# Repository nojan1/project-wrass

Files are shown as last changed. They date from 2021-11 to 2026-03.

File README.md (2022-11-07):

# Project Wrass

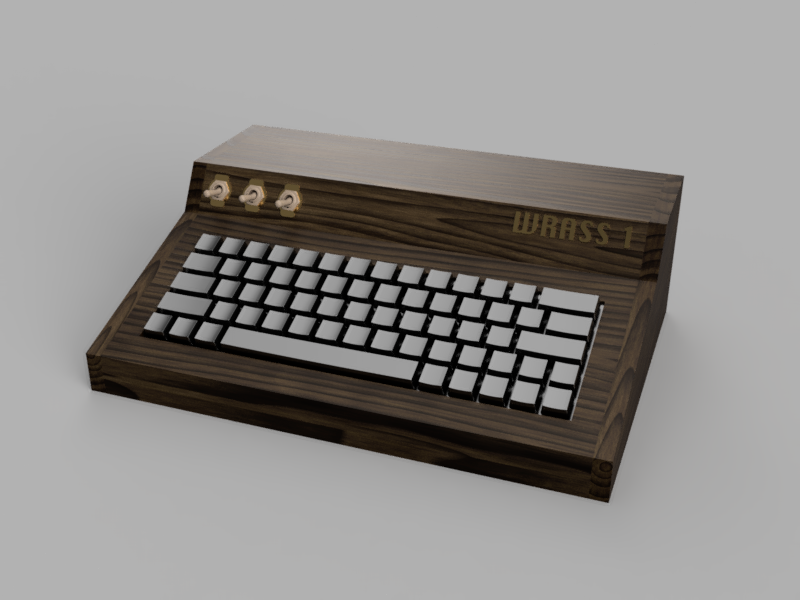
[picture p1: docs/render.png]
render


The purpose of Project Wrass is to develop the **Wrass 1**.

A 6502 based computer having the following specs.

* W65C02 running at 2Mhz
* Bankable RAM giving a total of approx 300KB of usable memory
* Expansion bus for up to 16 devices

> **Future specs**:  
>
> * VGA output of 640x480 with 256 colors
> * IO Card with W65C22 Vias and support for SPI
> * Support for SD cards on IO card
> * 8Mhz CPU clock speed
> * Global scroll registers for video
> * Sprites
> * 3 channel sound synthesizer

## Software

The 16KB ROM is bankable using an external switch. This allows the computer to run "2 sets" of software.

The existing one is a simple homebrew "monitor" giving access to simple read, write and jump commands.

> **Future**:  
> Support enhanced basic

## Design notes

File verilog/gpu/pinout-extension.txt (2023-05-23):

+5   |  GND
+3.3 |  GND
IO0  |  EXTCLK
IO1  |  GND
IO2  |  LED1
IO3  |  LED2
IO4  |  Blue2
IO5  |  Blue1
IO6  |  Blue0
IO7  |  Green2
A0   |  Green1
CLK  |  Green0
A1   |  Red2
A2   |  Red1
RW   |  Red0
CS   |  VSync
RST  |  HSync

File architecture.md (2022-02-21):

Architecture
-------------

# Memory map

| Type | Start | End | Size |
| --- | ----- | ----- | ---- |
| RAM (1) | $0000 | $7FFF | 32k  |
| RAM (2) | $8000 | $9FFF | 8k |
| IO | $A000 | $BFFF | 8k |
| ROM | $C000 | $FFFF | 16k  |
| ------------------- | ----  | ----- | ---  |
| Screen (Write only) | $C000 | ??? | ?? |

# IO

The IO space region is a 8k byte range that is divided up into 16 different IO devices. This yields a total of 16 IO select lines having access to 512 bytes of address space each.

## IO Line Allocation

| Line | Device  | Lower Address | Upper Address |
| ---- | --- | --- | --- |
| 0 | IO Card | $A000 | $A1FF |
| 1 | GPU | $A200 | $A3FF |
| 2 | SOUND | $A400 | $A5FF |
| 3 | | $A600 | $A7FF |
| 4 | | $A800 | $A9FF |
| 5 | | $AA00 | $ABFF |
| 6 | | $AC00 | $ADFF |
| 7 | | $AE00 | $AFFF |
| 8 | | $B000 | $B1FF |
| 9 | | $B200 | $B3FF |
| 10 | | $B400 | $B5FF |
| 11 | | $B600 | $B7FF |
| 12 | | $B800 | $B9FF |
| 13 | | $BA00 | $BBFF |
| 14 | | $BC00 | $BDFF |
| 15 | | $BE00 | $BFFF |

# Screen

The framebuffer, tilemap and color attributes are stored in seperate RAM. It shares address space with ROM however since writing to the ROM is a no-op this action is repurposed to write to screen RAM. Note that that does make the Screen RAM write-only!

To access information about Screen stuff the IO space is used.

## Screen RAM Map (Character mode)

| Type | Lower Address | Upper Address |
| --- | --- | --- |
| Framebuffer | $C000 | $D2C0 |
| Color Attributes | $D2C1 | $E581 |
| Tilemap | $E582 | $ED81 |
| Colors | $ED82 | $EE02 |

### Framebuffer format

The framebuffer is composed of 80 * 60 bytes confirming to 80 columns and 60 rows layed out in row order. Each byte in the buffer matches a single tile in the tilemap. 

### Color Attributes

The color attributes are layed out in the same format as the framebuffer with the difference that each byte instead describes the color for the rendered tile. The lower 4 bits matches to 16 different colors for the background and the top 4 is the color for the foreground.

### Tilemap format

The tilemap is composed of 8 bytes per tile, coresponding to 8 rows. When converting to pixels it is simply 0 == pixel off, 1 == pixel on.

The example below would make a crappy 'A' when rendered.

```
byte 
 0:  0 0 0 0 0 0 0 0
 1:  0 0 0 1 1 0 0 0
 2:  0 0 1 1 1 1 0 0
 3:  0 1 1 0 0 1 1 0
 4:  0 1 1 0 0 1 1 0
 5:  0 1 1 1 1 1 1 0
 6:  0 1 1 1 1 1 1 0
 7:  0 1 1 0 0 1 1 0
```

## Screen RAM Map (Bitmap mode)

| Type | Lower Address | Upper Address |
| --- | --- | --- |
| Bitmap data format | $C000 | $E580 |
| Tilemap | $E582 | $ED81 |
| Colors | $ED82 | $EE02 |

### Bitmap data

The bitmap data is encoded in a 2bp and the screen resolution is reduced to 320x240.
The available colors are the first 4 in the color map.

Example:
```
  00_01_10_11 
```
Would translate to a row of 4 pixels as such:
```
<color 0><color 1><color 2><color 3>
```

## Colors format

The colors are a collection of 16 bytes each describing one of the 16 available colors. The format is: `xxRRGGBB`. Meaning 2 bit for each color and the 2 top bits are ignored.

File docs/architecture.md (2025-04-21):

Architecture
-------------

# Memory map

| Type | Start | End | Size |
| --- | ----- | ----- | --- |
| RAM (1) | $0000 | $7FFF | 32k |
| RAM (2) | $8000 | $9FFF | 8k |
| RAM (3) | $A000 | $BBFF | 7K |
| IO (1) | $BC00 | $BDFF | 512 bytes |
| IO (2) / RAM (4)  | $BE00 | $BFFF | 512 bytes |
| ROM (1) / RAM (5) | $C000 | $DFFF | 8k |
| ROM (2) / RAM (6) | $E000 | $FFFF | 8k |

The different areas marked RAM 3-5 can be switched off by modifying the hardware register located at memory address $0000. It has the following composition:

| Bit | Description |
| --- | --- |
| 0 | Enable RAM (4) |
| 1 | Enable RAM (5) |
| 2 | Enable RAM (6) |
| 3 | RAM (2) bank (bit 0) |
| 4 | RAM (2) bank (bit 1) |
| 5 | RAM (2) bank (bit 2) |
| 6 | RAM (2) bank (bit 3) |
| 7 | RAM (2) bank (bit 4) |

# IO

The IO space region is a 1k byte range that is divided up into 16 different IO devices. This yields a total of 16 IO select lines having access to 64 bytes of address space each. However only IO bank 1 is used by default, giving 8 lines of internal expansion. IO bank 2 is broken out to the user port on the side and will not be decoded,

## IO Line Allocation (1)

| Line | Device  | Lower Address | Upper Address |
| ---- | --- | --- | --- |
| 0 | IO Card | $BC00 | $BC3F |
| 1 | GPU | $BC40 | $BC7F |
| 2 | LCD | $BC80 | $BCBF |
| 3 | | $BCC0 | $BCFF |
| 4 | | $BD00 | $BD3F |
| 5 | | $BD40 | $BD7F |
| 6 | | $BD80 | $BDBF |
| 7 | | $BDC0 | $BDFF |

## IO Line Allocation (2)

IO lines for user expansion

| Line | Device | Lower Address | Upper Address |
| ---- | --- | --- | --- |
| 8 | | $BE00 | $BE3F |
| 9 | | $BE40 | $BE7F |
| 10 | | $BE80 | $BEBF |
| 11 | | $BEC0 | $BEFF |
| 12 | | $BF00 | $BF3F |
| 13 | | $BF40 | $BF7F |
| 14 | | $BF80 | $BFBF |
| 15 | | $BFC0 | $BFFF |

# Reset sequence

During the reset sequence the latch chip controlling the $0000 register is reset to 0. Resulting in all extra RAM banks being switched off. 

Once the 6502 goes to its reset vector and control is handed over to the kernel it will modify it to enable RAM (5). If the user wants to use the external IO it is up to that user to switch off RAM (5) and handle anything that was stored there.

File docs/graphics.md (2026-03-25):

# Graphics

The graphics unit is a separete IO device hooked up to one of the IO lines in the IO address space.

## Registers

| Address | Register name | Description |
| --- | --- | --- |
| $0000 | Control | Used to control the overall operation of the graphics unit |
| $0001 | Y-Offset | Global screen offset for render |
| $0002 | X-Offset | Global screen offset for render |
| $0003 | Increment | After a memory operation using the Read/Write register the address will increment/decrement (control by bit 7) by this much |
| $0004 | Internal address (Low)  | When doing memory access this is the LOW part of the 16 bit address |
| $0005 | Internal address (High) | When doing memory access this is the HIGH part of the 16 bit address |
| $0006 | Read/Write | Performing a write to the is register will write that value to the memory address of ($0004) | ($0005). Performing a read will instead return the value at that location |

# Screen

The framebuffer, tilemap and color attributes are stored in seperate RAM. Writes and reads from this area is done using the registers described above

## Screen RAM Map (Character mode)

| Type | Lower Address | Upper Address |
| --- | --- | --- |
| Framebuffer | $0000 | $1FFF |
| Color Attributes | $2000 | $3FFF |
| Tilemap | $4000 | $47FF |
| Colors | $4800 | $480F |

### Framebuffer format

The framebuffer is composed of 40 * 30 bytes confirming to 40 columns and 30 rows layed out in row order. Each byte in the buffer matches a single tile in the tilemap. 

### Color Attributes

The color attributes are layed out in the same format as the framebuffer with the difference that each byte instead describes the color for the rendered tile. The lower 4 bits matches to 16 different colors for the background and the top 4 is the color for the foreground.

### Tilemap format

The tilemap is composed of 8 bytes per tile, coresponding to 8 rows. When converting to pixels it is simply 0 == pixel off, 1 == pixel on.

The example below would make a crappy 'A' when rendered.

```
byte 
 0:  0 0 0 0 0 0 0 0
 1:  0 0 0 1 1 0 0 0
 2:  0 0 1 1 1 1 0 0
 3:  0 1 1 0 0 1 1 0
 4:  0 1 1 0 0 1 1 0
 5:  0 1 1 1 1 1 1 0
 6:  0 1 1 1 1 1 1 0
 7:  0 1 1 0 0 1 1 0
```

## Screen RAM Map (Bitmap mode)

| Type | Lower Address | Upper Address |
| --- | --- | --- |
| Bitmap data format | $C000 | $E580 |
| Tilemap | $E582 | $ED81 |
| Colors | $ED82 | $EE02 |

### Bitmap data

The bitmap data is encoded in a 2bp and the screen resolution is reduced to 320x240.
The available colors are the first 4 in the color map.

Example:
```
  00_01_10_11 
```
Would translate to a row of 4 pixels as such:
```
<color 0><color 1><color 2><color 3>
```

## Colors format

The colors are a collection of 16 bytes each describing one of the 16 available colors. The format is: `xxRRGGBB`. Meaning 2 bit for each color and the 2 top bits are ignored.

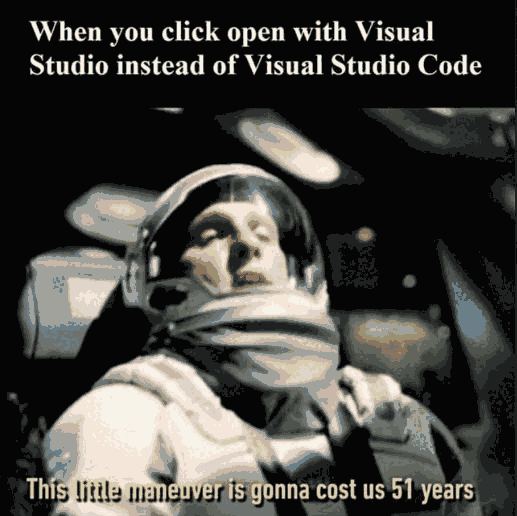
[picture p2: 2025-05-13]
utils/out.png

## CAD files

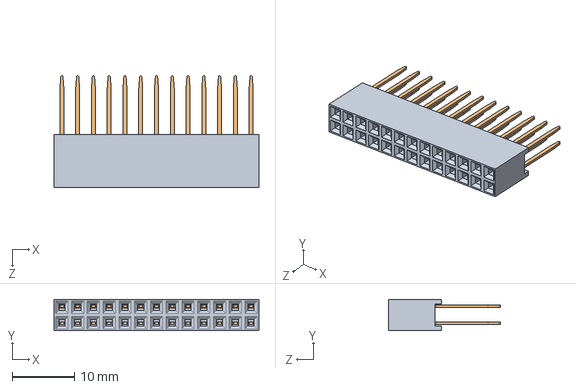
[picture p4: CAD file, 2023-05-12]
eda/all-in-one-smc/13x2_female_header.STEP
33.0 x 5.00 x 18.0 mm
Body_Varsay考an
pin_Varsay考an x 26

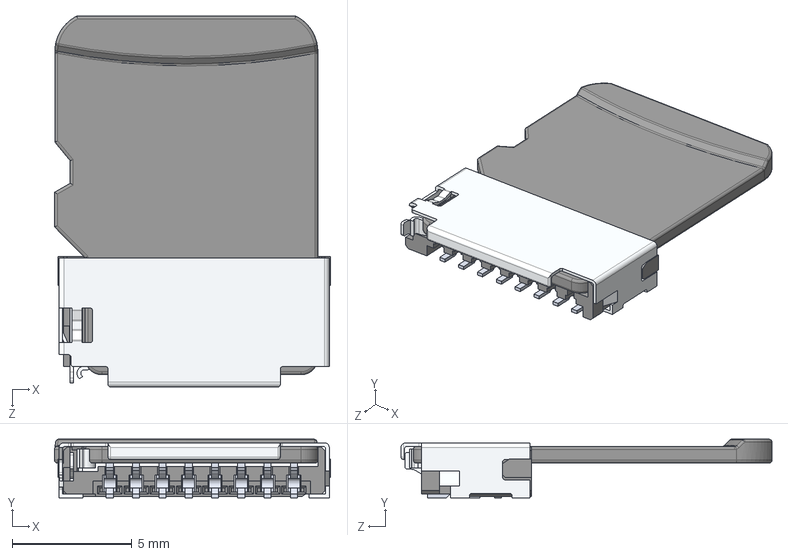
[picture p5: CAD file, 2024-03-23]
eda/all-in-one-smc/47571-0001-with-sdcard.STEP
11.5 x 2.45 x 15.5 mm
microsd

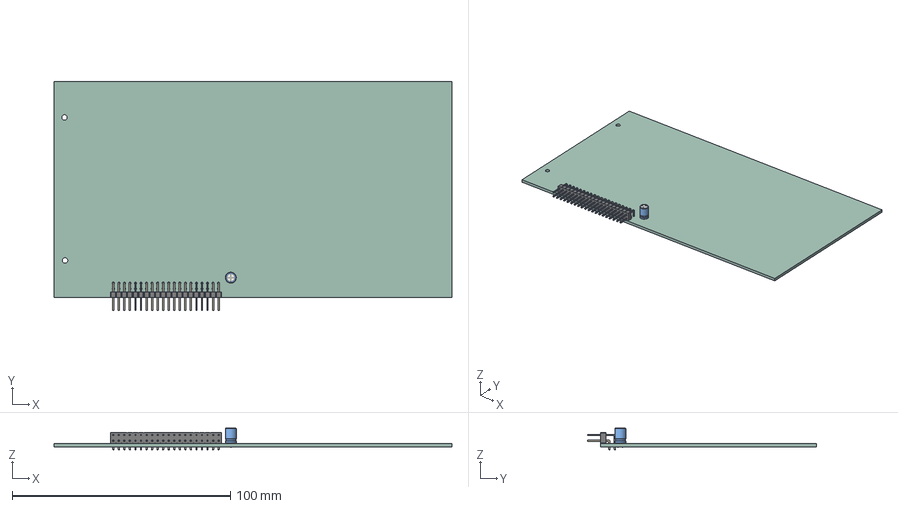
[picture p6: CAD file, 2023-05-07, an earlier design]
eda/expansion_skeleton-v1/expansion_skeleton.step
182.4 x 105.0 x 10.0 mm
PCB

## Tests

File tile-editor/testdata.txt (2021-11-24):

0x00, 0x00, 0x00, 0x00, 0x00, 0x00, 0x00, 0x00   // U+0020 (space)
0x18, 0x3C, 0x3C, 0x18, 0x18, 0x00, 0x18, 0x00   // U+0021 (!)
0x36, 0x36, 0x00, 0x00, 0x00, 0x00, 0x00, 0x00   // U+0022 (")
0x36, 0x36, 0x7F, 0x36, 0x7F, 0x36, 0x36, 0x00   // U+0023 (#)
0x0C, 0x3E, 0x03, 0x1E, 0x30, 0x1F, 0x0C, 0x00   // U+0024 ($)
0x00, 0x63, 0x33, 0x18, 0x0C, 0x66, 0x63, 0x00   // U+0025 (%)
0x1C, 0x36, 0x1C, 0x6E, 0x3B, 0x33, 0x6E, 0x00   // U+0026 (&)
0x06, 0x06, 0x03, 0x00, 0x00, 0x00, 0x00, 0x00   // U+0027 (')
0x18, 0x0C, 0x06, 0x06, 0x06, 0x0C, 0x18, 0x00   // U+0028 (()
0x06, 0x0C, 0x18, 0x18, 0x18, 0x0C, 0x06, 0x00   // U+0029 ())
0x00, 0x66, 0x3C, 0xFF, 0x3C, 0x66, 0x00, 0x00   // U+002A (*)
0x00, 0x0C, 0x0C, 0x3F, 0x0C, 0x0C, 0x00, 0x00   // U+002B (+)
0x00, 0x00, 0x00, 0x00, 0x00, 0x0C, 0x0C, 0x06   // U+002C (,)
0x00, 0x00, 0x00, 0x3F, 0x00, 0x00, 0x00, 0x00   // U+002D (-)
0x00, 0x00, 0x00, 0x00, 0x00, 0x0C, 0x0C, 0x00   // U+002E (.)
0x60, 0x30, 0x18, 0x0C, 0x06, 0x03, 0x01, 0x00   // U+002F (/)
0x3E, 0x63, 0x73, 0x7B, 0x6F, 0x67, 0x3E, 0x00   // U+0030 (0)
0x0C, 0x0E, 0x0C, 0x0C, 0x0C, 0x0C, 0x3F, 0x00   // U+0031 (1)
0x1E, 0x33, 0x30, 0x1C, 0x06, 0x33, 0x3F, 0x00   // U+0032 (2)
0x1E, 0x33, 0x30, 0x1C, 0x30, 0x33, 0x1E, 0x00   // U+0033 (3)
0x38, 0x3C, 0x36, 0x33, 0x7F, 0x30, 0x78, 0x00   // U+0034 (4)
0x3F, 0x03, 0x1F, 0x30, 0x30, 0x33, 0x1E, 0x00   // U+0035 (5)
0x1C, 0x06, 0x03, 0x1F, 0x33, 0x33, 0x1E, 0x00   // U+0036 (6)
0x3F, 0x33, 0x30, 0x18, 0x0C, 0x0C, 0x0C, 0x00   // U+0037 (7)
0x1E, 0x33, 0x33, 0x1E, 0x33, 0x33, 0x1E, 0x00   // U+0038 (8)
0x1E, 0x33, 0x33, 0x3E, 0x30, 0x18, 0x0E, 0x00   // U+0039 (9)
0x00, 0x0C, 0x0C, 0x00, 0x00, 0x0C, 0x0C, 0x00   // U+003A (:)
0x00, 0x0C, 0x0C, 0x00, 0x00, 0x0C, 0x0C, 0x06   // U+003B (;)
0x18, 0x0C, 0x06, 0x03, 0x06, 0x0C, 0x18, 0x00   // U+003C (<)
0x00, 0x00, 0x3F, 0x00, 0x00, 0x3F, 0x00, 0x00   // U+003D (=)
0x06, 0x0C, 0x18, 0x30, 0x18, 0x0C, 0x06, 0x00   // U+003E (>)
0x1E, 0x33, 0x30, 0x18, 0x0C, 0x00, 0x0C, 0x00   // U+003F (?)
0x3E, 0x63, 0x7B, 0x7B, 0x7B, 0x03, 0x1E, 0x00   // U+0040 (@)
0x0C, 0x1E, 0x33, 0x33, 0x3F, 0x33, 0x33, 0x00   // U+0041 (A)
0x3F, 0x66, 0x66, 0x3E, 0x66, 0x66, 0x3F, 0x00   // U+0042 (B)
0x3C, 0x66, 0x03, 0x03, 0x03, 0x66, 0x3C, 0x00   // U+0043 (C)
0x1F, 0x36, 0x66, 0x66, 0x66, 0x36, 0x1F, 0x00   // U+0044 (D)
0x7F, 0x46, 0x16, 0x1E, 0x16, 0x46, 0x7F, 0x00   // U+0045 (E)
0x7F, 0x46, 0x16, 0x1E, 0x16, 0x06, 0x0F, 0x00   // U+0046 (F)
0x3C, 0x66, 0x03, 0x03, 0x73, 0x66, 0x7C, 0x00   // U+0047 (G)
0x33, 0x33, 0x33, 0x3F, 0x33, 0x33, 0x33, 0x00   // U+0048 (H)
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

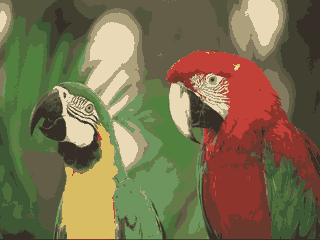
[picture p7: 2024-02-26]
testfiles/images/quantized.png

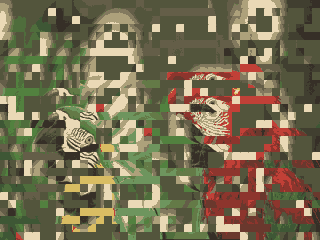
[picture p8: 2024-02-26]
testfiles/images/output.png

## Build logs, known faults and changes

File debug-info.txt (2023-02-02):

Expected tile ids:
0, 1, 2, 3, 4, 5, 6, 7, 8, 9, a, b, c, d, e, f, 10, 11, 12, 13, 14, 15, 16, 17, 18, 19, 1a, 1b, 1c, 1d, 1e, 1f, 20, 21, 22, 23, 24, 25, 26, 27, 28, 29, 2a, 2b, 2c, 2d, 2e, 2f, 30, 31, 32, 33, 34, 35, 36, 37, 38, 39, 3a, 3b, 3c, 3d, 3e, 3f, 40, 41, 42, 43, 44, 45, 46, 47, 48, 49, 4a, 4b, 4c, 4d, 4e, 4f, 50, 51, 52, 53, 54, 55, 56, 57, 58, 59, 5a, 5b, 5c, 5d, 5e, 5f, 60, 61, 62, 63, 64, 65, 66, 67, 68, 69, 6a, 6b, 6c, 6d, 6e, 6f, 70, 71, 72, 73, 74, 75, 76, 77, 78, 79, 7a, 7b, 7c, 7d, 7e, 7f, 80, 81, 82, 83, 84, 85, 86, 87, 88, 89, 8a, 8b, 8c, 8d, 8e, 8f, 90, 91, 92, 93, 94, 95, 96, 97, 98, 99, 9a, 9b, 9c, 9d, 9e, 9f, a0, a1, a2, a3, a4, a5, a6, a7, a8, a9, aa, ab, ac, ad, ae, af, b0, b1, b2, b3, b4, b5, b6, b7, b8, b9, ba, bb, bc, bd, be, bf, c0, c1, c2, c3, c4, c5, c6, c7, c8, c9, ca, cb, cc, cd, ce, cf, d0, d1, d2, d3, d4, d5, d6, d7, d8, d9, da, db, dc, dd, de, df, e0, e1, e2, e3, e4, e5, e6, e7, e8, e9, ea, eb, ec, ed, ee, ef, f0, f1, f2, f3, f4, f5, f6, f7, f8, f9, fa, fb, fc, fd, fe, ff

Expected color attributes:
10, 20, 30, 40, 50, 60, 70, 80, 90, a0, b0, c0, d0, e0, f0, 10, 20, 30, 40, 50, 60, 70, 80, 90, a0, b0, c0, d0, e0, f0, 10, 20, 30, 40, 50, 60, 70, 80, 90, a0, b0, c0, d0, e0, f0, 10, 20, 30, 40, 50, 60, 70, 80, 90, a0, b0, c0, d0, e0, f0, 10, 20, 30, 40, 50, 60, 70, 80, 90, a0, b0, c0, d0, e0, f0, 10, 20, 30, 40, 50, 60, 70, 80, 90, a0, b0, c0, d0, e0, f0, 10, 20, 30, 40, 50, 60, 70, 80, 90, a0, b0, c0, d0, e0, f0, 10, 20, 30, 40, 50, 60, 70, 80, 90, a0, b0, c0, d0, e0, f0, 10, 20, 30, 40, 50, 60, 70, 80, 10, 20, 30, 40, 50, 60, 70, 80, 90, a0, b0, c0, d0, e0, f0, 10, 20, 30, 40, 50, 60, 70, 80, 90, a0, b0, c0, d0, e0, f0, 10, 20, 30, 40, 50, 60, 70, 80, 90, a0, b0, c0, d0, e0, f0, 10, 20, 30, 40, 50, 60, 70, 80, 90, a0, b0, c0, d0, e0, f0, 10, 20, 30, 40, 50, 60, 70, 80, 90, a0, b0, c0, d0, e0, f0, 10, 20, 30, 40, 50, 60, 70, 80, 90, a0, b0, c0, d0, e0, f0, 10, 20, 30, 40, 50, 60, 70, 80, 90, a0, b0, c0, d0, e0, f0, 10, 20, 30, 40, 50, 60, 70, 80, 90, a0, b0, c0, d0, e0, f0, 10, 20, 30, 40, 50, 60, 70, 80

Title data:
0	18	36	36	c	0	1c	6	18	6	0	0	0	0	0	60	3e	c	1e	1e	38	3f	1c	3f	1e	1e	0	0	18	0	6	1e	3e	c	3f	3c	1f	7f	7f	3c	33	1e	78	67	f	63	63	1c	3f	1e	3f	1e	3f	33	33	63	63	33	7f	1e	3	1e	8	0	c	0	7	0	38	0	1c	0	7	c	30	7	e	0	0	0	0	0	0	0	8	0	0	0	0	0	0	38	18	7	6e	80	1	81	0	0	0	24	24	24	24	30	18	0	0	0	0	0	0	0	0	0	0	0	0	0	0	0	0	0	0	0	0	0	ff	e7	c9	c9	f3	ff	e3	f9	e7	f9	ff	ff	ff	ff	ff	9f	c1	f3	e1	e1	c7	c0	e3	c0	e1	e1	ff	ff	e7	ff	f9	e1	c1	f3	c0	c3	e0	80	80	c3	cc	e1	87	98	f0	9c	9c	e3	c0	e1	c0	e1	c0	cc	cc	9c	9c	cc	80	e1	fc	e1	f7	ff	f3	ff	f8	ff	c7	ff	e3	ff	f8	f3	cf	f8	f1	ff	ff	ff	ff	ff	ff	ff	f7	ff	ff	ff	ff	ff	ff	c7	e7	f8	91	7f	fe	7e	ff	ff	ff	db	db	db	db	cf	e7	ff	ff	ff	ff	ff	ff	ff	ff	ff	ff	ff	ff	ff	ff	ff	ff	ff	ff	ff	ff	ff
0	3c	36	36	3e	63	36	6	c	c	66	c	0	0	0	30	63	e	33	33	3c	3	6	33	33	33	c	c	c	0	c	33	63	1e	66	66	36	46	46	66	33	c	30	66	6	77	67	36	66	33	66	33	2d	33	33	63	63	33	63	6	6	18	1c	0	c	0	6	0	30	0	36	0	6	0	0	6	c	0	0	0	0	0	0	0	c	0	0	0	0	0	0	c	18	c	3b	40	2	42	0	0	0	24	24	24	24	58	1c	66	0	0	0	0	0	0	0	0	0	0	0	0	0	0	0	0	0	0	0	0	ff	c3	c9	c9	c1	9c	c9	f9	f3	f3	99	f3	ff	ff	ff	cf	9c	f1	cc	cc	c3	fc	f9	cc	cc	cc	f3	f3	f3	ff	f3	cc	9c	e1	99	99	c9	b9	b9	99	cc	f3	cf	99	f9	88	98	c9	99	cc	99	cc	d2	cc	cc	9c	9c	cc	9c	f9	f9	e7	e3	ff	f3	ff	f9	ff	cf	ff	c9	ff	f9	ff	ff	f9	f3	ff	ff	ff	ff	ff	ff	ff	f3	ff	ff	ff	ff	ff	ff	f3	e7	f3	c4	bf	fd	bd	ff	ff	ff	db	db	db	db	a7	e3	99	ff	ff	ff	ff	ff	ff	ff	ff	ff	ff	ff	ff	ff	ff	ff	ff	ff	ff	ff	ff
0	3c	0	7f	3	33	1c	3	6	18	3c	c	0	0	0	18	73	c	30	30	36	1f	3	30	33	33	c	c	6	3f	18	30	7b	33	66	3	66	16	16	3	33	c	30	36	6	7f	6f	63	66	33	66	7	c	33	33	63	36	33	31	6	c	18	36	0	18	1e	6	1e	30	1e	6	6e	36	e	30	66	c	33	1f	1e	3b	6e	3b	3e	3e	33	33	63	63	33	3f	c	18	c	0	20	4	24	f0	ff	f	24	e7	e4	27	3c	3e	99	0	0	0	0	0	0	0	0	0	0	0	0	0	0	0	0	0	0	0	0	ff	c3	ff	80	fc	cc	e3	fc	f9	e7	c3	f3	ff	ff	ff	e7	8c	f3	cf	cf	c9	e0	fc	cf	cc	cc	f3	f3	f9	c0	e7	cf	84	cc	99	fc	99	e9	e9	fc	cc	f3	cf	c9	f9	80	90	9c	99	cc	99	f8	f3	cc	cc	9c	c9	cc	ce	f9	f3	e7	c9	ff	e7	e1	f9	e1	cf	e1	f9	91	c9	f1	cf	99	f3	cc	e0	e1	c4	91	c4	c1	c1	cc	cc	9c	9c	cc	c0	f3	e7	f3	ff	df	fb	db	f	0	f0	db	18	1b	d8	c3	c1	66	ff	ff	ff	ff	ff	ff	ff	ff	ff	ff	ff	ff	ff	ff	ff	ff	ff	ff	ff	ff
0	18	0	36	1e	18	6e	0	6	18	ff	3f	0	3f	0	c	7b	c	1c	1c	33	30	1f	18	1e	3e	0	0	3	0	30	18	7b	33	3e	3	66	1e	1e	3	3f	c	30	1e	6	7f	7b	63	3e	33	3e	e	c	33	33	6b	1c	1e	18	6	18	18	63	0	0	30	3e	33	3e	33	f	33	6e	c	30	36	c	7f	33	33	66	33	6e	3	c	33	33	6b	36	33	19	7	0	38	0	10	8	18	8	0	10	24	0	4	20	76	f6	81	0	0	0	0	0	0	0	0	0	0	0	0	0	0	0	0	0	0	0	0	ff	e7	ff	c9	e1	e7	91	ff	f9	e7	0	c0	ff	c0	ff	f3	84	f3	e3	e3	cc	cf	e0	e7	e1	c1	ff	ff	fc	ff	cf	e7	84	cc	c1	fc	99	e1	e1	fc	c0	f3	cf	e1	f9	80	84	9c	c1	cc	c1	f1	f3	cc	cc	94	e3	e1	e7	f9	e7	e7	9c	ff	ff	cf	c1	cc	c1	cc	f0	cc	91	f3	cf	c9	f3	80	cc	cc	99	cc	91	fc	f3	cc	cc	94	c9	cc	e6	f8	ff	c7	ff	ef	f7	e7	f7	ff	ef	db	ff	fb	df	89	9	7e	ff	ff	ff	ff	ff	ff	ff	ff	ff	ff	ff	ff	ff	ff	ff	ff	ff	ff	ff	ff
0	18	0	7f	30	c	3b	0	6	18	3c	c	0	0	0	6	6f	c	6	30	7f	30	33	c	33	30	0	0	6	0	18	c	7b	3f	66	3	66	16	16	73	33	c	33	36	46	6b	73	63	6	3b	36	38	c	33	33	7f	1c	c	4c	6	30	18	0	0	0	3e	66	3	33	3f	6	33	66	c	30	1e	c	7f	33	33	66	33	66	1e	c	33	33	7f	1c	33	c	c	18	c	0	8	10	18	4	0	20	24	0	8	10	7e	e8	42	0	0	0	0	0	0	0	0	0	0	0	0	0	0	0	0	0	0	0	0	ff	e7	ff	80	cf	f3	c4	ff	f9	e7	c3	f3	ff	ff	ff	f9	90	f3	f9	cf	80	cf	cc	f3	cc	cf	ff	ff	f9	ff	e7	f3	84	c0	99	fc	99	e9	e9	8c	cc	f3	cc	c9	b9	94	8c	9c	f9	c4	c9	c7	f3	cc	cc	80	e3	f3	b3	f9	cf	e7	ff	ff	ff	c1	99	fc	cc	c0	f9	cc	99	f3	cf	e1	f3	80	cc	cc	99	cc	99	e1	f3	cc	cc	80	e3	cc	f3	f3	e7	f3	ff	f7	ef	e7	fb	ff	df	db	ff	f7	ef	81	17	bd	ff	ff	ff	ff	ff	ff	ff	ff	ff	ff	ff	ff	ff	ff	ff	ff	ff	ff	ff	ff
0	0	0	36	1f	66	33	0	c	c	66	c	c	0	c	3	67	c	33	33	30	33	33	c	33	18	c	c	c	3f	c	0	3	33	66	66	36	46	6	66	33	c	33	66	66	63	63	36	6	1e	66	33	c	33	1e	77	36	c	66	6	60	18	0	0	0	33	66	33	33	3	6	3e	66	c	33	36	c	6b	33	33	3e	3e	6	30	2c	33	1e	7f	36	3e	26	c	18	c	0	4	20	24	e4	ff	27	24	e7	f0	f	7e	64	24	0	0	0	0	0	0	0	0	0	0	0	0	0	0	0	0	0	0	0	0	ff	ff	ff	c9	e0	99	cc	ff	f3	f3	99	f3	f3	ff	f3	fc	98	f3	cc	cc	cf	cc	cc	f3	cc	e7	f3	f3	f3	c0	f3	ff	fc	cc	99	99	c9	b9	f9	99	cc	f3	cc	99	99	9c	9c	c9	f9	e1	99	cc	f3	cc	e1	88	c9	f3	99	f9	9f	e7	ff	ff	ff	cc	99	cc	cc	fc	f9	c1	99	f3	cc	c9	f3	94	cc	cc	c1	c1	f9	cf	d3	cc	e1	80	c9	c1	d9	f3	e7	f3	ff	fb	df	db	1b	0	d8	db	18	f	f0	81	9b	db	ff	ff	ff	ff	ff	ff	ff	ff	ff	ff	ff	ff	ff	ff	ff	ff	ff	ff	ff	ff
0	18	0	36	c	63	6e	0	18	6	0	0	c	0	c	1	3e	3f	3f	1e	78	1e	1e	c	1e	e	c	c	18	0	6	c	1e	33	3f	3c	1f	7f	f	7c	33	1e	1e	67	7f	63	63	1c	f	38	67	1e	1e	3f	c	63	63	1e	7f	1e	40	1e	0	0	0	6e	3b	1e	6e	1e	f	30	67	1e	33	67	1e	63	33	1e	6	30	f	1f	18	6e	c	36	63	30	3f	38	18	7	0	2	40	42	24	0	24	24	24	0	0	3c	2	18	0	0	0	0	0	0	0	0	0	0	0	0	0	0	0	0	0	0	0	0	ff	e7	ff	c9	f3	9c	91	ff	e7	f9	ff	ff	f3	ff	f3	fe	c1	c0	c0	e1	87	e1	e1	f3	e1	f1	f3	f3	e7	ff	f9	f3	e1	cc	c0	c3	e0	80	f0	83	cc	e1	e1	98	80	9c	9c	e3	f0	c7	98	e1	e1	c0	f3	9c	9c	e1	80	e1	bf	e1	ff	ff	ff	91	c4	e1	91	e1	f0	cf	98	e1	cc	98	e1	9c	cc	e1	f9	cf	f0	e0	e7	91	f3	c9	9c	cf	c0	c7	e7	f8	ff	fd	bf	bd	db	ff	db	db	db	ff	ff	c3	fd	e7	ff	ff	ff	ff	ff	ff	ff	ff	ff	ff	ff	ff	ff	ff	ff	ff	ff	ff	ff	ff
0	0	0	0	0	0	0	0	0	0	0	0	6	0	0	0	0	0	0	0	0	0	0	0	0	0	0	6	0	0	0	0	0	0	0	0	0	0	0	0	0	0	0	0	0	0	0	0	0	0	0	0	0	0	0	0	0	0	0	0	0	0	0	ff	0	0	0	0	0	0	0	1f	0	0	1e	0	0	0	0	0	f	78	0	0	0	0	0	0	0	1f	0	0	0	0	0	1	80	81	24	0	24	24	24	0	0	18	1	0	0	0	0	0	0	0	0	0	0	0	0	0	0	0	0	0	0	0	0	0	ff	ff	ff	ff	ff	ff	ff	ff	ff	ff	ff	ff	f9	ff	ff	ff	ff	ff	ff	ff	ff	ff	ff	ff	ff	ff	ff	f9	ff	ff	ff	ff	ff	ff	ff	ff	ff	ff	ff	ff	ff	ff	ff	ff	ff	ff	ff	ff	ff	ff	ff	ff	ff	ff	ff	ff	ff	ff	ff	ff	ff	ff	ff	0	ff	ff	ff	ff	ff	ff	ff	e0	ff	ff	e1	ff	ff	ff	ff	ff	f0	87	ff	ff	ff	ff	ff	ff	ff	e0	ff	ff	ff	ff	ff	fe	7f	7e	db	ff	db	db	db	ff	ff	e7	fe	ff	ff	ff	ff	ff	ff	ff	ff	ff	ff	ff	ff	ff	ff	ff	ff	ff	ff	ff	ff	ff

Output color:
0	0	0	0	0	0	0	0	0	0	0	d2	d2	0	0	0	0	d6	d6	0	d6	d6	0	0	0	d2	d2	0	d2	d2	0	0	0	0	92	92	0	0	0	0	0	0	0	0	0	0	0	0	0	0	b6	b6	b6	0	0	0	0	d0	d0	0	0	0	0	0	0	0	0	90	90	0	0	0	0	9a	9a	0	0	0	0	0	0	0	0	0	0	0	0	0	0	0	0	0	0	0	0	0	0	0	0	0	0	0	0	0	0	0	0	0	0	0	0	0	0	0	0	0	0	0	0	0	0	0	0	0	0	ff	ff	0	0	d2	d2	d2	d2	d2	0	0	0	0	d6	d6	0	0	0	0	0	d2	d2	d2	d2	0	0	0	0	92	92	92	92	0	0	0	0	0	0	92	92	92	0	0	b6	b6	b6	b6	b6	b6	0	0	0	0	d0	d0	d0	0	0	0	90	90	90	90	90	90	0	0	0	9a	9a	9a	9a	0	0	0	0	92	92	92	92	0	0	0	0	0	0	0	0	0	0	0	0	0	0	0	0	0	0	0	0	0	0	da	da	0	0	0	0	0	0	0	0	0	0	0	0	ff	ff	0	0	0	0	0	0	d2	d2	d2	d2	0	0	0	0	d6	d6	d6	d6	d6	0	0	0	0	d2	d2	0	0	0	0	92	92	92	92	92	92	0	0	0	0	92	92	92	92	0	0	b6	b6	b6	b6	b6	0	0	0	d0	d0	d0	d0	d0	d0	d0	0	90	90	90	90	90	90	90	0	0	0	9a	9a	9a	9a	0	0	92	92	0	0	92	92	0	0	0	da	da	da	da	0	0	0	0	0	0	9a	9a	9a	9a	0	da	da	da	0	0	da	da	0	92	92	92	92	0	0	0	0	ff	ff	0	0	0	ff	ff	0	d2	d2	0	0	0	d2	d2	0	0	0	d6	d6	d6	0	0	0	d2	d2	d2	d2	d2	d2	0	0	0	92	92	92	92	0	0	0	92	92	92	92	92	92	0	0	0	b6	b6	b6	b6	0	0	0	d0	d0	d0	d0	d0	d0	0	0	90	90	0	0	90	90	0	0	9a	9a	0	0	9a	9a	0	0	92	92	0	0	0	92	92	0	da	da	0	0	0	da	da	0	9a	9a	0	0	9a	9a	0	0	da	da	da	da	da	da	da	0	0	92	92	92	92	0	0	0	ff	ff	0	0	0	0	0	0	0	d2	d2	d2	d2	0	0	0	0	0	0	d6	0	0	0	0	0	0	0	0	0	0	0	0	0	0	92	92	0	0	0	0	0	0	0	0	0	0	0	0	b6	b6	b6	0	0	0	0	0	0	0	0	0	0	0	0	0	0	0	0	90	90	90	0	0	0	0	0	0	0	0	0	0	0	0	92	92	92	0	0	0	0	0	0	0	0	0	0	0	9a	9a	9a	0	0	0	0	0	0	0	da	da	0	0	0	0	0	0	0	0	92	92	0	0	ff	ff	ff	0	0	0	0	0	0	d2	d2	d2	0	0	0	0	0	0	0	0	0	0	0	0	0	0	0	0	0	0	0	0	0	0	0	0	0	0	0	0	0	0	0	0	0	0	0	0	0	0	0	0	0	0	0	0	0	0	0	0	0	0	0	0	0	0	0	0	0	0	0	0	0	0	0	9a	0	0	0	0	0	0	0	0	0	0	0	0	0	0	0	0	0	0	0	0	0	0	0	0	0	0	0	0	0	0	0	0	0	0	0	0	0	0	0	0	0	0	0	0	0	0	0	0	0	0	0	0	0	0	0	d2	d2	d2	0	0	0	0	0	d6	d6	0	0	0	d2	d2	d2	0	0	0	0	0	0	92	92	92	0	92	92	0	0	0	0	0	0	0	0	92	b6	0	0	0	0	0	0	0	d0	0	0	0	0	0	0	d0	0	0	0	0	0	0	0	0	0	0	0	0	0	0	0	0	0	0	0	0	0	0	0	0	0	0	da	0	0	da	0	0	0	0	9a	0	0	9a	0	0	0	0	da	0	0	da	0	0	0	0	92	0	0	92	0	0	0	0	0	0	ff	ff	0	0	0	0	0	d2	d2	0	0	0	0	0	0	0	0	0	0	0	0	0	0	0	0	0	0	0	0	0	0	0	0	0	0	0	0	0	0	0	0	0	0	0	0	0	0	0	0	0	0	0	0	0	0	0	0	0	0	0	0	0	0	0	0	0	0	0	0	0	0	0	0	0	0	0	0	0	0	0	0	0	0	0	0	0	0	0	0	0	0	0	0	0	0	0	0	0	0	0	0	0	0	0	0	0	0	0	0	0	0	0	0	0	0	0	0	0	0	0	0	0	0	0	0	0	0	0	0	0	0	0	0	0	0	0	0	0	0	0	0	0	0	0	0	0	0	0	0	0	0	0	0	0	0	0	0	0	0	0	0	0	0	0	0	0	0	0	0	0	0	0	0	0	0	0	0	0	0	0	ff	ff	ff	ff	ff	ff	ff	ff	d2	d2	d2	0	0	d2	d2	d2	d6	0	0	d6	0	0	d6	d6	d2	0	0	d2	0	0	d2	d2	92	92	0	0	92	92	92	92	92	92	92	92	92	92	92	92	b6	b6	0	0	0	b6	b6	b6	d0	0	0	d0	d0	d0	d0	d0	90	90	90	0	0	90	90	90	9a	0	0	9a	9a	9a	9a	9a	92	92	92	92	92	92	92	92	da	da	da	da	da	da	da	da	9a	9a	9a	9a	9a	9a	9a	9a	da	da	da	da	da	da	da	da	92	92	92	92	92	92	92	92	ff	ff	ff	ff	ff	0	0	ff	d2	0	0	0	0	0	d2	d2	d6	d6	0	0	d6	d6	d6	d6	d2	0	0	0	0	d2	d2	d2	92	0	0	0	0	92	92	92	92	92	92	0	0	0	92	92	0	0	0	0	0	0	b6	b6	d0	d0	0	0	0	d0	d0	d0	0	0	0	0	0	0	90	90	9a	0	0	0	0	9a	9a	9a	92	0	0	0	0	92	92	92	da	da	da	da	da	da	da	da	9a	9a	9a	9a	9a	9a	9a	9a	da	da	da	0	0	da	da	da	92	92	92	92	92	92	92	92	ff	0	0	ff	ff	ff	ff	ff	d2	0	0	0	0	d2	d2	d2	d6	0	0	0	0	0	d6	d6	d2	d2	0	0	d2	d2	d2	d2	0	0	0	0	0	0	92	92	92	92	0	0	0	0	92	92	0	0	0	0	0	b6	b6	b6	0	0	0	0	0	0	0	d0	0	0	0	0	0	0	0	90	9a	9a	0	0	0	0	9a	9a	0	0	92	92	0	0	92	92	da	0	0	0	0	da	da	da	9a	9a	9a	0	0	0	0	9a	0	0	0	da	da	0	0	da	0	0	0	0	92	92	92	92	0	0	ff	ff	ff	0	0	ff	0	0	d2	d2	d2	0	0	d2	d6	d6	0	0	0	d6	d6	d6	0	0	0	0	0	0	d2	d2	92	0	0	0	0	92	92	92	0	0	0	0	0	0	92	92	b6	0	0	0	0	b6	b6	b6	0	0	0	0	0	0	d0	d0	0	0	90	90	0	0	90	90	0	0	9a	9a	0	0	9a	9a	0	0	92	92	92	0	0	92	0	0	da	da	da	0	0	da	0	0	9a	9a	0	0	9a	9a	0	0	0	0	0	0	0	da	92	0	0	0	0	92	92	92	0	0	ff	ff	ff	ff	ff	ff	d2	0	0	0	0	d2	d2	d2	d6	d6	d6	0	d6	d6	d6	d6	d2	d2	d2	d2	d2	d2	d2	d2	92	92	0	0	92	92	92	92	92	92	92	92	92	92	92	92	0	0	0	b6	b6	b6	b6	b6	d0	d0	d0	d0	d0	d0	d0	d0	90	90	90	0	0	0	90	90	9a	9a	9a	9a	9a	9a	9a	9a	92	92	0	0	0	92	92	92	da	da	da	da	da	da	da	da	0	0	0	9a	9a	9a	9a	9a	da	da	0	0	da	da	da	da	92	92	92	92	0	0	92	92	0	0	0	ff	ff	ff	ff	ff	d2	0	0	0	d2	d2	d2	d2	d6	d6	d6	d6	d6	d6	d6	d6	d2	d2	d2	d2	d2	d2	d2	d2	92	92	92	92	92	92	92	92	92	92	92	92	92	92	92	92	b6	b6	b6	b6	b6	b6	b6	b6	d0	d0	d0	d0	d0	d0	d0	d0	90	90	90	90	90	90	90	90	9a	9a	9a	0	9a	9a	9a	9a	92	92	92	92	92	92	92	92	da	da	da	da	da	da	da	da	9a	9a	9a	9a	9a	9a	9a	9a	da	da	da	da	da	da	da	da	92	92	92	92	92	92	92	92	ff	ff	ff	ff	ff	ff	ff	ff	d2	d2	d2	0	0	0	d2	d2	d6	d6	d6	0	0	d6	d6	d6	0	0	0	d2	d2	d2	d2	d2	92	0	0	0	92	0	0	92	92	92	92	92	92	92	92	0	0	b6	b6	b6	b6	b6	b6	b6	0	d0	d0	d0	d0	d0	d0	0	90	90	90	90	90	90	90	90	9a	9a	9a	9a	9a	9a	9a	9a	92	92	92	92	92	92	92	92	da	da	0	da	da	0	da	da	9a	9a	0	9a	9a	0	9a	9a	da	da	0	da	da	0	da	da	92	92	0	92	92	0	92	92	ff	ff	ff	ff	0	0	ff	ff	d2	d2	d2	0	0	d2	d2	d2	d6	d6	d6	d6	d6	d6	d6	d6	d2	d2	d2	d2	d2	d2	d2	d2	92	92	92	92	92	92	92	92	92	92	92	92	92	92	92	92	b6	b6	b6	b6	b6	b6	b6	b6	d0	d0	d0	d0	d0	d0	d0	d0	90	90	90	90	90	90	90	90	9a	9a	9a	9a	9a	9a	9a	9a	92	92	92	92	92	92	92	92	da	da	da	da	da	da	da	da	9a	9a	9a	9a	9a	9a	9a	9a	da	da	da	da	da	da	da	da	92	92	92	92	92	92	92	92	ff	ff	ff	ff	ff	ff	ff	ff	d2	d2	d2	d2	d2	d2	d2	d2	d6	d6	d6	d6	d6	d6	d6	d6	d2	d2	d2	d2	d2	d2	d2	d2	92	92	92	92	92	92	92	92	92	92	92	92	92	92	92	92	b6	b6	b6	b6	b6	b6	b6	b6	d0	d0	d0	d0	d0	d0	d0	d0
0	0	0	0	0	0	0	0	0	0	d2	d2	d2	d2	0	0	0	d6	d6	0	d6	d6	0	0	0	d2	d2	0	d2	d2	0	0	0	92	92	92	92	92	0	0	92	92	0	0	0	92	92	0	0	b6	b6	0	b6	b6	0	0	0	d0	d0	0	0	0	0	0	0	0	90	90	0	0	0	0	0	0	9a	9a	0	0	0	0	0	92	92	0	0	92	92	0	0	0	da	da	0	0	0	0	0	0	0	0	0	0	0	0	0	0	0	0	0	0	0	0	0	0	0	0	0	0	0	0	0	0	0	0	ff	ff	0	0	d2	d2	0	0	0	d2	d2	0	0	d6	d6	d6	0	0	0	0	d2	d2	0	0	d2	d2	0	0	92	92	0	0	92	92	0	0	0	0	92	92	92	92	0	0	b6	b6	0	0	0	0	0	0	0	d0	d0	0	0	0	0	0	90	90	0	0	90	90	0	0	9a	9a	0	0	9a	9a	0	0	92	92	0	0	92	92	0	0	0	0	da	da	0	0	0	0	0	0	9a	9a	0	0	0	0	0	0	da	da	0	0	0	0	0	0	0	0	0	0	0	0	0	0	ff	ff	0	0	0	0	d2	d2	0	0	d2	d2	0	0	d6	d6	0	0	0	d6	d6	0	0	d2	d2	d2	d2	0	0	0	0	92	92	0	0	92	92	0	0	92	92	0	0	92	92	0	0	b6	b6	0	b6	b6	0	0	0	d0	d0	0	0	0	d0	0	0	90	90	0	0	0	90	0	0	9a	9a	0	0	9a	9a	0	92	92	0	0	92	92	0	0	0	0	da	da	0	0	0	0	0	0	0	0	9a	9a	0	0	0	da	da	0	0	da	da	0	0	92	92	0	0	0	0	0	ff	ff	ff	0	ff	ff	ff	0	d2	d2	d2	0	0	d2	d2	0	0	d6	d6	0	d6	d6	0	0	0	d2	d2	0	0	d2	d2	0	92	92	0	0	92	92	0	0	0	92	92	0	0	92	92	0	b6	b6	0	0	b6	b6	0	0	d0	0	d0	d0	0	d0	0	0	90	90	0	0	90	90	0	0	9a	9a	0	0	9a	9a	0	0	92	92	0	0	0	92	92	0	da	da	0	0	0	da	da	0	9a	9a	0	0	9a	9a	0	0	da	da	0	0	0	da	da	0	0	92	92	0	0	0	0	0	0	ff	ff	0	0	0	0	0	0	0	0	d2	d2	0	0	0	0	0	d6	d6	d6	0	0	0	0	0	0	0	0	0	0	0	0	0	92	92	0	0	0	0	0	0	0	0	0	0	0	0	0	b6	b6	0	0	0	0	0	0	0	0	0	0	0	0	0	0	0	0	0	90	90	0	0	0	0	0	0	0	0	0	0	0	92	92	0	92	92	0	0	0	0	0	0	0	0	0	0	0	9a	9a	0	0	0	0	0	0	0	0	0	0	0	0	0	0	0	0	0	0	0	0	0	0	ff	ff	0	0	0	0	0	0	0	d2	d2	0	0	0	0	0	0	0	0	0	0	0	0	0	0	0	0	0	0	0	0	0	0	0	0	0	0	0	0	0	0	0	0	0	0	0	0	0	0	0	0	0	0	0	0	0	0	0	0	0	0	0	0	0	0	0	0	0	0	0	0	0	0	9a	9a	0	0	0	0	0	0	0	0	0	0	0	0	0	0	0	0	0	0	0	0	0	0	0	0	0	0	0	0	0	0	0	0	0	0	0	0	0	0	0	0	0	0	0	0	0	0	0	0	0	0	0	0	0	0	d2	d2	0	0	0	0	0	0	0	d6	d6	0	0	0	0	0	d2	d2	0	0	0	0	92	92	0	92	92	92	0	0	0	0	0	0	0	0	92	0	0	b6	0	0	0	0	0	0	0	d0	0	0	0	0	d0	0	0	0	0	0	0	0	0	0	0	0	0	0	0	0	0	0	0	0	0	0	0	0	0	0	0	0	da	0	0	da	0	0	0	0	9a	0	0	9a	0	0	0	0	da	0	0	da	0	0	0	0	92	0	0	92	0	0	0	0	0	ff	ff	0	ff	0	0	0	d2	d2	d2	0	0	0	0	d6	d6	0	0	d6	d6	0	0	0	0	0	0	0	0	0	0	0	0	0	0	0	0	0	0	0	0	0	0	0	0	0	0	0	0	0	0	0	0	0	0	0	0	0	0	0	0	0	0	0	0	0	0	0	0	0	0	0	0	0	0	0	0	0	0	0	0	0	0	0	0	0	0	0	0	0	0	0	0	0	0	0	0	0	0	0	0	0	0	0	0	0	0	0	0	0	0	0	0	0	0	0	0	0	0	0	0	0	0	0	0	0	0	0	0	0	0	0	0	0	0	0	0	0	0	0	0	0	0	0	0	0	0	0	0	0	0	0	0	0	0	0	0	0	0	0	0	0	0	0	0	0	0	0	0	0	0	0	0	0	0	0	0	0	0	0	0	0	ff	ff	ff	ff	ff	ff	ff	ff	d2	d2	0	0	0	0	d2	d2	d6	0	0	d6	0	0	d6	d6	d2	0	0	d2	0	0	d2	d2	92	0	0	0	0	0	92	92	0	0	92	92	92	0	0	92	b6	0	0	b6	0	0	b6	b6	d0	0	0	d0	d0	d0	d0	d0	90	90	0	0	90	90	90	90	9a	9a	0	0	9a	9a	9a	9a	92	0	0	92	92	0	0	92	da	da	0	0	da	da	da	da	9a	9a	9a	9a	9a	9a	9a	9a	da	da	da	da	da	da	da	da	92	92	92	92	92	92	92	92	ff	ff	ff	ff	0	0	ff	ff	0	0	d2	d2	d2	0	0	d2	d6	0	0	0	d6	d6	d6	d6	0	0	d2	d2	0	0	d2	d2	0	0	92	92	0	0	92	92	92	92	0	0	0	0	92	92	0	0	b6	b6	b6	b6	b6	b6	d0	0	0	d0	d0	d0	d0	d0	0	0	90	90	0	0	90	90	0	0	9a	9a	0	0	9a	9a	0	0	92	92	0	0	92	92	da	da	0	0	da	da	da	da	9a	9a	0	0	9a	9a	9a	9a	da	da	0	0	da	da	da	da	92	92	92	92	92	92	92	92	ff	ff	0	0	ff	ff	ff	ff	0	0	d2	d2	0	0	d2	d2	0	0	d6	d6	d6	0	0	d6	d2	0	0	0	0	d2	d2	d2	92	0	0	92	92	0	0	92	92	0	0	92	92	0	0	92	b6	0	0	b6	0	0	b6	b6	d0	0	0	d0	d0	d0	0	d0	90	0	0	90	90	90	0	90	9a	0	0	9a	9a	0	0	9a	0	0	92	92	0	0	92	92	da	da	0	0	da	da	da	da	9a	9a	9a	9a	0	0	9a	9a	da	0	0	da	da	0	0	da	92	0	0	92	92	92	92	92	0	0	0	ff	0	0	0	ff	0	0	0	d2	d2	0	0	d2	d6	0	0	d6	0	0	d6	d6	d2	0	0	d2	d2	0	0	d2	0	0	92	92	0	0	92	92	92	0	0	92	92	0	0	92	0	0	b6	b6	0	0	b6	b6	0	d0	0	0	d0	0	d0	d0	0	0	90	90	0	0	90	90	0	0	9a	9a	0	0	9a	9a	0	0	92	92	92	0	0	92	0	0	da	da	da	0	0	da	0	0	9a	9a	0	0	9a	9a	0	0	da	da	da	0	0	da	92	0	0	92	92	92	92	92	ff	0	0	ff	ff	ff	ff	ff	d2	d2	d2	0	0	d2	d2	d2	d6	d6	0	0	0	d6	d6	d6	d2	d2	d2	d2	d2	d2	d2	d2	92	92	0	0	92	92	92	92	92	92	92	92	92	92	92	92	b6	0	0	b6	b6	b6	b6	b6	d0	d0	d0	d0	d0	d0	d0	d0	90	90	90	90	0	0	90	90	9a	9a	9a	9a	9a	9a	9a	9a	92	0	0	92	0	0	92	92	da	da	da	da	da	da	da	da	9a	0	0	9a	9a	9a	9a	9a	da	da	da	da	da	da	da	da	92	92	92	92	92	92	92	92	ff	0	0	ff	ff	ff	ff	ff	d2	d2	0	0	d2	d2	d2	d2	d6	d6	d6	d6	d6	d6	d6	d6	d2	d2	d2	d2	d2	d2	d2	d2	92	92	92	92	92	92	92	92	92	92	92	92	92	92	92	92	b6	b6	b6	b6	b6	b6	b6	b6	d0	d0	d0	d0	d0	d0	d0	d0	90	90	90	90	90	90	90	90	9a	9a	0	0	9a	9a	9a	9a	92	92	92	92	92	92	92	92	da	da	da	da	da	da	da	da	9a	9a	9a	9a	9a	9a	9a	9a	da	da	da	da	da	da	da	da	92	92	92	92	92	92	92	92	ff	ff	ff	ff	ff	ff	ff	ff	d2	d2	0	0	d2	d2	d2	d2	d6	d6	d6	0	0	d6	d6	d6	d2	d2	0	0	d2	d2	d2	d2	0	0	92	0	0	0	92	92	92	92	92	92	92	92	0	92	b6	0	b6	b6	b6	b6	b6	b6	d0	0	d0	d0	d0	d0	0	d0	90	90	90	90	90	90	90	90	9a	9a	9a	9a	9a	9a	9a	9a	92	92	92	92	92	92	92	92	da	da	0	da	da	0	da	da	9a	9a	0	9a	9a	0	9a	9a	da	da	0	da	da	0	da	da	92	92	0	92	92	0	92	92	ff	ff	ff	0	0	ff	0	ff	d2	d2	0	0	0	d2	d2	d2	d6	0	0	d6	d6	0	0	d6	d2	d2	d2	d2	d2	d2	d2	d2	92	92	92	92	92	92	92	92	92	92	92	92	92	92	92	92	b6	b6	b6	b6	b6	b6	b6	b6	d0	d0	d0	d0	d0	d0	d0	d0	90	90	90	90	90	90	90	90	9a	9a	9a	9a	9a	9a	9a	9a	92	92	92	92	92	92	92	92	da	da	da	da	da	da	da	da	9a	9a	9a	9a	9a	9a	9a	9a	da	da	da	da	da	da	da	da	92	92	92	92	92	92	92	92	ff	ff	ff	ff	ff	ff	ff	ff	d2	d2	d2	d2	d2	d2	d2	d2	d6	d6	d6	d6	d6	d6	d6	d6	d2	d2	d2	d2	d2	d2	d2	d2	92	92	92	92	92	92	92	92	92	92	92	92	92	92	92	92	b6	b6	b6	b6	b6	b6	b6	b6	d0	d0	d0	d0	d0	d0	d0	d0
0	0	0	0	0	0	0	0	0	0	d2	d2	d2	d2	0	0	0	0	0	0	0	0	0	0	d2	d2	d2	d2	d2	d2	d2	0	92	92	0	0	0	0	0	0	92	92	0	0	92	92	0	0	0	0	b6	b6	b6	0	0	0	d0	d0	0	0	0	0	0	0	0	90	90	0	0	0	0	0	0	0	0	9a	9a	0	0	0	0	0	92	92	92	92	0	0	0	0	da	da	0	0	0	0	0	0	0	0	0	0	0	0	0	0	0	0	0	0	0	0	0	0	0	0	0	0	0	0	0	0	0	ff	ff	0	0	0	d2	d2	0	0	d2	d2	d2	0	0	0	d6	d6	0	0	0	0	0	0	0	0	d2	d2	0	0	0	0	0	0	92	92	0	0	0	92	92	0	92	92	0	0	b6	b6	b6	b6	b6	0	0	0	d0	d0	0	0	0	0	0	0	0	0	0	0	90	90	0	0	9a	9a	0	0	9a	9a	0	0	92	92	0	0	92	92	0	0	0	0	da	da	0	0	0	0	0	0	9a	9a	0	0	0	0	0	da	da	0	0	0	0	0	92	92	92	92	92	92	0	0	0	0	0	ff	ff	0	0	0	0	0	0	0	d2	d2	0	0	d6	d6	0	d6	d6	d6	d6	0	d2	d2	0	0	d2	d2	0	0	0	92	92	0	0	92	92	0	92	92	0	0	0	0	0	0	0	b6	b6	0	0	b6	b6	0	0	d0	d0	0	d0	0	0	0	0	90	90	0	90	0	0	0	9a	9a	0	0	0	0	0	0	92	92	0	0	92	92	0	0	0	0	da	da	0	0	0	0	0	0	0	0	9a	9a	0	0	0	da	da	0	da	da	0	0	0	92	92	0	0	0	0	0	ff	ff	ff	ff	ff	ff	ff	0	d2	d2	d2	d2	0	d2	d2	0	d6	d6	0	0	0	d6	d6	0	0	d2	d2	0	0	d2	d2	0	92	92	0	0	92	92	0	0	0	92	92	0	0	92	92	0	b6	b6	b6	0	0	0	0	0	0	0	d0	d0	0	0	0	0	90	90	0	0	90	90	0	0	9a	9a	0	0	9a	9a	0	0	92	92	0	0	0	92	92	0	0	da	da	0	da	da	0	0	9a	9a	0	0	9a	9a	0	0	da	0	0	0	da	da	0	0	0	92	92	0	0	0	0	0	0	0	ff	ff	0	0	0	0	0	0	0	d2	d2	0	0	0	0	d6	d6	0	d6	d6	0	0	0	0	0	0	0	0	0	0	0	0	0	92	92	0	0	0	0	92	92	92	92	0	0	0	0	b6	b6	0	0	0	0	0	0	d0	d0	d0	d0	0	0	0	0	0	0	0	90	90	0	0	0	9a	9a	9a	9a	0	0	0	0	92	92	0	0	0	0	0	0	da	da	da	0	da	da	0	0	9a	9a	0	9a	9a	0	0	0	da	da	da	0	0	0	0	0	0	0	0	92	92	0	0	0	ff	ff	0	0	ff	ff	0	0	0	d2	d2	0	0	0	0	d6	d6	0	0	d6	d6	0	0	d2	d2	d2	d2	d2	0	0	0	0	92	92	92	92	0	0	0	92	92	0	92	92	92	0	0	0	b6	b6	b6	0	b6	b6	0	d0	d0	0	d0	d0	d0	0	0	0	90	90	90	90	90	0	0	0	9a	9a	9a	9a	9a	0	0	92	92	0	0	92	92	0	0	da	da	0	0	da	da	0	0	9a	9a	0	0	0	9a	9a	0	da	da	0	0	0	da	da	0	92	92	0	0	92	92	0	0	ff	ff	ff	ff	ff	ff	0	0	0	0	d2	d2	0	0	0	0	0	0	0	d6	d6	0	0	0	0	0	d2	d2	0	0	0	0	0	0	0	0	0	0	0	0	0	0	0	0	0	92	0	0	0	0	b6	0	0	0	0	0	0	0	d0	0	0	d0	0	0	0	0	0	0	90	90	90	90	9a	9a	9a	9a	9a	9a	9a	9a	92	92	92	92	0	0	0	0	0	0	da	0	0	da	0	0	9a	9a	9a	0	0	9a	9a	9a	0	0	da	0	0	da	da	da	92	92	92	0	0	92	0	0	0	0	ff	ff	ff	ff	0	0	0	d2	d2	d2	d2	d2	0	0	d6	0	0	d6	d6	0	0	d6	0	0	0	0	0	0	0	0	0	0	0	0	0	0	0	0	0	0	0	0	0	0	0	0	0	0	0	0	0	0	0	0	0	0	0	0	0	0	0	0	0	0	0	0	0	0	0	0	0	0	0	0	0	0	0	0	0	0	0	0	0	0	0	0	0	0	0	0	0	0	0	0	0	0	0	0	0	0	0	0	0	0	0	0	0	0	0	0	0	0	0	0	0	0	0	0	0	0	0	0	0	0	0	0	0	0	0	0	0	0	0	0	0	0	0	0	0	0	0	0	0	0	0	0	0	0	0	0	0	0	0	0	0	0	0	0	0	0	0	0	0	0	0	0	0	0	0	0	0	0	0	0	0	0	0	0	0	0	0	0	ff	ff	ff	ff	ff	ff	ff	ff	d2	d2	0	0	0	0	d2	d2	d6	d6	d6	d6	d6	d6	d6	d6	0	0	0	0	0	0	0	d2	0	0	92	92	92	92	92	92	0	0	92	92	0	0	92	92	b6	b6	0	0	0	b6	b6	b6	0	0	d0	d0	d0	d0	d0	d0	90	0	0	90	90	90	90	90	9a	9a	9a	0	0	9a	9a	9a	92	92	0	0	0	0	92	92	da	da	0	0	da	da	da	da	9a	9a	9a	9a	9a	9a	9a	9a	da	da	da	da	da	da	da	da	92	92	92	92	92	92	92	92	ff	ff	ff	0	0	ff	ff	ff	0	0	d2	d2	0	0	0	d2	d6	d6	0	0	d6	d6	d6	d6	d2	d2	d2	d2	0	0	d2	d2	92	92	92	92	0	0	92	92	92	0	0	92	0	0	92	92	0	0	0	0	0	b6	b6	b6	0	0	d0	d0	d0	d0	d0	d0	90	90	90	90	0	0	90	90	0	0	9a	9a	0	0	9a	9a	0	0	92	92	0	0	92	92	da	da	0	0	da	da	da	da	9a	9a	0	0	9a	9a	9a	9a	da	0	0	da	da	da	da	da	0	0	0	0	0	0	92	92	ff	ff	ff	0	0	ff	ff	ff	d2	d2	d2	d2	0	0	d2	d2	0	0	d6	0	0	0	0	d6	0	0	d2	d2	0	0	d2	d2	92	0	0	92	92	0	0	92	0	0	92	92	92	92	92	92	b6	0	0	b6	b6	0	0	b6	d0	0	0	d0	0	d0	d0	d0	90	0	0	90	0	90	90	90	0	0	9a	9a	9a	9a	9a	9a	0	0	92	92	0	0	92	92	da	da	0	0	da	da	da	da	9a	9a	9a	9a	0	0	9a	9a	da	0	0	da	0	0	da	da	92	0	0	92	92	92	92	92	0	0	0	0	0	0	0	ff	0	0	0	0	d2	0	0	d2	0	0	d6	d6	d6	0	0	d6	d2	0	0	d2	d2	0	0	d2	0	0	92	92	0	0	92	92	92	0	0	92	92	0	0	92	0	0	0	b6	b6	b6	b6	b6	d0	d0	0	0	d0	d0	d0	d0	0	0	90	90	0	0	90	90	0	0	9a	9a	0	0	9a	9a	0	0	92	92	92	0	0	92	da	0	0	da	0	0	da	da	0	0	9a	9a	0	0	9a	9a	0	da	da	da	0	0	da	da	92	0	0	92	92	92	92	92	ff	ff	0	0	ff	ff	ff	ff	d2	d2	d2	0	0	d2	d2	d2	d6	0	0	d6	0	0	d6	d6	d2	d2	d2	d2	d2	d2	d2	d2	92	92	92	0	0	92	92	92	92	0	0	0	0	92	92	92	b6	0	0	b6	b6	b6	b6	b6	d0	0	0	0	0	d0	d0	d0	90	90	90	90	0	0	90	90	9a	0	0	0	0	9a	9a	9a	92	0	0	92	92	92	92	92	da	0	0	0	da	0	0	da	9a	0	0	9a	0	0	9a	9a	da	0	0	0	da	da	da	da	92	92	92	92	0	0	92	92	ff	0	0	ff	ff	0	0	ff	d2	d2	0	0	d2	d2	d2	d2	0	0	d6	d6	0	0	d6	d6	0	0	0	0	0	d2	d2	d2	92	0	0	0	0	92	92	92	0	0	92	0	0	0	92	92	b6	0	0	0	b6	0	0	b6	0	0	d0	0	0	0	d0	d0	90	0	0	0	0	0	90	90	9a	0	0	0	0	0	9a	9a	0	0	92	92	0	0	92	92	0	0	da	da	0	0	da	da	0	0	9a	9a	9a	0	0	9a	0	0	da	da	da	0	0	da	0	0	92	92	0	0	92	92	0	0	0	0	0	0	ff	ff	d2	d2	0	0	d2	d2	d2	d2	d6	d6	d6	0	0	d6	d6	d6	d2	d2	0	0	d2	d2	d2	d2	92	92	92	92	92	92	92	92	92	92	92	92	92	0	92	92	b6	b6	0	b6	b6	b6	b6	b6	d0	d0	0	d0	d0	0	d0	d0	90	90	90	90	0	0	0	0	0	0	0	0	0	0	0	0	0	0	0	0	92	92	92	92	da	da	0	da	da	0	da	da	0	0	0	9a	9a	0	0	0	da	da	0	da	da	0	0	0	0	0	0	92	92	0	92	92	ff	ff	0	0	0	0	ff	ff	d2	0	0	0	0	0	d2	d2	0	d6	d6	0	0	d6	d6	0	d2	d2	d2	d2	d2	d2	d2	d2	92	92	92	92	92	92	92	92	92	92	92	92	92	92	92	92	b6	b6	b6	b6	b6	b6	b6	b6	d0	d0	d0	d0	d0	d0	d0	d0	90	90	90	90	90	90	90	90	9a	9a	9a	9a	9a	9a	9a	9a	92	92	92	92	92	92	92	92	da	da	da	da	da	da	da	da	9a	9a	9a	9a	9a	9a	9a	9a	da	da	da	da	da	da	da	da	92	92	92	92	92	92	92	92	ff	ff	ff	ff	ff	ff	ff	ff	d2	d2	d2	d2	d2	d2	d2	d2	d6	d6	d6	d6	d6	d6	d6	d6	d2	d2	d2	d2	d2	d2	d2	d2	92	92	92	92	92	92	92	92	92	92	92	92	92	92	92	92	b6	b6	b6	b6	b6	b6	b6	b6	d0	d0	d0	d0	d0	d0	d0	d0
0	0	0	0	0	0	0	0	0	0	0	d2	d2	0	0	0	0	0	0	0	0	0	0	0	0	d2	d2	0	d2	d2	0	0	0	92	92	92	92	0	0	0	0	0	0	92	92	0	0	0	0	b6	b6	b6	0	b6	b6	0	0	0	0	0	0	0	0	0	0	90	90	0	0	0	0	0	0	0	0	9a	9a	0	0	0	92	92	92	92	92	92	92	92	da	da	da	da	da	da	0	0	0	0	0	0	0	0	0	0	da	da	da	da	da	da	0	0	0	0	0	0	0	0	0	0	0	0	ff	ff	0	0	0	0	d2	d2	0	d2	d2	d2	d2	0	0	0	d6	d6	0	0	0	0	0	0	d2	d2	d2	0	0	0	0	0	92	92	92	0	0	0	92	92	0	0	92	92	0	0	0	0	0	0	b6	b6	0	0	d0	d0	d0	d0	d0	0	0	0	0	0	0	90	90	0	0	0	0	9a	9a	9a	9a	0	0	0	0	92	92	92	92	92	0	0	0	0	0	0	0	0	0	0	0	0	0	0	0	0	0	0	da	da	0	0	0	0	0	0	0	0	0	0	0	0	0	0	0	0	0	0	ff	ff	0	0	0	0	0	d2	d2	0	0	0	d6	d6	0	d6	d6	d6	d6	0	d2	d2	0	0	d2	d2	0	0	0	92	92	92	92	92	0	0	92	92	0	0	0	0	0	0	0	b6	b6	0	0	b6	b6	0	0	d0	d0	d0	d0	0	0	0	0	90	90	90	90	0	0	0	9a	9a	0	0	0	0	0	0	92	92	92	92	92	92	0	0	0	0	da	da	0	0	0	0	0	0	0	0	9a	9a	0	0	0	da	da	da	da	0	0	0	0	92	92	0	0	0	0	0	ff	ff	ff	ff	ff	ff	ff	0	d2	d2	0	d2	d2	d2	d2	0	d6	d6	0	0	0	d6	d6	0	0	d2	d2	d2	d2	d2	0	0	92	92	0	0	92	92	0	0	0	92	92	92	92	92	0	0	0	b6	b6	b6	0	0	0	0	0	0	d0	d0	0	0	0	0	90	90	0	0	90	90	0	0	9a	9a	0	0	9a	9a	0	0	92	92	0	92	0	92	92	0	0	0	da	da	da	0	0	0	0	9a	9a	9a	9a	0	0	0	0	0	0	da	da	0	0	0	0	92	92	0	0	0	0	0	0	0	0	ff	ff	0	0	0	0	0	0	d2	d2	0	0	0	d6	d6	0	0	0	d6	d6	0	0	0	0	0	0	0	0	0	0	0	0	0	0	0	0	0	0	0	0	0	92	92	0	0	0	b6	b6	b6	b6	b6	0	0	d0	d0	0	0	d0	d0	0	0	0	90	90	90	90	90	0	0	9a	9a	0	0	9a	9a	0	0	92	92	92	92	0	0	0	0	da	da	0	0	da	da	0	0	0	9a	9a	9a	0	9a	9a	0	0	0	da	da	0	0	0	0	0	0	0	0	92	92	0	0	0	ff	ff	0	ff	ff	0	0	0	0	d2	d2	0	0	0	0	d6	d6	d6	d6	d6	d6	d6	0	d2	d2	0	0	d2	d2	0	0	92	92	0	0	92	92	0	0	0	92	92	0	0	92	92	0	b6	b6	0	0	b6	b6	0	0	0	d0	d0	d0	0	d0	d0	0	90	90	0	0	0	0	0	0	0	0	9a	9a	0	0	0	0	92	92	0	0	92	92	0	0	da	da	0	0	da	da	0	0	9a	9a	0	9a	0	9a	9a	0	0	da	da	0	da	da	0	0	92	92	0	0	92	92	0	0	ff	0	0	ff	ff	0	0	0	d2	d2	d2	0	0	0	0	0	0	0	0	0	0	0	0	0	0	0	0	d2	d2	d2	0	0	0	0	0	0	0	0	0	0	0	0	0	0	92	0	0	0	0	0	0	b6	0	0	0	0	0	0	0	d0	d0	0	0	0	0	0	0	90	0	0	0	0	0	0	0	0	0	0	0	0	0	0	0	0	92	0	0	0	0	0	da	0	0	da	0	0	0	0	0	0	0	0	0	0	0	0	da	0	0	0	0	0	0	0	0	0	0	92	0	0	0	ff	ff	0	ff	ff	ff	0	0	d2	d2	0	d2	d2	d2	d2	d6	0	0	0	0	0	0	d6	0	0	0	0	0	0	0	0	0	0	0	0	0	0	0	0	0	0	0	0	0	0	0	0	0	0	0	0	0	0	0	0	0	0	0	0	0	0	0	0	0	0	0	0	0	0	0	0	0	0	0	0	0	0	0	0	0	0	0	0	0	0	0	0	0	0	0	0	0	0	0	0	0	0	0	0	0	0	0	0	0	0	0	0	0	0	0	0	0	0	0	0	0	0	0	0	0	0	0	0	0	0	0	0	0	0	0	0	0	0	0	0	0	0	0	0	0	0	0	0	0	0	0	0	0	0	0	0	0	0	0	0	0	0	0	0	0	0	0	0	0	0	0	0	0	0	0	0	0	0	0	0	0	0	0	0	0	0	0	0	ff	ff	ff	ff	ff	ff	ff	ff	d2	d2	d2	0	0	d2	d2	d2	d6	d6	d6	d6	d6	d6	d6	d6	d2	0	0	d2	0	0	d2	d2	92	0	0	0	0	92	92	92	92	92	92	0	0	92	92	92	b6	0	0	0	b6	0	0	b6	d0	d0	d0	d0	d0	d0	d0	d0	90	0	0	90	90	90	90	90	9a	9a	9a	0	0	9a	9a	9a	0	0	0	0	0	0	0	0	0	0	0	0	0	0	da	da	9a	9a	9a	9a	9a	9a	9a	9a	0	0	0	0	0	0	da	da	92	92	92	92	92	92	92	92	ff	ff	0	0	ff	ff	ff	ff	0	0	d2	0	0	0	0	d2	d6	d6	0	0	d6	d6	d6	d6	d2	d2	0	0	0	d2	d2	d2	92	92	0	0	0	92	92	92	0	0	92	92	0	0	92	92	b6	b6	b6	b6	0	0	b6	b6	0	0	0	0	0	d0	d0	d0	90	90	90	0	0	90	90	90	9a	0	0	0	0	9a	9a	9a	92	0	0	0	0	0	92	92	da	da	da	da	da	da	da	da	9a	9a	9a	9a	9a	9a	9a	9a	0	0	da	da	da	da	da	da	92	92	92	92	92	92	92	92	ff	ff	ff	ff	0	0	ff	ff	d2	d2	d2	0	0	d2	d2	d2	0	0	d6	0	0	0	0	d6	0	0	d2	d2	0	0	d2	d2	92	0	0	0	0	0	92	92	0	0	92	92	92	92	92	92	b6	0	0	b6	b6	0	0	b6	d0	0	0	0	0	d0	d0	d0	90	0	0	0	0	90	90	90	0	0	9a	9a	9a	9a	9a	9a	0	0	0	0	0	0	92	92	da	da	0	0	da	da	da	da	9a	9a	9a	9a	0	0	9a	9a	da	0	0	0	0	da	da	da	92	0	0	92	92	92	92	92	0	0	0	0	0	0	0	ff	0	0	d2	0	0	0	0	d2	0	0	d6	d6	d6	0	0	d6	d2	0	0	0	0	0	d2	d2	0	0	92	92	0	0	92	92	92	0	0	0	0	0	92	92	b6	0	0	0	b6	b6	b6	b6	d0	d0	0	0	d0	d0	d0	d0	0	0	90	90	0	0	90	90	0	0	9a	9a	0	0	9a	9a	0	0	92	0	92	0	0	92	da	da	0	0	0	da	da	da	9a	0	0	0	0	9a	9a	9a	da	da	da	0	0	da	da	da	92	0	0	92	92	92	92	92	ff	ff	ff	0	0	ff	ff	ff	d2	d2	d2	0	0	d2	d2	d2	0	0	d6	d6	d6	0	0	d6	d2	d2	d2	d2	d2	d2	d2	d2	92	92	92	92	92	92	92	92	92	92	92	92	0	0	92	92	b6	0	0	0	0	0	b6	b6	0	0	d0	d0	0	0	d0	d0	90	0	0	0	0	0	90	90	0	0	9a	9a	0	0	9a	9a	0	0	0	0	92	92	92	92	0	0	da	da	0	0	da	da	9a	0	0	0	9a	0	0	9a	da	da	0	0	da	da	da	da	92	92	92	92	0	0	92	92	ff	0	0	ff	0	0	ff	ff	d2	d2	0	0	d2	d2	d2	d2	0	0	0	0	0	0	0	d6	0	0	d2	d2	0	0	d2	d2	0	0	92	92	0	0	92	92	92	0	0	92	92	0	0	92	0	0	b6	b6	0	0	b6	b6	d0	0	0	0	d0	0	0	d0	0	0	90	90	90	90	90	90	9a	9a	0	0	9a	9a	9a	9a	0	0	92	92	0	0	92	92	0	0	da	da	0	0	da	da	0	0	9a	0	9a	0	0	9a	da	0	0	da	0	0	da	da	0	0	92	92	0	0	92	92	0	ff	ff	0	0	ff	ff	ff	0	0	0	d2	d2	d2	d2	d2	d6	d6	d6	d6	d6	d6	d6	d6	d2	d2	d2	0	0	0	d2	d2	92	92	92	92	92	92	92	92	92	92	92	92	0	92	92	92	b6	b6	b6	0	b6	b6	b6	b6	d0	d0	d0	0	0	d0	d0	d0	90	90	90	0	90	90	90	90	9a	9a	9a	9a	9a	9a	9a	9a	92	92	92	92	0	92	92	92	da	da	0	da	da	0	da	da	9a	9a	9a	9a	9a	9a	9a	9a	da	da	0	da	da	da	da	da	92	92	92	92	92	0	92	92	ff	0	0	ff	0	0	0	ff	d2	0	0	d2	0	0	0	0	0	d6	d6	d6	d6	d6	d6	0	d2	d2	d2	d2	d2	d2	d2	d2	92	92	92	92	92	92	92	92	92	92	92	92	92	92	92	92	b6	b6	b6	b6	b6	b6	b6	b6	d0	d0	d0	d0	d0	d0	d0	d0	90	90	90	90	90	90	90	90	9a	9a	9a	9a	9a	9a	9a	9a	92	92	92	92	92	92	92	92	da	da	da	da	da	da	da	da	9a	9a	9a	9a	9a	9a	9a	9a	da	da	da	da	da	da	da	da	92	92	92	92	92	92	92	92	ff	ff	ff	ff	ff	ff	ff	ff	d2	d2	d2	d2	d2	d2	d2	d2	d6	d6	d6	d6	d6	d6	d6	d6	d2	d2	d2	d2	d2	d2	d2	d2	92	92	92	92	92	92	92	92	92	92	92	92	92	92	92	92	b6	b6	b6	b6	b6	b6	b6	b6	d0	d0	d0	d0	d0	d0	d0	d0
0	0	0	0	0	0	0	0	0	0	0	d2	d2	0	0	0	0	0	0	0	0	0	0	0	d2	d2	d2	d2	d2	d2	d2	0	0	0	0	0	92	92	0	0	0	0	92	92	0	0	0	0	b6	b6	0	b6	b6	b6	0	0	0	0	0	0	0	0	0	0	0	90	90	0	0	0	0	0	0	0	0	9a	9a	0	0	0	0	0	92	92	92	92	0	0	0	0	da	da	0	0	0	0	0	0	0	0	0	0	0	0	0	0	0	0	0	0	0	0	0	0	0	0	0	0	0	0	0	ff	ff	0	0	0	0	0	d2	d2	d2	d2	0	d2	d2	0	0	0	d6	d6	0	0	0	0	0	d2	d2	0	0	0	0	0	0	0	0	0	92	92	0	0	92	92	92	92	92	92	92	0	0	0	0	0	b6	b6	0	0	d0	d0	0	0	d0	d0	0	0	0	0	90	90	0	0	0	0	9a	9a	0	0	9a	9a	0	0	0	0	0	0	92	92	0	0	0	0	0	0	0	0	0	0	0	0	0	0	0	0	0	0	0	da	da	0	0	0	0	0	0	0	0	0	0	0	0	0	0	0	0	ff	ff	0	0	0	0	0	d2	d2	0	0	0	0	d6	d6	0	d6	d6	d6	d6	0	d2	d2	d2	d2	d2	d2	0	0	0	92	92	0	0	92	92	0	92	92	0	0	0	0	0	0	0	b6	b6	0	0	b6	b6	0	0	d0	d0	0	d0	0	0	0	0	90	90	0	90	0	0	0	9a	9a	0	0	9a	9a	9a	0	92	92	0	0	92	92	0	0	0	0	da	da	0	0	0	0	9a	9a	0	0	9a	9a	0	0	0	da	da	0	da	da	0	0	0	92	92	0	0	0	92	0	ff	ff	0	ff	0	ff	ff	0	d2	d2	0	0	d2	d2	d2	0	d6	d6	0	0	0	d6	d6	0	0	d2	d2	0	0	0	0	0	92	92	0	92	92	92	0	0	0	92	92	0	92	92	0	0	0	0	0	b6	b6	b6	0	0	0	0	d0	d0	0	0	0	0	90	90	0	0	90	90	0	0	9a	9a	0	0	9a	9a	0	0	92	92	92	92	92	92	92	0	0	0	da	da	da	0	0	0	0	0	9a	9a	0	0	0	0	0	0	da	da	0	0	da	0	0	92	92	0	0	0	0	0	0	0	0	0	ff	ff	0	0	0	0	0	d2	d2	0	0	0	0	0	0	0	0	0	0	0	0	0	0	0	0	0	0	0	0	0	0	0	0	0	0	0	0	92	92	92	92	92	0	0	0	b6	b6	0	0	b6	b6	0	d0	d0	0	0	0	0	0	0	90	90	0	0	90	90	0	0	9a	9a	9a	9a	9a	9a	0	0	0	92	92	0	0	0	0	0	da	da	0	0	da	da	0	0	0	9a	9a	0	0	9a	9a	0	0	0	da	da	0	0	0	0	0	0	0	0	92	92	0	0	0	ff	ff	ff	ff	0	0	0	0	0	d2	d2	0	0	0	0	d6	d6	d6	d6	d6	d6	d6	0	d2	d2	0	0	d2	d2	0	0	92	92	0	0	92	92	0	0	0	92	92	0	0	92	92	0	b6	b6	0	0	b6	b6	0	0	0	d0	d0	0	0	d0	d0	0	0	90	90	90	90	0	0	0	0	0	9a	9a	0	0	0	0	92	92	0	0	92	92	0	0	da	da	0	0	da	da	0	0	9a	9a	9a	9a	9a	9a	9a	0	0	0	da	da	da	0	0	0	92	92	0	0	92	92	0	0	0	0	ff	ff	0	0	0	0	0	0	d2	d2	0	0	0	0	0	0	0	d6	d6	0	0	0	0	0	d2	d2	0	0	0	0	0	0	0	0	0	0	0	0	0	0	0	92	0	0	0	0	0	0	0	0	b6	0	0	0	0	0	0	d0	d0	0	0	0	0	0	90	0	0	0	0	0	0	0	0	0	0	0	0	0	0	0	0	0	0	92	0	0	0	0	da	0	0	da	0	0	0	0	0	0	0	0	0	0	0	0	0	da	0	0	0	0	0	0	0	0	92	0	0	0	0	ff	ff	ff	ff	ff	ff	0	0	0	0	d2	0	d2	d2	d2	0	d6	0	0	0	0	d6	0	0	0	0	0	0	0	0	0	0	0	0	0	0	0	0	0	0	0	0	0	0	0	0	0	0	0	0	0	0	0	0	0	0	0	0	0	0	0	0	0	0	0	0	0	0	0	0	0	0	0	0	0	0	0	0	0	0	0	0	0	0	0	0	0	0	0	0	0	0	0	0	0	0	0	0	0	0	0	0	0	0	0	0	0	0	0	0	0	0	0	0	0	0	0	0	0	0	0	0	0	0	0	0	0	0	0	0	0	0	0	0	0	0	0	0	0	0	0	0	0	0	0	0	0	0	0	0	0	0	0	0	0	0	0	0	0	0	0	0	0	0	0	0	0	0	0	0	0	0	0	0	0	0	0	0	0	0	0	0	0	ff	ff	ff	ff	ff	ff	ff	ff	d2	d2	d2	0	0	d2	d2	d2	d6	d6	d6	d6	d6	d6	d6	d6	0	0	0	0	0	0	0	d2	92	92	92	92	0	0	92	92	92	92	0	0	92	92	92	92	0	0	b6	0	0	0	b6	b6	d0	d0	d0	d0	d0	d0	d0	d0	90	0	0	90	90	90	90	90	9a	9a	9a	0	0	9a	9a	9a	92	92	0	0	0	0	92	92	da	da	0	0	da	da	da	da	9a	9a	9a	9a	9a	9a	9a	9a	da	da	da	da	da	da	da	da	92	92	92	92	92	92	92	92	ff	0	0	ff	ff	ff	ff	ff	0	0	0	0	d2	0	0	d2	d6	d6	0	0	d6	d6	d6	d6	d2	0	0	d2	d2	d2	d2	d2	92	92	92	92	0	0	92	92	0	0	0	0	0	0	0	92	b6	b6	b6	b6	0	0	b6	b6	0	0	d0	d0	0	0	d0	d0	90	90	0	0	90	90	90	90	0	0	9a	9a	0	0	9a	9a	92	92	92	92	0	0	92	92	da	da	da	da	da	da	da	da	9a	9a	9a	9a	9a	9a	9a	9a	da	0	0	da	da	da	da	da	92	92	92	92	92	92	92	92	ff	ff	ff	0	0	ff	ff	ff	d2	d2	0	0	d2	d2	d2	d2	0	0	d6	0	0	0	0	d6	0	0	0	0	0	0	d2	d2	92	0	0	92	92	0	0	92	0	0	92	92	92	92	92	92	b6	0	0	b6	b6	0	0	b6	d0	0	0	d0	0	d0	d0	d0	90	0	0	90	0	90	90	90	0	0	9a	9a	0	0	0	9a	0	0	92	92	0	0	92	92	da	da	0	0	da	da	da	da	0	0	9a	9a	0	0	9a	9a	da	0	0	da	0	0	da	da	92	0	0	92	92	92	0	92	0	0	ff	0	ff	0	0	ff	0	0	d2	d2	0	0	0	d2	0	0	d6	d6	d6	0	0	d6	d2	0	0	d2	d2	d2	d2	d2	0	0	92	0	0	0	92	92	92	0	0	92	0	0	92	92	b6	b6	b6	0	0	0	b6	b6	d0	d0	0	0	d0	d0	d0	d0	0	0	90	90	0	0	90	90	0	0	9a	9a	0	0	9a	9a	0	0	0	0	0	0	0	92	da	da	0	0	0	da	da	da	9a	9a	0	0	9a	9a	9a	9a	da	da	0	0	da	da	0	da	92	0	0	92	92	92	92	92	ff	ff	ff	ff	0	0	ff	ff	d2	d2	d2	0	0	d2	d2	d2	d6	d6	d6	d6	d6	d6	d6	d6	d2	d2	d2	d2	d2	d2	d2	d2	92	92	92	92	92	92	92	92	92	0	0	0	0	0	92	92	b6	0	0	b6	b6	0	0	b6	0	0	d0	d0	d0	d0	d0	d0	0	0	90	90	0	0	90	90	0	0	0	0	0	0	9a	9a	92	0	0	92	92	92	92	92	0	0	da	da	0	0	da	da	9a	0	0	9a	9a	0	0	9a	da	da	0	0	da	da	da	da	92	92	92	92	0	0	92	92	ff	0	0	0	0	ff	ff	ff	d2	d2	0	0	d2	d2	d2	d2	0	0	0	0	0	0	0	d6	0	0	d2	d2	0	0	d2	d2	0	0	92	92	0	0	92	92	92	0	0	92	92	0	0	92	0	0	b6	b6	0	0	b6	b6	d0	0	0	d0	d0	0	0	d0	90	0	0	0	0	90	90	90	9a	9a	0	0	9a	9a	9a	9a	0	0	92	92	0	0	92	92	0	0	da	da	0	0	da	da	0	0	0	0	0	0	0	9a	da	da	0	0	0	da	da	da	0	0	92	92	0	0	92	92	ff	ff	0	0	ff	ff	ff	ff	d2	d2	0	0	d2	d2	d2	d2	d6	d6	d6	0	0	d6	d6	d6	d2	d2	0	0	d2	d2	d2	d2	92	92	92	92	92	92	92	92	92	92	92	0	92	92	92	92	b6	b6	b6	b6	0	b6	b6	b6	d0	d0	d0	0	0	d0	d0	d0	90	90	0	90	90	90	90	90	9a	9a	9a	9a	9a	9a	9a	9a	92	92	92	92	92	0	92	92	da	da	0	da	da	0	da	da	9a	9a	9a	9a	9a	9a	9a	9a	da	da	da	0	da	da	da	da	92	92	92	92	0	92	92	92	ff	0	0	0	0	0	0	ff	d2	d2	d2	0	d2	0	0	0	d6	0	d6	d6	d6	d6	0	d6	d2	d2	d2	d2	d2	d2	d2	d2	92	92	92	92	92	92	92	92	92	92	92	92	92	92	92	92	b6	b6	b6	b6	b6	b6	b6	b6	d0	d0	d0	d0	d0	d0	d0	d0	90	90	90	90	90	90	90	90	9a	9a	9a	9a	9a	9a	9a	9a	92	92	92	92	92	92	92	92	da	da	da	da	da	da	da	da	9a	9a	9a	9a	9a	9a	9a	9a	da	da	da	da	da	da	da	da	92	92	92	92	92	92	92	92	ff	ff	ff	ff	ff	ff	ff	ff	d2	d2	d2	d2	d2	d2	d2	d2	d6	d6	d6	d6	d6	d6	d6	d6	d2	d2	d2	d2	d2	d2	d2	d2	92	92	92	92	92	92	92	92	92	92	92	92	92	92	92	92	b6	b6	b6	b6	b6	b6	b6	b6	d0	d0	d0	d0	d0	d0	d0	d0
0	0	0	0	0	0	0	0	0	0	0	0	0	0	0	0	0	0	0	0	0	0	0	0	0	d2	d2	0	d2	d2	0	0	92	92	92	92	92	0	0	0	0	92	92	0	0	92	92	0	b6	b6	0	0	b6	b6	0	0	0	0	0	0	0	0	0	0	0	0	90	90	0	0	0	0	0	0	9a	9a	0	0	0	0	0	92	92	0	0	92	92	0	0	0	da	da	0	0	0	0	0	0	9a	9a	0	0	0	0	0	0	0	0	0	0	0	0	0	0	92	92	0	0	0	0	ff	ff	0	0	0	0	0	0	d2	d2	d2	0	0	d2	d2	0	0	0	d6	d6	0	0	0	0	d2	d2	0	0	d2	d2	0	0	92	92	0	0	92	92	0	0	0	0	0	0	92	92	0	0	b6	b6	0	0	b6	b6	0	0	d0	d0	0	0	d0	d0	0	0	0	0	90	90	0	0	0	0	9a	9a	0	0	9a	9a	0	0	0	0	0	92	92	0	0	0	0	0	da	da	0	0	0	0	0	0	9a	9a	0	0	0	0	0	0	da	da	0	0	0	0	92	92	92	92	92	92	0	0	0	0	ff	ff	0	0	0	0	0	0	0	0	0	0	0	0	d6	d6	0	0	0	0	0	0	d2	d2	0	0	d2	d2	0	0	0	92	92	0	0	92	92	0	0	92	92	0	0	92	92	0	0	b6	b6	0	b6	b6	0	0	0	d0	d0	0	0	0	d0	0	0	90	90	0	0	0	0	0	0	9a	9a	0	0	9a	9a	0	92	92	0	0	92	92	0	0	0	0	da	da	0	0	0	0	9a	9a	0	0	9a	9a	0	0	0	da	da	0	0	da	da	0	0	92	92	0	0	92	92	0	ff	ff	0	0	0	ff	ff	0	d2	d2	0	0	0	d2	d2	0	0	d6	d6	0	d6	d6	0	0	0	d2	d2	0	0	0	0	0	0	92	92	92	92	0	0	0	0	92	92	0	0	92	92	0	b6	b6	0	0	b6	b6	0	0	0	0	d0	d0	0	0	0	0	90	90	0	0	90	90	0	0	0	9a	9a	9a	9a	0	0	0	92	92	92	0	92	92	92	0	0	da	da	0	da	da	0	0	0	0	9a	9a	0	0	0	0	0	da	da	0	0	da	da	0	0	92	92	0	0	0	0	0	0	0	0	0	0	ff	ff	0	0	0	0	d2	d2	0	0	0	0	0	0	0	0	0	0	0	0	0	0	0	0	0	0	0	0	0	0	0	0	0	0	0	92	92	0	0	92	92	0	0	0	b6	b6	0	0	b6	b6	0	d0	d0	0	0	d0	d0	0	0	90	90	0	0	90	90	0	0	9a	9a	0	0	0	0	0	0	0	92	92	0	0	0	0	0	0	da	da	da	da	da	0	0	0	9a	9a	0	0	9a	9a	0	0	0	da	da	0	0	0	0	92	92	0	0	92	92	0	0	0	ff	ff	0	ff	ff	0	0	0	0	d2	d2	0	0	0	0	d6	d6	0	d6	0	d6	d6	0	d2	d2	0	0	d2	d2	0	0	92	92	0	0	92	92	0	0	0	92	92	92	92	92	0	0	0	b6	b6	b6	b6	b6	0	0	0	d0	d0	0	0	0	0	0	0	0	0	0	90	90	0	0	0	0	9a	9a	0	9a	0	0	92	92	0	0	92	92	0	0	0	da	da	da	da	0	0	0	9a	9a	9a	9a	9a	9a	9a	0	0	da	da	0	da	da	0	0	0	92	92	92	92	92	0	0	0	ff	ff	0	0	ff	0	0	0	0	d2	d2	0	0	0	0	0	0	0	d6	d6	0	0	0	0	0	d2	d2	0	0	0	0	0	0	0	0	0	0	0	0	0	0	92	0	0	0	0	0	0	0	0	0	0	b6	0	0	0	0	d0	0	0	d0	0	0	0	0	90	0	0	90	90	90	9a	9a	9a	9a	9a	9a	9a	9a	92	92	92	0	0	92	0	0	0	0	da	0	0	da	0	0	9a	9a	9a	0	0	9a	9a	9a	0	0	0	0	da	da	da	da	92	92	92	92	0	0	0	0	0	ff	ff	ff	ff	ff	ff	0	0	0	d2	0	0	d2	d2	0	0	0	d6	0	0	d6	0	0	0	0	0	0	0	0	0	0	0	0	0	0	0	0	0	0	0	0	0	0	0	0	0	0	0	0	0	0	0	0	0	0	0	0	0	0	0	0	0	0	0	0	0	0	0	0	0	0	0	0	0	0	0	0	0	0	0	0	0	0	0	0	0	0	0	0	0	0	0	0	0	0	0	0	0	0	0	0	0	0	0	0	0	0	0	0	0	0	0	0	0	0	0	0	0	0	0	0	0	0	0	0	0	0	0	0	0	0	0	0	0	0	0	0	0	0	0	0	0	0	0	0	0	0	0	0	0	0	0	0	0	0	0	0	0	0	0	0	0	0	0	0	0	0	0	0	0	0	0	0	0	0	0	0	0	0	0	0	0	0	ff	ff	ff	ff	ff	ff	ff	ff	d2	d2	d2	d2	d2	d2	d2	d2	d6	d6	d6	d6	d6	d6	d6	d6	d2	0	0	d2	0	0	d2	d2	0	0	0	0	0	92	92	92	92	0	0	92	92	0	0	92	0	0	b6	b6	0	0	b6	b6	d0	d0	d0	d0	d0	d0	d0	d0	90	90	0	0	90	90	90	90	9a	9a	0	0	9a	9a	9a	9a	92	0	0	92	92	0	0	92	da	da	0	0	da	da	da	da	9a	9a	0	0	9a	9a	9a	9a	da	da	da	da	da	da	da	da	92	92	0	0	92	92	92	92	0	0	ff	ff	ff	ff	ff	ff	0	0	0	d2	d2	0	0	d2	d6	d6	0	0	d6	d6	d6	d6	0	0	d2	d2	0	0	d2	d2	0	0	92	92	0	0	92	92	92	92	92	92	0	0	92	92	0	0	b6	b6	0	0	b6	b6	0	0	d0	d0	0	0	d0	d0	90	90	0	0	90	90	90	90	0	0	9a	9a	0	0	9a	9a	92	92	92	0	0	92	92	92	da	da	0	0	da	da	da	da	9a	9a	0	0	9a	9a	9a	9a	da	da	0	0	da	da	da	da	0	0	0	0	0	0	92	92	ff	ff	0	0	ff	ff	ff	ff	d2	d2	d2	d2	d2	d2	d2	d2	0	0	d6	d6	d6	d6	d6	d6	0	0	d2	d2	0	0	d2	d2	92	0	0	92	92	0	0	92	92	0	0	92	92	0	0	92	b6	0	0	b6	0	0	b6	b6	d0	0	0	d0	d0	d0	0	d0	90	0	0	90	90	90	90	90	9a	0	0	9a	9a	0	0	9a	0	0	92	92	0	0	92	92	da	da	0	0	da	da	da	da	0	0	9a	9a	0	0	9a	9a	da	0	0	da	da	0	0	da	92	0	0	92	92	0	0	92	0	0	ff	ff	ff	0	0	ff	0	0	d2	d2	d2	0	0	d2	d6	0	0	d6	0	0	d6	d6	d2	0	0	d2	d2	d2	d2	d2	92	0	0	0	0	92	92	92	92	0	0	92	92	0	0	92	0	0	b6	b6	0	0	b6	b6	d0	d0	0	0	d0	d0	d0	d0	0	0	90	90	0	0	90	90	9a	0	0	0	0	9a	9a	9a	0	0	0	92	0	0	0	92	da	0	0	da	0	0	da	da	9a	9a	0	0	9a	9a	9a	9a	da	0	0	da	da	0	0	da	92	0	0	92	92	92	92	92	ff	ff	ff	ff	ff	0	0	ff	d2	d2	d2	0	0	d2	d2	d2	d6	d6	d6	d6	d6	d6	d6	d6	d2	d2	d2	d2	d2	d2	d2	d2	92	92	92	92	92	92	92	92	0	0	92	92	0	0	92	92	b6	0	0	b6	b6	0	0	b6	0	0	d0	d0	0	0	d0	d0	0	0	90	90	0	0	90	90	0	0	9a	9a	9a	9a	9a	9a	92	0	0	92	92	92	92	92	da	0	0	0	0	0	da	da	9a	0	0	9a	9a	0	0	9a	da	da	0	0	da	da	da	da	0	0	92	92	0	0	92	92	ff	0	0	ff	0	0	ff	ff	d2	d2	0	0	d2	d2	d2	d2	0	0	d6	0	d6	0	0	d6	0	0	d2	d2	0	0	d2	d2	0	0	92	92	0	0	92	92	92	0	0	0	0	0	92	92	b6	0	0	0	0	0	b6	b6	d0	0	0	d0	d0	d0	d0	d0	90	90	90	90	0	0	90	90	9a	9a	0	0	9a	0	9a	9a	0	0	92	92	0	0	92	92	da	0	0	0	0	da	da	da	0	0	0	0	0	0	0	9a	da	0	0	da	0	0	da	da	92	0	0	0	0	0	92	92	ff	0	0	ff	ff	0	ff	ff	d2	d2	0	0	d2	d2	d2	d2	d6	d6	d6	0	0	d6	d6	d6	d2	d2	0	0	d2	d2	d2	d2	92	92	92	92	92	92	92	92	92	92	0	92	92	92	92	92	b6	b6	b6	b6	b6	0	b6	b6	d0	d0	0	d0	d0	0	d0	d0	90	90	0	90	90	0	0	0	0	0	0	0	0	0	0	0	0	0	0	92	92	0	92	92	da	da	0	da	da	0	da	da	0	0	0	9a	9a	0	0	0	da	da	da	da	0	0	0	0	0	0	0	0	92	92	92	92	ff	0	0	0	0	0	0	ff	d2	d2	0	d2	d2	0	0	d2	d6	d6	0	d6	d6	0	d6	d6	d2	d2	d2	d2	d2	d2	d2	d2	92	92	92	92	92	92	92	92	92	92	92	92	92	92	92	92	b6	b6	b6	b6	b6	b6	b6	b6	d0	d0	d0	d0	d0	d0	d0	d0	90	90	90	90	90	90	90	90	9a	9a	9a	9a	9a	9a	9a	9a	92	92	92	92	92	92	92	92	da	da	da	da	da	da	da	da	9a	9a	9a	9a	9a	9a	9a	9a	da	da	da	da	da	da	da	da	92	92	92	92	92	92	92	92	ff	ff	ff	ff	ff	ff	ff	ff	d2	d2	d2	d2	d2	d2	d2	d2	d6	d6	d6	d6	d6	d6	d6	d6	d2	d2	d2	d2	d2	d2	d2	d2	92	92	92	92	92	92	92	92	92	92	92	92	92	92	92	92	b6	b6	b6	b6	b6	b6	b6	b6	d0	d0	d0	d0	d0	d0	d0	d0
0	0	0	0	0	0	0	0	0	0	0	d2	d2	0	0	0	0	0	0	0	0	0	0	0	0	d2	d2	0	d2	d2	0	0	0	0	92	92	0	0	0	0	92	92	0	0	0	92	92	0	0	b6	b6	b6	0	b6	b6	0	0	0	0	0	0	0	0	0	0	0	0	90	90	0	0	0	0	9a	9a	0	0	0	0	0	0	0	0	0	0	0	0	0	0	0	0	0	0	0	0	0	0	0	9a	9a	0	0	0	0	0	0	0	0	0	0	0	0	0	0	92	92	0	0	0	0	ff	0	0	0	0	0	0	0	0	d2	d2	d2	d2	d2	0	0	d6	d6	d6	d6	d6	d6	0	0	d2	d2	d2	d2	d2	d2	0	0	0	92	92	92	92	0	0	0	0	0	0	92	92	92	92	0	0	b6	b6	b6	b6	0	0	0	0	d0	d0	d0	d0	0	0	0	0	0	90	90	0	0	0	0	0	9a	9a	9a	9a	0	0	0	0	92	92	92	0	0	0	0	0	0	da	da	0	0	0	0	0	0	9a	9a	0	0	0	0	0	0	0	da	da	0	0	0	0	0	0	0	0	0	0	0	0	ff	ff	0	0	0	0	0	0	0	d2	d2	0	0	0	0	0	d6	d6	d6	d6	0	0	0	d2	d2	0	0	d2	d2	0	0	92	92	92	92	92	92	0	0	0	0	92	92	92	92	0	0	b6	b6	b6	b6	b6	0	0	0	d0	d0	d0	d0	d0	d0	d0	0	90	90	90	90	0	0	0	0	0	0	9a	9a	9a	9a	9a	0	92	92	0	0	92	92	0	0	0	da	da	da	da	0	0	0	0	9a	9a	9a	9a	0	0	0	da	da	da	0	0	da	da	0	92	92	92	92	92	92	92	0	ff	ff	0	0	0	ff	ff	0	d2	d2	0	0	0	d2	d2	0	0	0	d6	d6	d6	0	0	0	d2	d2	d2	d2	0	0	0	0	0	0	0	92	92	92	0	0	92	92	92	0	0	92	92	0	0	b6	b6	b6	b6	0	0	0	0	d0	d0	d0	d0	0	0	0	90	90	90	90	90	90	0	0	0	0	9a	9a	0	0	0	0	92	92	0	0	0	92	92	0	da	da	0	0	0	da	da	0	0	9a	9a	9a	9a	0	0	0	da	da	da	da	da	da	da	0	0	92	92	92	92	0	0	0	0	0	0	0	0	0	ff	0	0	d2	d2	d2	d2	0	0	0	0	0	0	0	0	0	0	0	0	0	0	0	0	0	0	0	0	0	0	0	0	0	0	0	0	92	92	92	0	92	92	0	b6	b6	0	b6	b6	b6	0	0	0	d0	d0	d0	d0	0	0	0	0	90	90	90	0	90	90	0	0	9a	9a	9a	9a	0	0	0	92	92	92	92	0	0	0	0	0	0	0	0	da	da	0	0	9a	9a	9a	0	0	9a	9a	0	0	da	da	da	da	0	0	0	92	92	0	0	92	92	0	0	ff	ff	ff	0	0	ff	ff	0	0	d2	d2	d2	d2	0	0	0	d6	d6	0	0	0	d6	d6	0	d2	d2	0	0	d2	d2	0	0	0	92	92	92	92	0	0	0	0	92	92	0	0	0	0	0	0	0	0	0	b6	b6	0	0	d0	d0	d0	d0	0	0	0	0	90	90	90	90	90	0	0	0	0	0	0	9a	9a	0	0	0	0	92	92	92	0	92	92	0	0	0	da	da	0	0	0	0	0	9a	9a	0	9a	9a	0	0	da	da	0	0	0	da	da	0	0	0	0	0	92	92	0	0	ff	ff	ff	ff	ff	ff	0	0	0	0	0	d2	d2	d2	0	0	0	0	0	d6	d6	0	0	0	d2	d2	d2	0	0	0	0	0	0	0	0	0	0	0	0	0	0	92	0	0	0	0	0	0	0	0	0	0	0	0	b6	0	0	d0	0	0	0	0	d0	0	0	0	90	0	0	90	0	0	0	0	0	0	0	0	0	0	0	0	92	0	0	92	0	0	0	0	da	0	0	da	0	0	0	0	9a	0	0	9a	0	0	0	0	0	0	0	0	0	0	0	0	0	0	0	0	0	0	0	0	ff	ff	ff	ff	0	0	0	d2	0	0	0	0	0	0	0	0	0	d6	d6	0	0	0	0	0	0	0	0	0	0	0	0	0	0	0	0	0	0	0	0	0	0	0	0	0	0	0	0	0	0	0	0	0	0	0	0	0	0	0	0	0	0	0	0	0	0	0	0	0	0	0	0	0	0	0	0	0	0	0	0	0	0	0	0	0	0	0	0	0	0	0	0	0	0	0	0	0	0	0	0	0	0	0	0	0	0	0	0	0	0	0	0	0	0	0	0	0	0	0	0	0	0	0	0	0	0	0	0	0	0	0	0	0	0	0	0	0	0	0	0	0	0	0	0	0	0	0	0	0	0	0	0	0	0	0	0	0	0	0	0	0	0	0	0	0	0	0	0	0	0	0	0	0	0	0	0	0	0	0	0	0	0	0	ff	ff	ff	ff	ff	ff	ff	ff	d2	d2	d2	0	0	d2	d2	d2	d6	d6	d6	d6	d6	d6	d6	d6	d2	0	0	d2	0	0	d2	d2	92	92	0	0	92	92	92	92	0	0	92	92	92	0	0	92	b6	0	0	0	b6	0	0	b6	d0	d0	d0	d0	d0	d0	d0	d0	90	90	90	0	0	90	90	90	9a	0	0	9a	9a	9a	9a	9a	92	92	92	92	92	92	92	92	da	da	da	da	da	da	da	da	9a	9a	0	0	9a	9a	9a	9a	da	da	da	da	da	da	da	da	92	92	0	0	92	92	92	92	0	ff	ff	ff	ff	ff	ff	ff	d2	0	0	0	0	0	d2	d2	0	0	0	0	0	0	d6	d6	0	0	0	0	0	0	d2	d2	92	0	0	0	0	92	92	92	92	92	92	0	0	0	0	92	b6	0	0	0	0	b6	b6	b6	d0	0	0	0	0	d0	d0	d0	90	90	0	0	90	90	90	90	9a	0	0	0	0	9a	9a	9a	92	0	0	0	92	92	92	92	da	da	0	0	da	da	da	da	9a	9a	0	0	9a	9a	9a	9a	da	da	da	0	0	da	da	da	92	92	92	92	92	92	92	92	ff	0	0	ff	ff	ff	ff	ff	d2	d2	0	0	d2	d2	d2	d2	d6	0	0	0	0	d6	d6	d6	0	0	d2	d2	0	0	d2	d2	0	0	0	0	0	0	92	92	92	92	0	0	0	0	92	92	0	0	0	0	0	b6	b6	b6	0	0	0	0	0	0	0	d0	0	0	0	0	90	90	90	90	9a	9a	0	0	0	0	0	9a	0	0	92	92	0	0	92	92	da	0	0	0	0	da	da	da	9a	0	0	0	0	9a	9a	9a	0	0	0	da	da	0	0	da	0	0	0	0	0	0	0	92	0	0	ff	ff	ff	0	0	ff	0	0	d2	d2	d2	0	0	d2	d6	d6	0	0	0	d6	d6	d6	0	0	0	0	d2	d2	d2	d2	92	92	92	0	0	0	92	92	0	0	0	92	92	0	0	92	b6	0	0	0	0	b6	b6	b6	d0	0	0	0	0	d0	d0	d0	0	0	0	0	0	0	90	90	9a	9a	0	0	9a	9a	9a	9a	0	0	92	92	92	0	0	92	0	0	da	da	da	0	0	da	9a	0	0	0	0	9a	9a	9a	0	0	0	0	0	0	0	da	92	0	0	0	0	92	92	92	ff	ff	ff	ff	ff	ff	0	ff	d2	0	0	0	0	d2	d2	d2	d6	d6	d6	d6	d6	d6	d6	d6	d2	d2	d2	d2	d2	d2	d2	d2	92	92	92	92	92	92	92	92	92	0	0	0	92	0	0	92	0	0	b6	0	0	0	b6	b6	d0	0	0	0	0	d0	d0	d0	90	0	0	0	90	0	0	90	9a	0	0	0	0	9a	9a	9a	0	0	0	0	92	92	92	92	da	da	da	da	0	0	da	da	0	0	0	9a	9a	0	0	9a	da	0	0	0	0	da	da	da	0	0	92	92	0	0	92	92	0	0	0	ff	ff	0	0	ff	d2	0	0	0	0	d2	d2	d2	0	0	d6	d6	d6	0	0	d6	0	0	d2	d2	0	0	d2	d2	92	0	0	0	0	92	92	92	92	0	0	92	92	92	92	92	b6	b6	b6	b6	0	0	b6	b6	0	0	0	0	d0	d0	d0	d0	0	0	0	0	0	90	90	90	9a	9a	9a	0	0	9a	9a	9a	92	0	0	0	92	0	0	92	da	da	0	0	da	da	da	da	9a	0	0	9a	0	0	9a	9a	0	0	da	da	da	0	0	da	92	92	92	92	0	0	92	92	0	0	0	0	0	0	ff	ff	d2	d2	d2	0	0	0	d2	d2	d6	d6	d6	0	0	d6	d6	d6	0	0	0	d2	d2	d2	d2	d2	92	92	92	92	92	92	92	92	92	0	92	92	92	92	92	92	b6	b6	b6	b6	b6	b6	0	b6	d0	0	d0	d0	d0	d0	0	d0	90	90	0	90	90	0	90	90	9a	9a	9a	9a	9a	9a	9a	9a	92	92	0	92	92	0	92	92	da	da	0	da	da	0	da	da	9a	9a	0	9a	9a	0	9a	9a	da	da	da	da	da	da	da	da	92	92	92	92	92	92	92	92	ff	ff	0	0	0	0	ff	ff	d2	0	d2	d2	d2	d2	d2	d2	d6	d6	d6	0	0	d6	d6	d6	d2	d2	d2	d2	d2	d2	d2	d2	92	92	92	92	92	92	92	92	92	92	92	92	92	92	92	92	b6	b6	b6	b6	b6	b6	b6	b6	d0	d0	d0	d0	d0	d0	d0	d0	90	90	90	90	90	90	90	90	9a	9a	9a	9a	9a	9a	9a	9a	92	92	92	92	92	92	92	92	da	da	da	da	da	da	da	da	9a	9a	9a	9a	9a	9a	9a	9a	da	da	da	da	da	da	da	da	92	92	92	92	92	92	92	92	ff	ff	ff	ff	ff	ff	ff	ff	d2	d2	d2	d2	d2	d2	d2	d2	d6	d6	d6	d6	d6	d6	d6	d6	d2	d2	d2	d2	d2	d2	d2	d2	92	92	92	92	92	92	92	92	92	92	92	92	92	92	92	92	b6	b6	b6	b6	b6	b6	b6	b6	d0	d0	d0	d0	d0	d0	d0	d0
0	0	0	0	0	0	0	0	0	0	0	0	0	0	0	0	0	0	0	0	0	0	0	0	0	0	0	0	0	0	0	0	0	0	0	0	0	0	0	0	0	0	0	0	0	0	0	0	0	0	0	0	0	0	0	0	0	0	0	0	0	0	0	0	0	0	0	0	0	0	0	0	0	0	0	0	0	0	0	0	0	0	0	0	0	0	0	0	0	0	0	0	0	0	0	0	0	9a	9a	0	0	0	0	0	0	0	0	0	0	0	0	0	0	0	0	0	0	0	0	0	0	0	0	0	0	0	0	0	0	0	0	0	0	0	0	0	0	0	0	0	0	0	0	0	0	0	0	0	0	0	0	0	0	0	0	0	0	0	0	0	0	0	0	0	0	0	0	0	0	0	0	0	0	0	0	0	0	0	0	0	0	0	0	0	0	0	0	0	0	0	0	0	0	0	0	0	0	0	0	0	0	0	0	0	0	0	0	0	0	0	0	0	0	0	0	0	0	9a	9a	0	0	0	0	0	0	0	0	0	0	0	0	0	0	0	0	0	0	0	0	0	0	0	0	0	0	0	0	0	0	0	0	0	0	0	0	0	0	0	0	0	0	0	0	0	0	0	0	0	0	0	0	0	0	0	0	0	0	0	0	0	0	0	0	0	0	0	0	0	0	0	0	0	0	0	0	0	0	0	0	0	0	0	0	0	0	0	0	0	0	0	0	0	0	0	0	0	0	0	0	0	0	0	0	0	0	0	0	0	0	0	0	0	0	0	0	0	0	0	0	0	0	0	0	0	0	0	0	0	0	0	0	0	0	0	0	0	0	0	0	0	0	0	0	0	0	0	0	0	0	0	0	0	0	0	0	0	0	0	0	0	0	0	0	0	0	0	0	0	0	0	0	0	0	0	0	0	0	0	0	0	0	0	0	0	0	0	0	0	0	0	0	0	0	0	0	0	0	0	0	0	0	0	0	0	0	0	0	0	0	0	0	0	0	0	0	0	0	0	0	0	0	0	0	0	0	0	0	0	0	0	0	0	0	0	0	0	0	0	0	0	0	0	0	0	0	0	0	0	0	0	0	0	0	0	0	0	0	0	0	0	0	0	0	0	0	0	0	0	0	0	0	0	0	0	0	0	0	0	0	0	0	0	0	0	d2	d2	d2	d2	d2	d2	d2	d2	0	0	0	0	0	0	0	0	0	0	0	0	0	0	0	0	0	0	0	0	0	0	0	0	0	0	0	0	0	0	0	0	0	0	0	0	0	0	0	0	0	0	0	0	0	0	0	0	0	0	0	0	0	0	0	0	da	da	da	da	da	0	0	0	0	0	0	0	0	0	0	0	0	0	0	0	0	0	0	0	0	92	92	92	92	0	0	0	0	0	0	0	0	0	0	0	0	0	0	0	0	0	0	0	0	0	0	0	0	0	0	0	0	0	0	0	0	0	0	0	0	0	0	0	0	0	0	0	92	92	92	92	0	0	0	0	0	0	0	b6	b6	b6	b6	0	0	0	0	0	0	0	0	0	0	0	0	0	0	0	0	0	0	0	0	0	0	0	0	0	0	0	0	0	0	0	0	0	0	0	0	0	0	0	0	0	0	0	0	0	0	0	0	0	0	0	0	0	0	0	0	0	92	92	92	92	92	0	0	0	0	0	0	0	0	0	0	0	0	0	0	0	0	0	0	0	0	0	0	0	0	0	0	0	0	0	0	0	0	0	0	0	0	0	0	0	0	0	0	0	92	0	0	0	0	0	0	0	0	0	0	0	0	0	0	b6	d0	0	0	0	0	0	0	d0	0	0	90	0	0	90	0	0	0	0	0	0	0	0	0	0	0	0	92	0	0	92	0	0	0	0	da	0	0	da	0	0	0	0	9a	0	0	9a	0	0	0	0	0	0	0	0	0	0	0	0	0	0	0	0	0	0	0	0	0	ff	ff	0	0	0	d2	0	0	0	0	0	0	0	0	0	0	0	0	0	0	0	0	0	0	0	0	0	0	0	0	0	0	0	0	0	0	0	0	0	0	0	0	0	0	0	0	0	0	0	0	0	0	0	0	0	0	0	0	0	0	0	0	0	0	0	0	0	0	0	0	0	0	0	0	0	0	0	0	0	0	0	0	0	0	0	0	0	0	0	0	0	0	0	0	0	0	0	0	0	0	0	0	0	0	0	0	0	0	0	0	0	0	0	0	0	0	0	0	0	0	0	0	0	0	0	0	0	0	0	0	0	0	0	0	0	0	0	0	0	0	0	0	0	0	0	0	0	0	0	0	0	0	0	0	0	0	0	0	0	0	0	0	0	0	0	0	0	0	0	0	0	0	0	0	0	0	0	0	0	0	0	ff	ff	ff	ff	ff	ff	ff	ff	d2	d2	d2	d2	d2	d2	d2	d2	d6	d6	d6	d6	d6	d6	d6	d6	d2	d2	d2	d2	d2	d2	d2	d2	92	92	92	92	92	92	92	92	92	92	92	92	92	92	92	92	b6	b6	b6	b6	b6	b6	b6	b6	d0	d0	d0	d0	d0	d0	d0	d0	90	90	90	90	90	90	90	90	9a	9a	9a	9a	9a	9a	9a	9a	92	92	92	92	92	92	92	92	da	da	da	da	da	da	da	da	9a	0	0	9a	9a	9a	9a	9a	da	da	da	da	da	da	da	da	92	92	92	92	92	92	92	92	ff	ff	ff	ff	ff	ff	ff	ff	d2	d2	d2	d2	d2	d2	d2	d2	d6	d6	d6	d6	d6	d6	d6	d6	d2	d2	d2	d2	d2	d2	d2	d2	92	92	92	92	92	92	92	92	92	92	92	92	92	92	92	92	b6	b6	b6	b6	b6	b6	b6	b6	d0	d0	d0	d0	d0	d0	d0	d0	90	90	90	90	90	90	90	90	9a	9a	9a	9a	9a	9a	9a	9a	92	92	92	92	92	92	92	92	da	da	da	da	da	da	da	da	9a	0	0	9a	9a	9a	9a	9a	da	da	da	da	da	da	da	da	92	92	92	92	92	92	92	92	ff	ff	ff	ff	ff	ff	ff	ff	d2	d2	d2	d2	d2	d2	d2	d2	d6	d6	d6	d6	d6	d6	d6	d6	d2	d2	d2	d2	d2	d2	d2	d2	92	92	92	92	92	92	92	92	92	92	92	92	92	92	92	92	b6	b6	b6	b6	b6	b6	b6	b6	d0	d0	d0	d0	d0	d0	d0	d0	90	90	90	90	90	90	90	90	9a	9a	9a	9a	9a	9a	9a	9a	92	92	92	92	92	92	92	92	da	da	da	da	da	da	da	da	9a	9a	9a	9a	9a	9a	9a	9a	da	da	da	da	da	da	da	da	92	92	92	92	92	92	92	92	ff	ff	ff	ff	ff	ff	ff	ff	d2	d2	d2	d2	d2	d2	d2	d2	d6	d6	d6	d6	d6	d6	d6	d6	d2	d2	d2	d2	d2	d2	d2	d2	92	92	92	92	92	92	92	92	92	92	92	92	92	92	92	92	b6	b6	b6	b6	b6	b6	b6	b6	d0	d0	d0	d0	d0	d0	d0	d0	90	90	90	90	90	90	90	90	9a	9a	9a	9a	9a	9a	9a	9a	92	92	92	92	92	92	92	92	da	da	da	da	da	da	da	da	9a	9a	9a	9a	9a	9a	9a	9a	da	da	da	da	da	da	da	da	92	92	92	92	92	92	92	92	ff	ff	ff	ff	ff	ff	ff	ff	d2	d2	d2	d2	d2	d2	d2	d2	d6	d6	d6	d6	d6	d6	d6	d6	0	0	0	0	0	0	0	0	92	92	92	92	92	92	92	92	92	92	92	92	92	92	92	92	b6	b6	b6	b6	b6	b6	b6	b6	d0	d0	d0	d0	d0	d0	d0	d0	90	90	90	90	90	90	90	90	9a	9a	9a	9a	9a	9a	9a	9a	92	92	92	92	92	92	92	92	0	0	0	0	0	da	da	da	9a	9a	9a	9a	9a	9a	9a	9a	da	da	da	da	da	da	da	da	92	0	0	0	0	92	92	92	ff	ff	ff	ff	ff	ff	ff	ff	d2	d2	d2	d2	d2	d2	d2	d2	d6	d6	d6	d6	d6	d6	d6	d6	d2	d2	d2	d2	d2	d2	d2	d2	92	92	92	92	92	92	92	92	0	0	0	0	92	92	92	92	b6	b6	b6	0	0	0	0	b6	d0	d0	d0	d0	d0	d0	d0	d0	90	90	90	90	90	90	90	90	9a	9a	9a	9a	9a	9a	9a	9a	92	92	92	92	92	92	92	92	da	da	da	da	da	da	da	da	9a	9a	9a	9a	9a	9a	9a	9a	da	da	da	da	da	da	da	da	0	0	0	0	0	92	92	92	ff	ff	ff	ff	ff	ff	ff	ff	d2	d2	d2	d2	d2	d2	d2	d2	d6	d6	d6	d6	d6	d6	d6	d6	d2	d2	d2	d2	d2	d2	d2	d2	92	92	92	92	92	92	92	92	0	92	92	92	92	92	92	92	b6	b6	b6	b6	b6	b6	b6	0	0	d0	d0	d0	d0	d0	d0	0	90	90	0	90	90	0	90	90	9a	9a	9a	9a	9a	9a	9a	9a	92	92	0	92	92	0	92	92	da	da	0	da	da	0	da	da	9a	9a	0	9a	9a	0	9a	9a	da	da	da	da	da	da	da	da	92	92	92	92	92	92	92	92	ff	ff	ff	0	0	ff	ff	ff	0	d2	d2	d2	d2	d2	d2	d2	d6	d6	d6	d6	d6	d6	d6	d6	d2	d2	d2	d2	d2	d2	d2	d2	92	92	92	92	92	92	92	92	92	92	92	92	92	92	92	92	b6	b6	b6	b6	b6	b6	b6	b6	d0	d0	d0	d0	d0	d0	d0	d0	90	90	90	90	90	90	90	90	9a	9a	9a	9a	9a	9a	9a	9a	92	92	92	92	92	92	92	92	da	da	da	da	da	da	da	da	9a	9a	9a	9a	9a	9a	9a	9a	da	da	da	da	da	da	da	da	92	92	92	92	92	92	92	92	ff	ff	ff	ff	ff	ff	ff	ff	d2	d2	d2	d2	d2	d2	d2	d2	d6	d6	d6	d6	d6	d6	d6	d6	d2	d2	d2	d2	d2	d2	d2	d2	92	92	92	92	92	92	92	92	92	92	92	92	92	92	92	92	b6	b6	b6	b6	b6	b6	b6	b6	d0	d0	d0	d0	d0	d0	d0	d0

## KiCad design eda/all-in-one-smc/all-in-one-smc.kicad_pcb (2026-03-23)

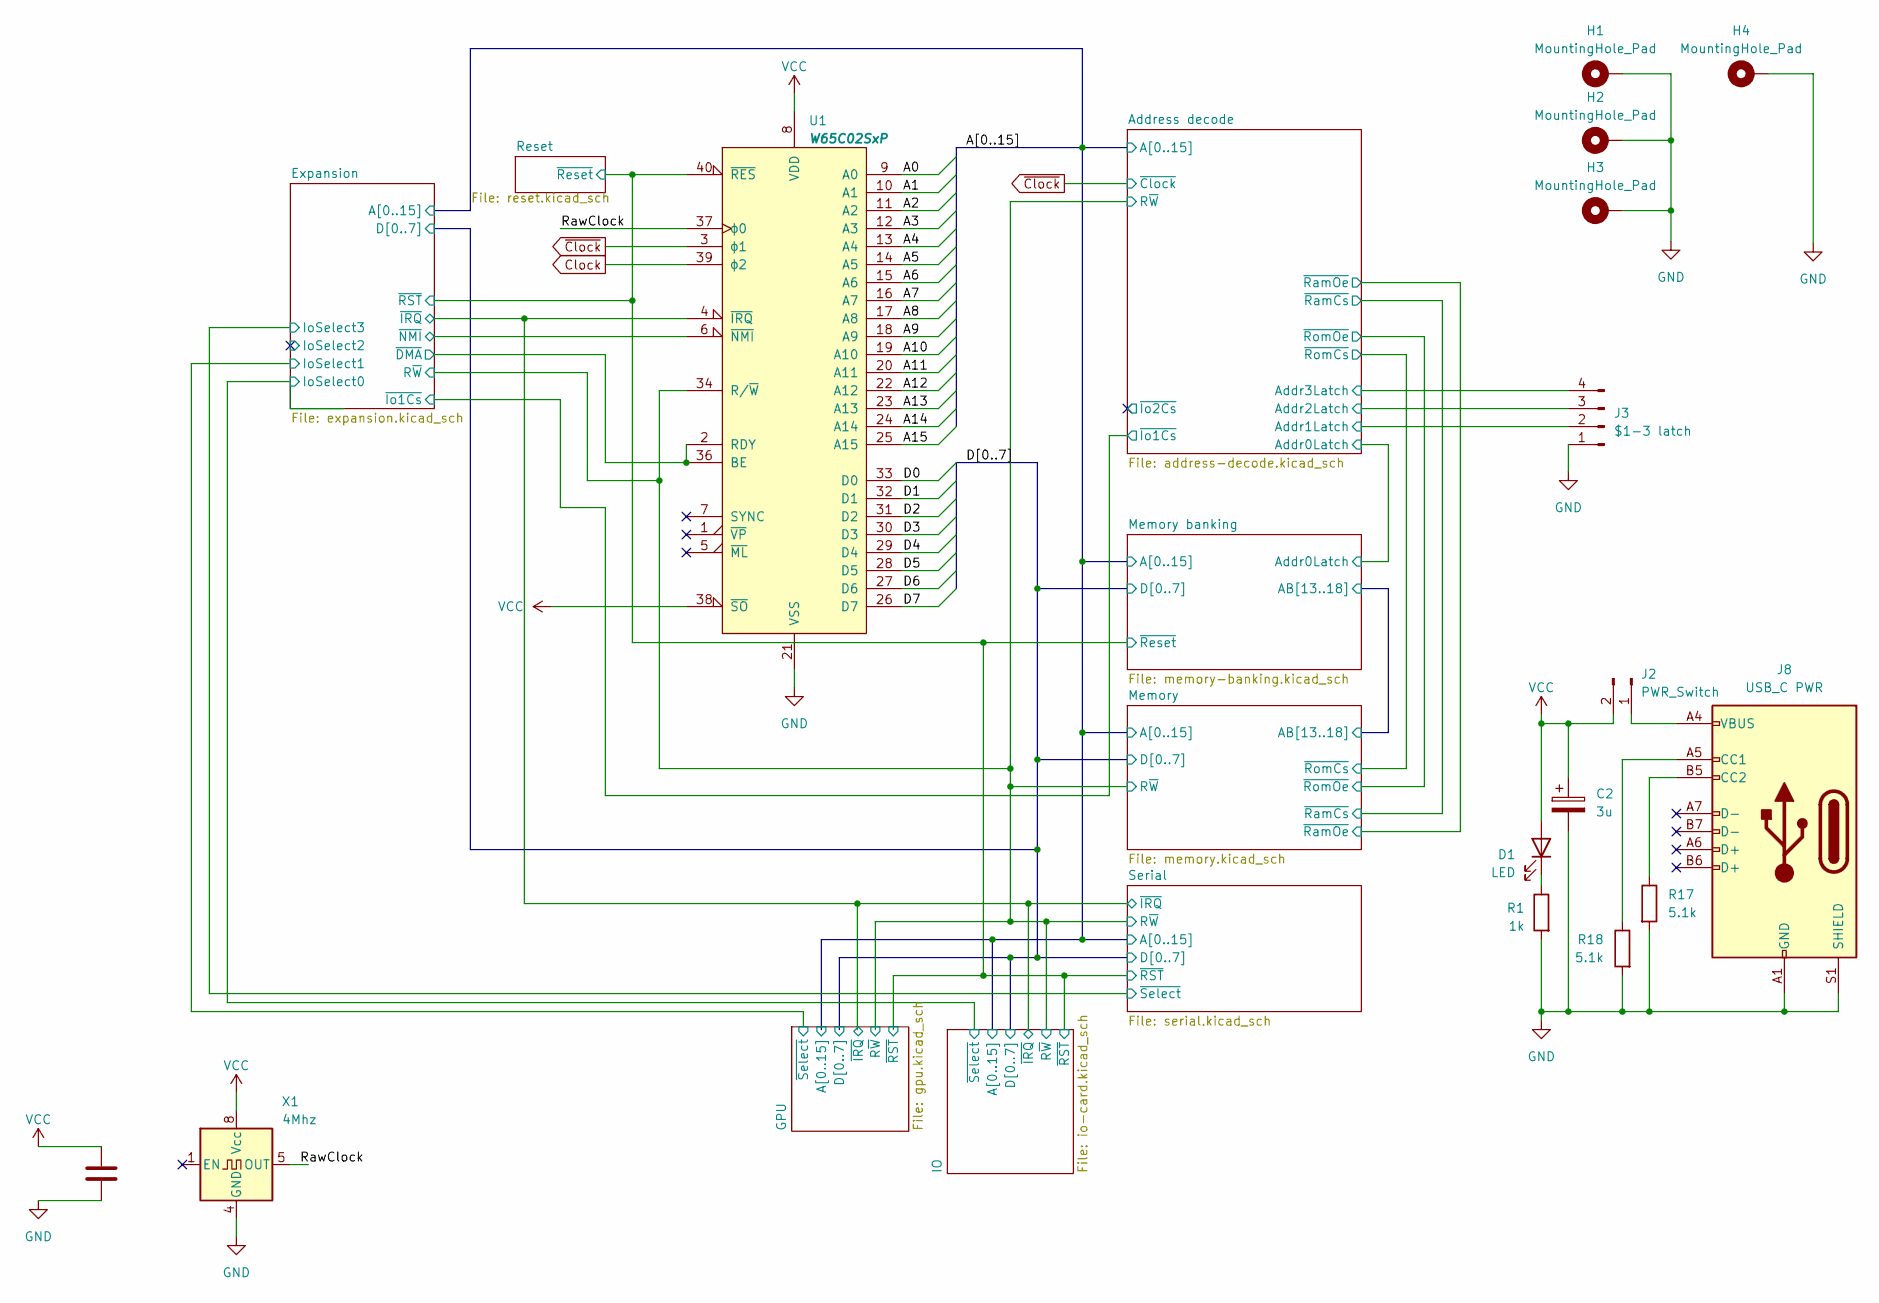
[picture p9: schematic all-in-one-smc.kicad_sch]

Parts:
C1: 100n; C_0805_2012Metric
C2: 3u; CP_Elec_8x5.4
D1: LED; LED_0805_2012Metric
H1, H2, H3, H4: MountingHole_Pad; MountingHole_2.5mm_Pad_Via
J2: PWR_Switch; PinHeader_1x02_P2.54mm_Vertical
J3: $1-3 latch; PinHeader_1x04_P2.54mm_Vertical
J8: USB_C PWR; USB_C_Receptacle_GCT_USB4105-xx-A_16P_TopMnt_Horizontal
R1: 1k; R_0805_2012Metric
R17, R18: 5.1k; R_0805_2012Metric
U1: W65C02SxP; PQFP-44_10x10mm_P0.8mm
X1: 4Mhz; Oscillator_DIP-8

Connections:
/A0: U1.9 (A0); also elsewhere on the board
/A1: U1.10 (A1); also elsewhere on the board
/A2: U1.11 (A2); also elsewhere on the board
/A3: U1.12 (A3); also elsewhere on the board
/A4: U1.13 (A4); also elsewhere on the board
/A5: U1.14 (A5); also elsewhere on the board
/A6: U1.15 (A6); also elsewhere on the board
/A7: U1.16 (A7); also elsewhere on the board
/A8: U1.17 (A8); also elsewhere on the board
/A9: U1.18 (A9); also elsewhere on the board
/A10: U1.19 (A10); also elsewhere on the board
/A11: U1.20 (A11); also elsewhere on the board
/A12: U1.22 (A12); also elsewhere on the board
/A13: U1.23 (A13); also elsewhere on the board
/A14: U1.24 (A14); also elsewhere on the board
/A15: U1.25 (A15); also elsewhere on the board
/Address decode/Addr1Latch: J3.2; also elsewhere on the board
/Address decode/Addr2Latch: J3.3; also elsewhere on the board
/Address decode/Addr3Latch: J3.4; also elsewhere on the board
/Address decode/R~W: U1.34 (R/~W); also elsewhere on the board
/D0: U1.33 (D0); also elsewhere on the board
/D1: U1.32 (D1); also elsewhere on the board
/D2: U1.31 (D2); also elsewhere on the board
/D3: U1.30 (D3); also elsewhere on the board
/D4: U1.29 (D4); also elsewhere on the board
/D5: U1.28 (D5); also elsewhere on the board
/D6: U1.27 (D6); also elsewhere on the board
/D7: U1.26 (D7); also elsewhere on the board
/Expansion/~DMA: U1.2 (RDY), U1.36 (BE); also elsewhere on the board
/Expansion/~IRQ: U1.4 (~IRQ); also elsewhere on the board
/Expansion/~NMI: U1.6 (~NMI); also elsewhere on the board
/Expansion/~RST: U1.40 (~RES); also elsewhere on the board
/RawClock: U1.37 (ϕ0), X1.5 (OUT)
Clock: U1.39 (ϕ2); also elsewhere on the board
unnamed: D1.1 (K), R1.1
unnamed: J2.1, J8.A4 (VBUS), J8.A9 (VBUS), J8.B4 (VBUS), J8.B9 (VBUS)
unnamed: J8.A5 (CC1), R18.1
unnamed: J8.B5 (CC2), R17.1
~Clock: U1.3 (ϕ1); also elsewhere on the board

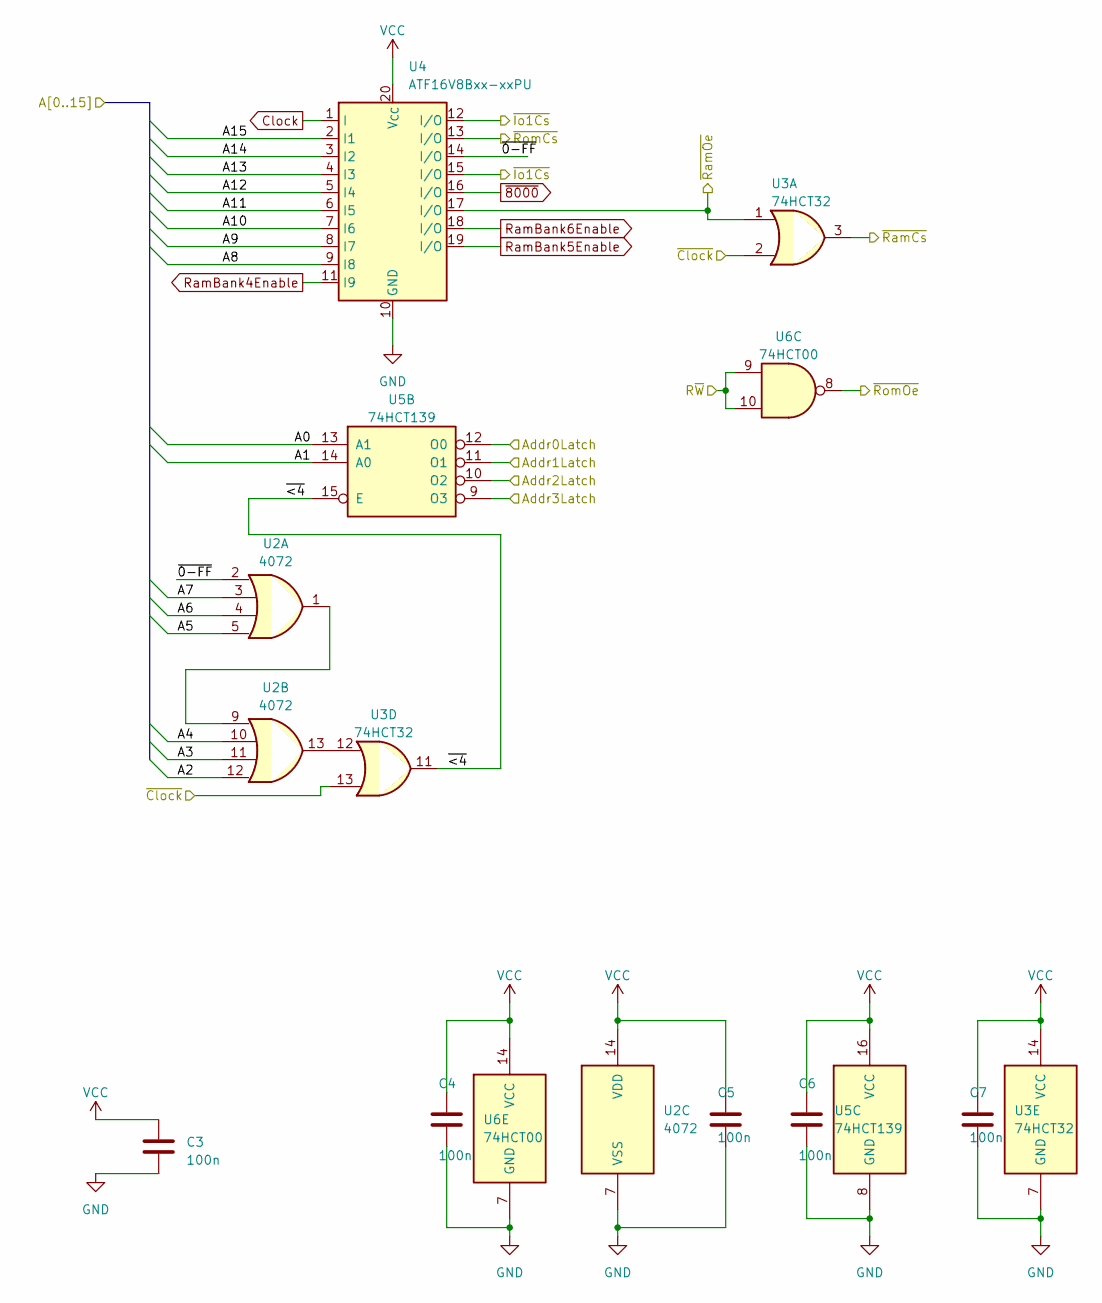
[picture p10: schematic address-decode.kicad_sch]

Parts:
C3, C4, C5, C6, C7: 100n; C_0805_2012Metric
U2: 4072; SOIC-14_3.9x8.7mm_P1.27mm
U3: 74HCT32; SOIC-14_3.9x8.7mm_P1.27mm
U4: ATF16V8Bxx-xxPU; DIP-20_W7.62mm_Socket
U5: 74HCT139; SOIC-16_3.9x9.9mm_P1.27mm
U6: 74HCT00; SOIC-14_3.9x8.7mm_P1.27mm

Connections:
/A0: U5.13 (A1); also elsewhere on the board
/A1: U5.14 (A0); also elsewhere on the board
/A2: U2.12; also elsewhere on the board
/A3: U2.11; also elsewhere on the board
/A4: U2.10; also elsewhere on the board
/A5: U2.5; also elsewhere on the board
/A6: U2.4; also elsewhere on the board
/A7: U2.3; also elsewhere on the board
/A8: U4.9 (I8); also elsewhere on the board
/A9: U4.8 (I7); also elsewhere on the board
/A10: U4.7 (I6); also elsewhere on the board
/A11: U4.6 (I5); also elsewhere on the board
/A12: U4.5 (I4); also elsewhere on the board
/A13: U4.4 (I3); also elsewhere on the board
/A14: U4.3 (I2); also elsewhere on the board
/A15: U4.2 (I1); also elsewhere on the board
/Address decode/Addr0Latch: U5.12 (O0); also elsewhere on the board
/Address decode/Addr1Latch: U5.11 (O1); also elsewhere on the board
/Address decode/Addr2Latch: U5.10 (O2); also elsewhere on the board
/Address decode/Addr3Latch: U5.9 (O3); also elsewhere on the board
/Address decode/R~W: U6.9, U6.10; also elsewhere on the board
/Address decode/~0-FF: U2.2, U4.14 (I/O)
/Address decode/~<4: U3.11, U5.15 (E)
/Address decode/~Io1Cs: U4.12 (I/O), U4.15 (I/O); also elsewhere on the board
/Address decode/~RamCs: U3.3; also elsewhere on the board
/Address decode/~RamOe: U3.1, U4.17 (I/O); also elsewhere on the board
/Address decode/~RomCs: U4.13 (I/O); also elsewhere on the board
/Address decode/~RomOe: U6.8; also elsewhere on the board
Clock: U4.1 (I); also elsewhere on the board
unnamed: U2.1, U2.9
unnamed: U2.13, U3.12
RamBank4Enable: U4.11 (I9); also elsewhere on the board
RamBank5Enable: U4.19 (I/O); also elsewhere on the board
RamBank6Enable: U4.18 (I/O); also elsewhere on the board
~8000: U4.16 (I/O); also elsewhere on the board
~Clock: U3.2, U3.13; also elsewhere on the board

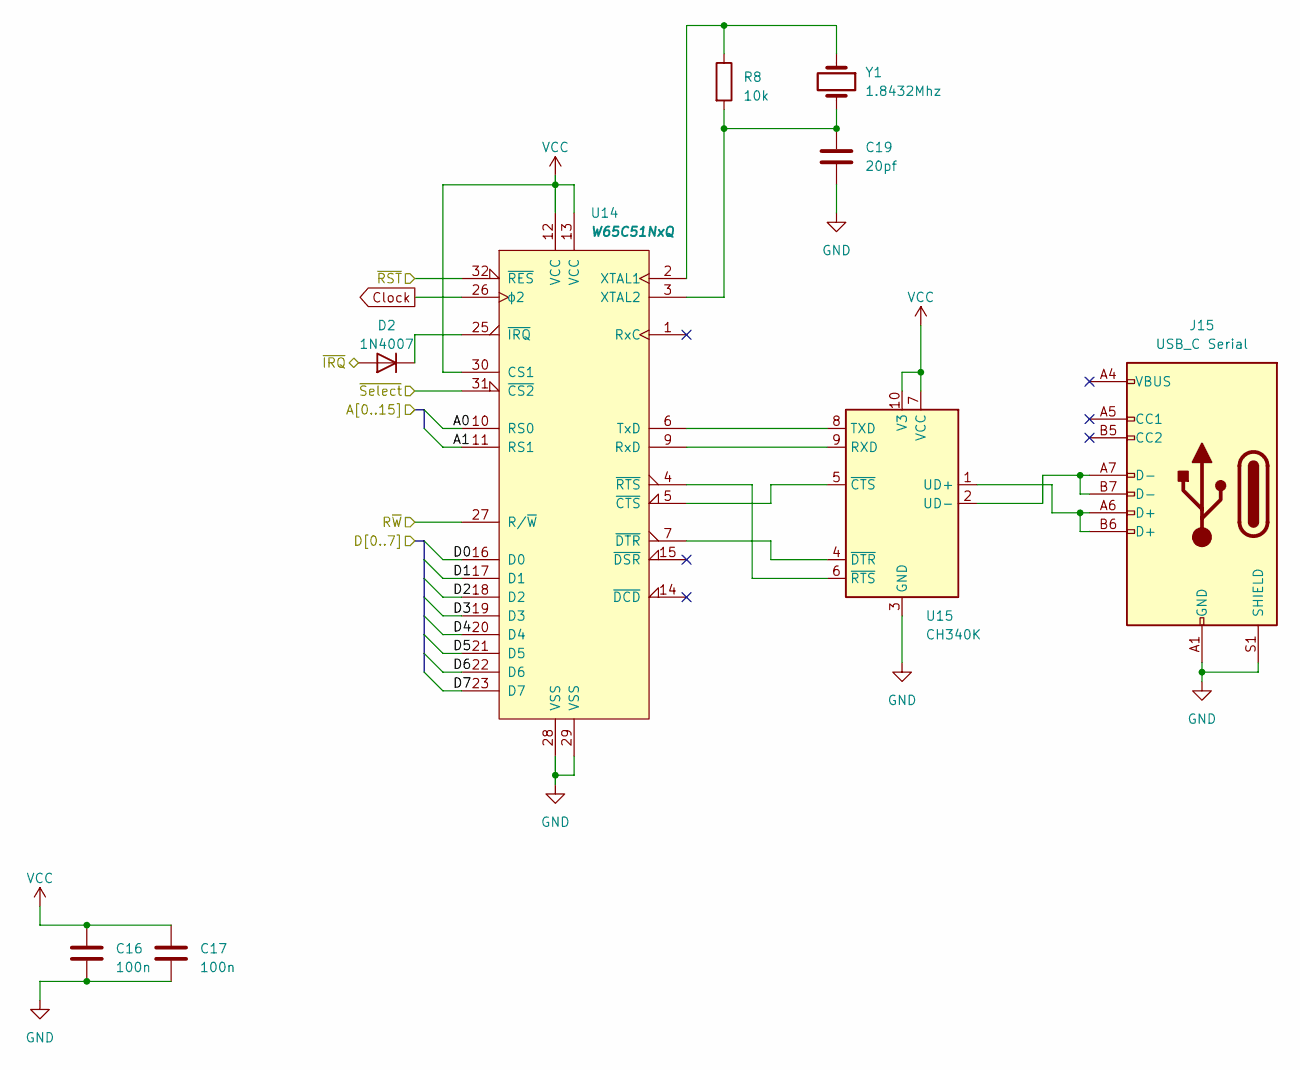
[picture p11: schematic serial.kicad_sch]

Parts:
C16, C17: 100n; C_0805_2012Metric
C19: 20pf; C_0805_2012Metric
D2: 1N4007; D_0805_2012Metric
J15: USB_C Serial; USB_C_Receptacle_GCT_USB4105-xx-A_16P_TopMnt_Horizontal
R8: 10k; R_0805_2012Metric
U14: W65C51NxQ; TQFP-32_7x7mm_P0.8mm
U15: CH340K; SSOP-10-1EP_3.9x4.9mm_P1mm_EP2.1x3.3mm
Y1: 1.8432Mhz; Crystal_SMD_3215-2Pin_3.2x1.5mm

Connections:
/A0: U14.10 (RS0); also elsewhere on the board
/A1: U14.11 (RS1); also elsewhere on the board
/Address decode/R~W: U14.27 (R/~W); also elsewhere on the board
/D0: U14.16 (D0); also elsewhere on the board
/D1: U14.17 (D1); also elsewhere on the board
/D2: U14.18 (D2); also elsewhere on the board
/D3: U14.19 (D3); also elsewhere on the board
/D4: U14.20 (D4); also elsewhere on the board
/D5: U14.21 (D5); also elsewhere on the board
/D6: U14.22 (D6); also elsewhere on the board
/D7: U14.23 (D7); also elsewhere on the board
/Expansion/IoSelect3: U14.31 (~CS2); also elsewhere on the board
/Expansion/~IRQ: D2.2 (A); also elsewhere on the board
/Expansion/~RST: U14.32 (~RES); also elsewhere on the board
Clock: U14.26 (ϕ2); also elsewhere on the board
unnamed: D2.1 (K), U14.25 (~IRQ)
unnamed: U14.9 (RxD), U15.9 (RXD)
unnamed: U14.6 (TxD), U15.8 (TXD)
unnamed: R8.1, U14.2 (XTAL1), Y1.1
unnamed: C19.1, R8.2, U14.3 (XTAL2), Y1.2
unnamed: U14.5 (~CTS), U15.5 (~CTS)
unnamed: U14.7 (~DTR), U15.4 (~DTR)
unnamed: U14.4 (~RTS), U15.6 (~RTS)
unnamed: J15.A6 (D+), J15.B6 (D+), U15.1 (UD+)
unnamed: J15.A7 (D-), J15.B7 (D-), U15.2 (UD-)

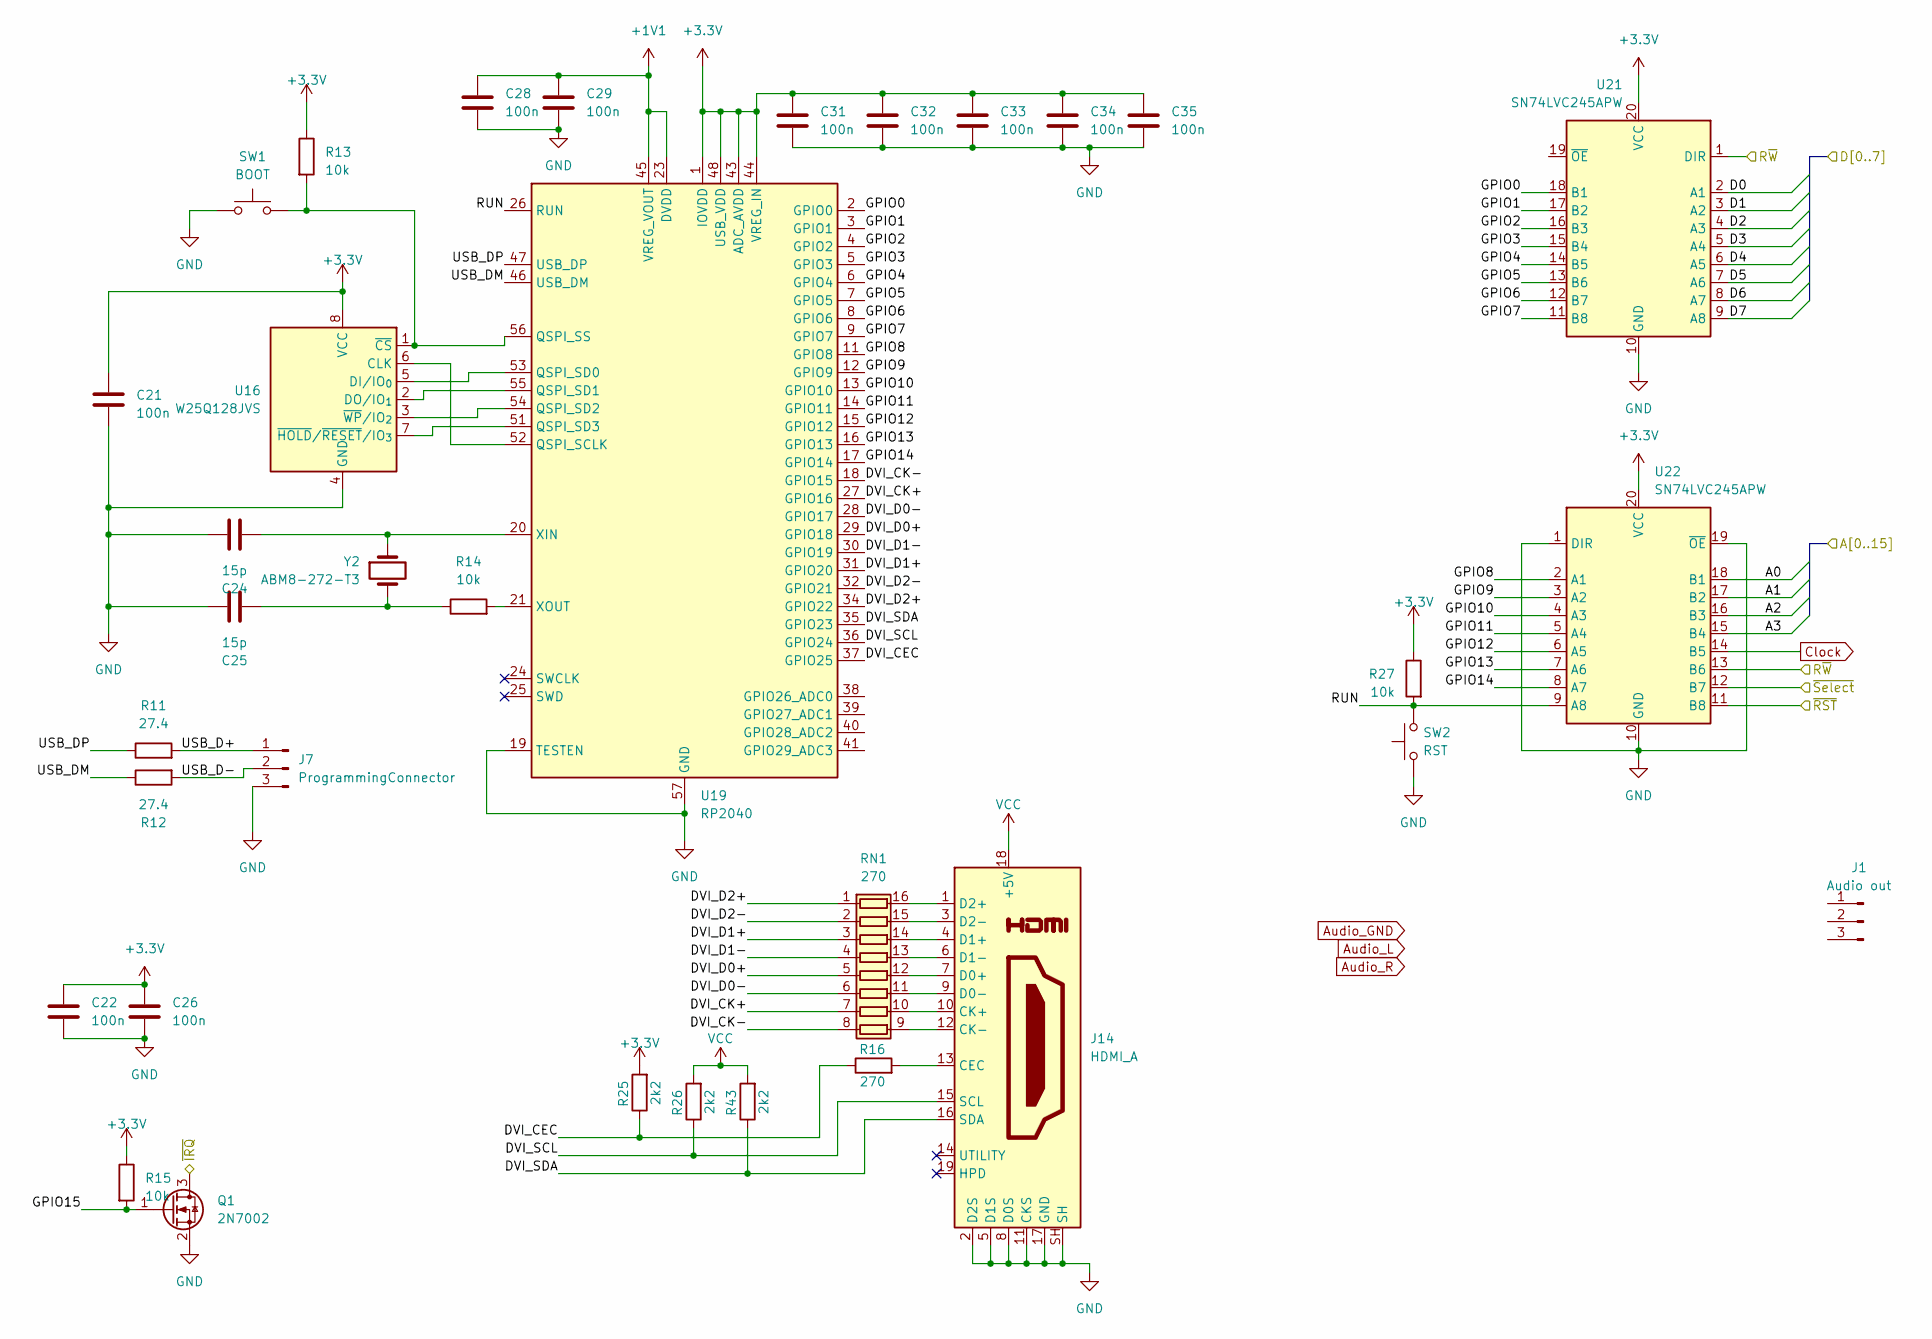
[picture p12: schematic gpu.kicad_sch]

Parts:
C21, C22, C26, C28, C29, C31, C32, C33, C34, C35: 100n; C_0805_2012Metric
C24, C25: 15p; C_0805_2012Metric
J1: Audio out; PinHeader_1x03_P2.54mm_Vertical
J7: ProgrammingConnector; PinHeader_1x03_P2.54mm_Vertical
J14: HDMI_A; HDMI_A_Molex_208658-1001_Horizontal
Q1: 2N7002; SOT-23
R11, R12: 27.4; R_0805_2012Metric
R13, R14, R15, R27: 10k; R_0805_2012Metric
R16: 270; R_0805_2012Metric
R25, R26, R43: 2k2; R_0805_2012Metric
RN1: 270; R_Array_Convex_8x0602
SW1: BOOT; SW_Push_1P1T_NO_CK_KMR2
SW2: RST; SW_Push_1P1T_NO_CK_KMR2
U16: W25Q128JVS; SOIC-8_5.3x5.3mm_P1.27mm
U19: RP2040; QFN-56-1EP_7x7mm_P0.4mm_EP3.2x3.2mm
U21, U22: SN74LVC245APW; TSSOP-20_4.4x6.5mm_P0.65mm
Y2: ABM8-272-T3; Crystal_SMD_Abracon_ABM8AIG-4Pin_3.2x2.5mm

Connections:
+1V1: C28.1, C29.1, U19.23 (DVDD), U19.45 (VREG_VOUT), U19.50 (DVDD)
/A0: U22.18 (B1); also elsewhere on the board
/A1: U22.17 (B2); also elsewhere on the board
/A2: U22.16 (B3); also elsewhere on the board
/A3: U22.15 (B4); also elsewhere on the board
/Address decode/R~W: U21.1 (DIR), U22.13 (B6); also elsewhere on the board
/D0: U21.2 (A1); also elsewhere on the board
/D1: U21.3 (A2); also elsewhere on the board
/D2: U21.4 (A3); also elsewhere on the board
/D3: U21.5 (A4); also elsewhere on the board
/D4: U21.6 (A5); also elsewhere on the board
/D5: U21.7 (A6); also elsewhere on the board
/D6: U21.8 (A7); also elsewhere on the board
/D7: U21.9 (A8); also elsewhere on the board
/Expansion/IoSelect1: U22.12 (B7); also elsewhere on the board
/Expansion/~RST: U22.11 (B8); also elsewhere on the board
/GPU/DVI_CEC: R16.1, R25.1, U19.37 (GPIO25)
/GPU/DVI_CK+: RN1.7 (R7.1), U19.27 (GPIO16)
/GPU/DVI_CK-: RN1.8 (R8.1), U19.18 (GPIO15)
/GPU/DVI_D0+: RN1.5 (R5.1), U19.29 (GPIO18)
/GPU/DVI_D0-: RN1.6 (R6.1), U19.28 (GPIO17)
/GPU/DVI_D1+: RN1.3 (R3.1), U19.31 (GPIO20)
/GPU/DVI_D1-: RN1.4 (R4.1), U19.30 (GPIO19)
/GPU/DVI_D2+: RN1.1 (R1.1), U19.34 (GPIO22)
/GPU/DVI_D2-: RN1.2 (R2.1), U19.32 (GPIO21)
/GPU/DVI_SCL: J14.15 (SCL), R26.1, U19.36 (GPIO24)
/GPU/DVI_SDA: J14.16 (SDA), R43.1, U19.35 (GPIO23)
/GPU/GPIO0: U19.2 (GPIO0), U21.18 (B1)
/GPU/GPIO1: U19.3 (GPIO1), U21.17 (B2)
/GPU/GPIO2: U19.4 (GPIO2), U21.16 (B3)
/GPU/GPIO3: U19.5 (GPIO3), U21.15 (B4)
/GPU/GPIO4: U19.6 (GPIO4), U21.14 (B5)
/GPU/GPIO5: U19.7 (GPIO5), U21.13 (B6)
/GPU/GPIO6: U19.8 (GPIO6), U21.12 (B7)
/GPU/GPIO7: U19.9 (GPIO7), U21.11 (B8)
/GPU/GPIO8: U19.11 (GPIO8), U22.2 (A1)
/GPU/GPIO9: U19.12 (GPIO9), U22.3 (A2)
/GPU/GPIO10: U19.13 (GPIO10), U22.4 (A3)
/GPU/GPIO11: U19.14 (GPIO11), U22.5 (A4)
/GPU/GPIO12: U19.15 (GPIO12), U22.6 (A5)
/GPU/GPIO13: U19.16 (GPIO13), U22.7 (A6)
/GPU/GPIO14: U19.17 (GPIO14), U22.8 (A7)
/GPU/GPIO15: Q1.1 (G), R15.2
/GPU/RUN: R27.2, SW2.2, U19.26 (RUN), U22.9 (A8)
/GPU/USB_D+: J7.1, R11.2
/GPU/USB_D-: J7.2, R12.2
/GPU/USB_DM: R12.1, U19.46 (USB_DM)
/GPU/USB_DP: R11.1, U19.47 (USB_DP)
/GPU/~IRQ: Q1.3 (D)
Clock: U22.14 (B5); also elsewhere on the board
unnamed: C25.1, R14.1, Y2.2
unnamed: J14.13 (CEC), R16.2
unnamed: J14.10 (CK+), RN1.10 (R7.2)
unnamed: J14.12 (CK-), RN1.9 (R8.2)
unnamed: J14.7 (D0+), RN1.12 (R5.2)
unnamed: J14.9 (D0-), RN1.11 (R6.2)
unnamed: J14.4 (D1+), RN1.14 (R3.2)
unnamed: J14.6 (D1-), RN1.13 (R4.2)
unnamed: J14.1 (D2+), RN1.16 (R1.2)
unnamed: J14.3 (D2-), RN1.15 (R2.2)
unnamed: U16.6 (CLK), U19.52 (QSPI_SCLK)
unnamed: U16.5 (DI/IO_{0}), U19.53 (QSPI_SD0)
unnamed: U16.2 (DO/IO_{1}), U19.55 (QSPI_SD1)
unnamed: R13.2, SW1.2, U16.1 (~CS), U19.56 (QSPI_SS)
unnamed: U16.7 (~HOLD/~RESET/IO_{3}), U19.51 (QSPI_SD3)
unnamed: U16.3 (~WP/IO_{2}), U19.54 (QSPI_SD2)
unnamed: C24.1, U19.20 (XIN), Y2.1
unnamed: R14.2, U19.21 (XOUT)

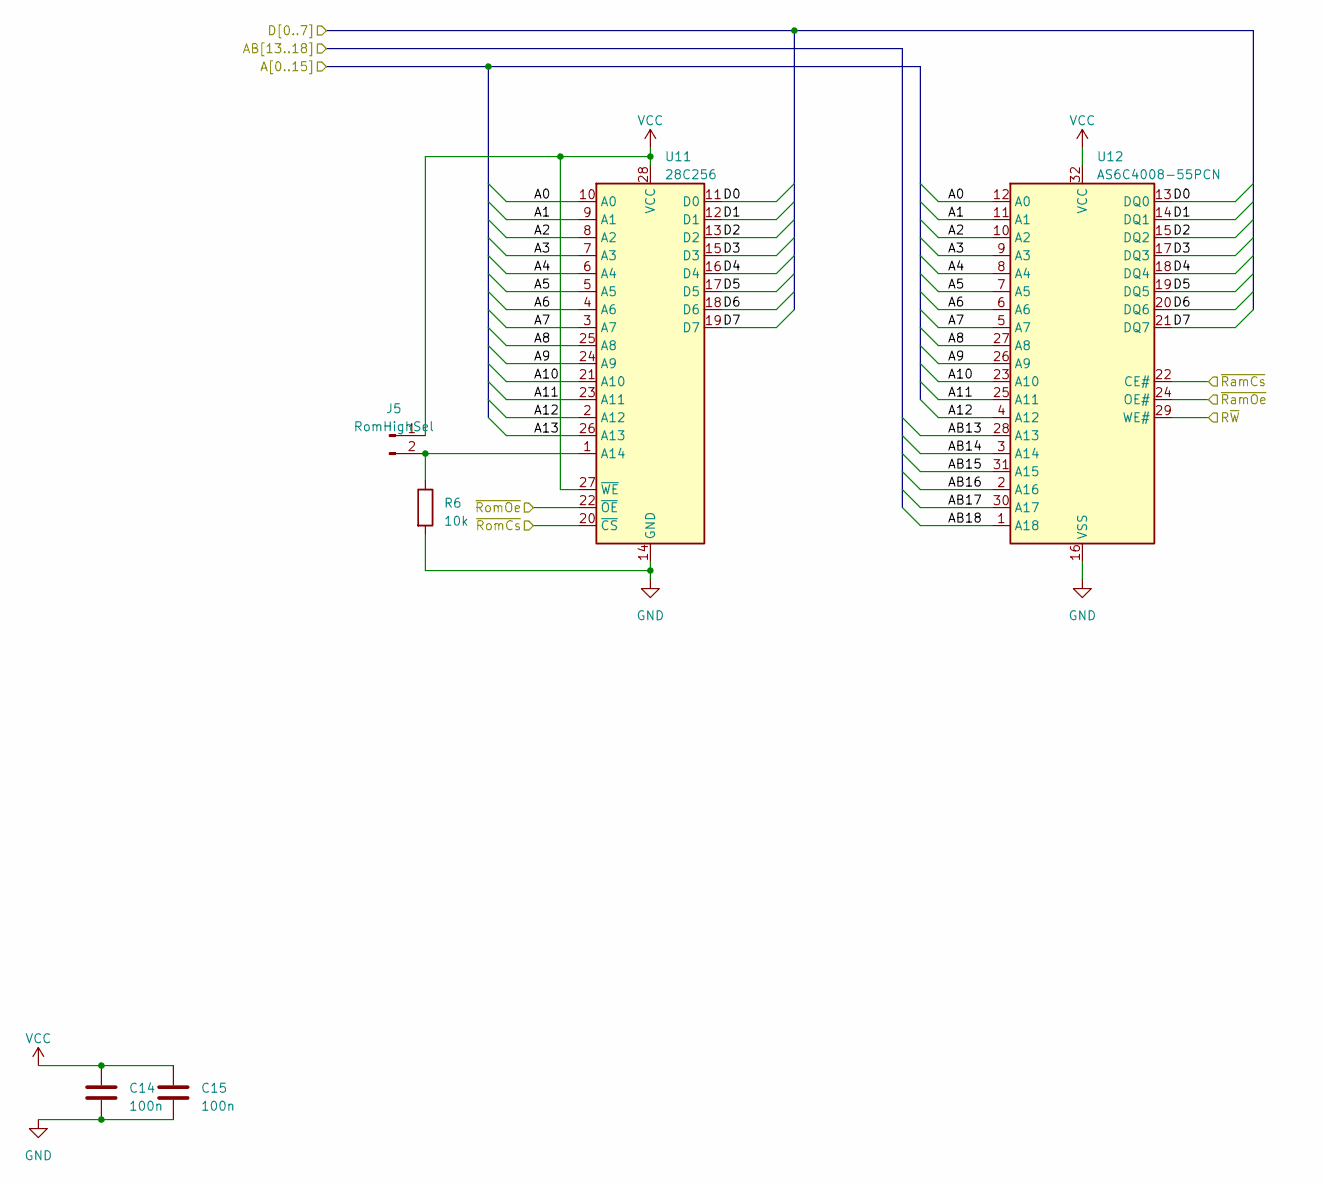
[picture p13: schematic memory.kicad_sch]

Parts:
C14, C15: 100n; C_0805_2012Metric
J5: RomHighSel; PinHeader_1x02_P2.54mm_Vertical
R6: 10k; R_0805_2012Metric
U11: 28C256; DIP-28_W15.24mm_Socket_LongPads
U12: AS6C4008-55PCN; SOIC-32_7.518x20.777mm_P1.27mm

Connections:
/A0: U11.10 (A0), U12.12 (A0); also elsewhere on the board
/A1: U11.9 (A1), U12.11 (A1); also elsewhere on the board
/A2: U11.8 (A2), U12.10 (A2); also elsewhere on the board
/A3: U11.7 (A3), U12.9 (A3); also elsewhere on the board
/A4: U11.6 (A4), U12.8 (A4); also elsewhere on the board
/A5: U11.5 (A5), U12.7 (A5); also elsewhere on the board
/A6: U11.4 (A6), U12.6 (A6); also elsewhere on the board
/A7: U11.3 (A7), U12.5 (A7); also elsewhere on the board
/A8: U11.25 (A8), U12.27 (A8); also elsewhere on the board
/A9: U11.24 (A9), U12.26 (A9); also elsewhere on the board
/A10: U11.21 (A10), U12.23 (A10); also elsewhere on the board
/A11: U11.23 (A11), U12.25 (A11); also elsewhere on the board
/A12: U11.2 (A12), U12.4 (A12); also elsewhere on the board
/A13: U11.26 (A13); also elsewhere on the board
/Address decode/R~W: U12.29 (WE#); also elsewhere on the board
/Address decode/~RamCs: U12.22 (CE#); also elsewhere on the board
/Address decode/~RamOe: U12.24 (OE#); also elsewhere on the board
/Address decode/~RomCs: U11.20 (~CS); also elsewhere on the board
/Address decode/~RomOe: U11.22 (~OE); also elsewhere on the board
/D0: U11.11 (D0), U12.13 (DQ0); also elsewhere on the board
/D1: U11.12 (D1), U12.14 (DQ1); also elsewhere on the board
/D2: U11.13 (D2), U12.15 (DQ2); also elsewhere on the board
/D3: U11.15 (D3), U12.17 (DQ3); also elsewhere on the board
/D4: U11.16 (D4), U12.18 (DQ4); also elsewhere on the board
/D5: U11.17 (D5), U12.19 (DQ5); also elsewhere on the board
/D6: U11.18 (D6), U12.20 (DQ6); also elsewhere on the board
/D7: U11.19 (D7), U12.21 (DQ7); also elsewhere on the board
/Memory banking/AB13: U12.28 (A13); also elsewhere on the board
/Memory banking/AB14: U12.3 (A14); also elsewhere on the board
/Memory banking/AB15: U12.31 (A15); also elsewhere on the board
/Memory banking/AB16: U12.2 (A16); also elsewhere on the board
/Memory banking/AB17: U12.30 (A17); also elsewhere on the board
/Memory banking/AB18: U12.1 (A18); also elsewhere on the board
unnamed: J5.2, R6.1, U11.1 (A14)

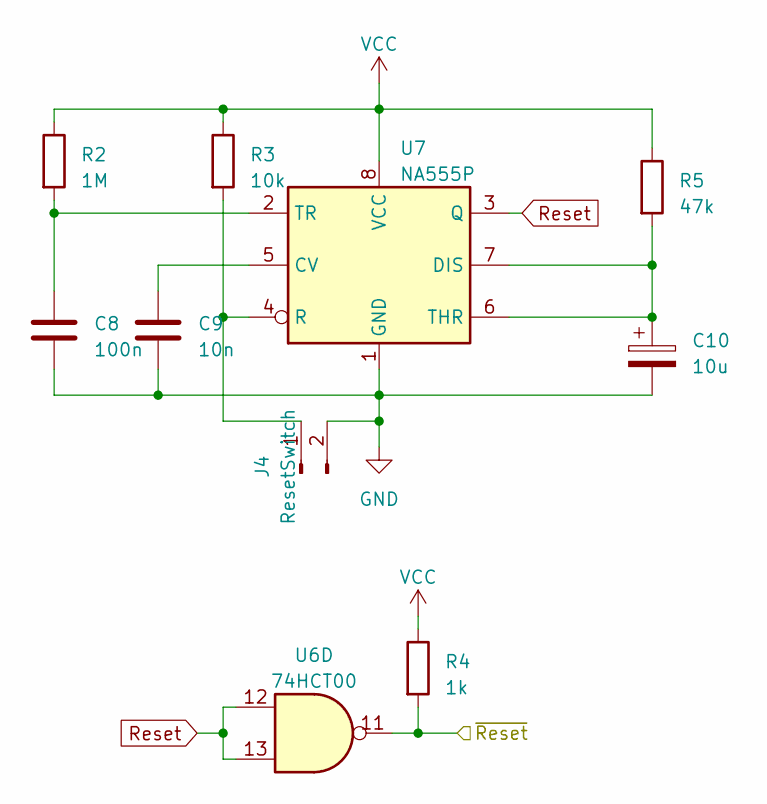
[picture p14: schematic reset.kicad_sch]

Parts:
C8: 100n; C_0805_2012Metric
C9: 10n; C_0805_2012Metric
C10: 10u; CP_Elec_4x3
J4: ResetSwitch; PinHeader_1x02_P2.54mm_Vertical
R2: 1M; R_0805_2012Metric
R3: 10k; R_0805_2012Metric
R4: 1k; R_0805_2012Metric
R5: 47k; R_0805_2012Metric
U6: 74HCT00; SOIC-14_3.9x8.7mm_P1.27mm
U7: NA555P; SOIC-8_3.9x4.9mm_P1.27mm

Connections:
/Expansion/~RST: R4.2, U6.11; also elsewhere on the board
unnamed: J4.1, R3.2, U7.4 (R)
unnamed: C9.1, U7.5 (CV)
unnamed: C10.1, R5.2, U7.6 (THR), U7.7 (DIS)
unnamed: C8.1, R2.2, U7.2 (TR)
Reset: U6.12, U6.13, U7.3 (Q)

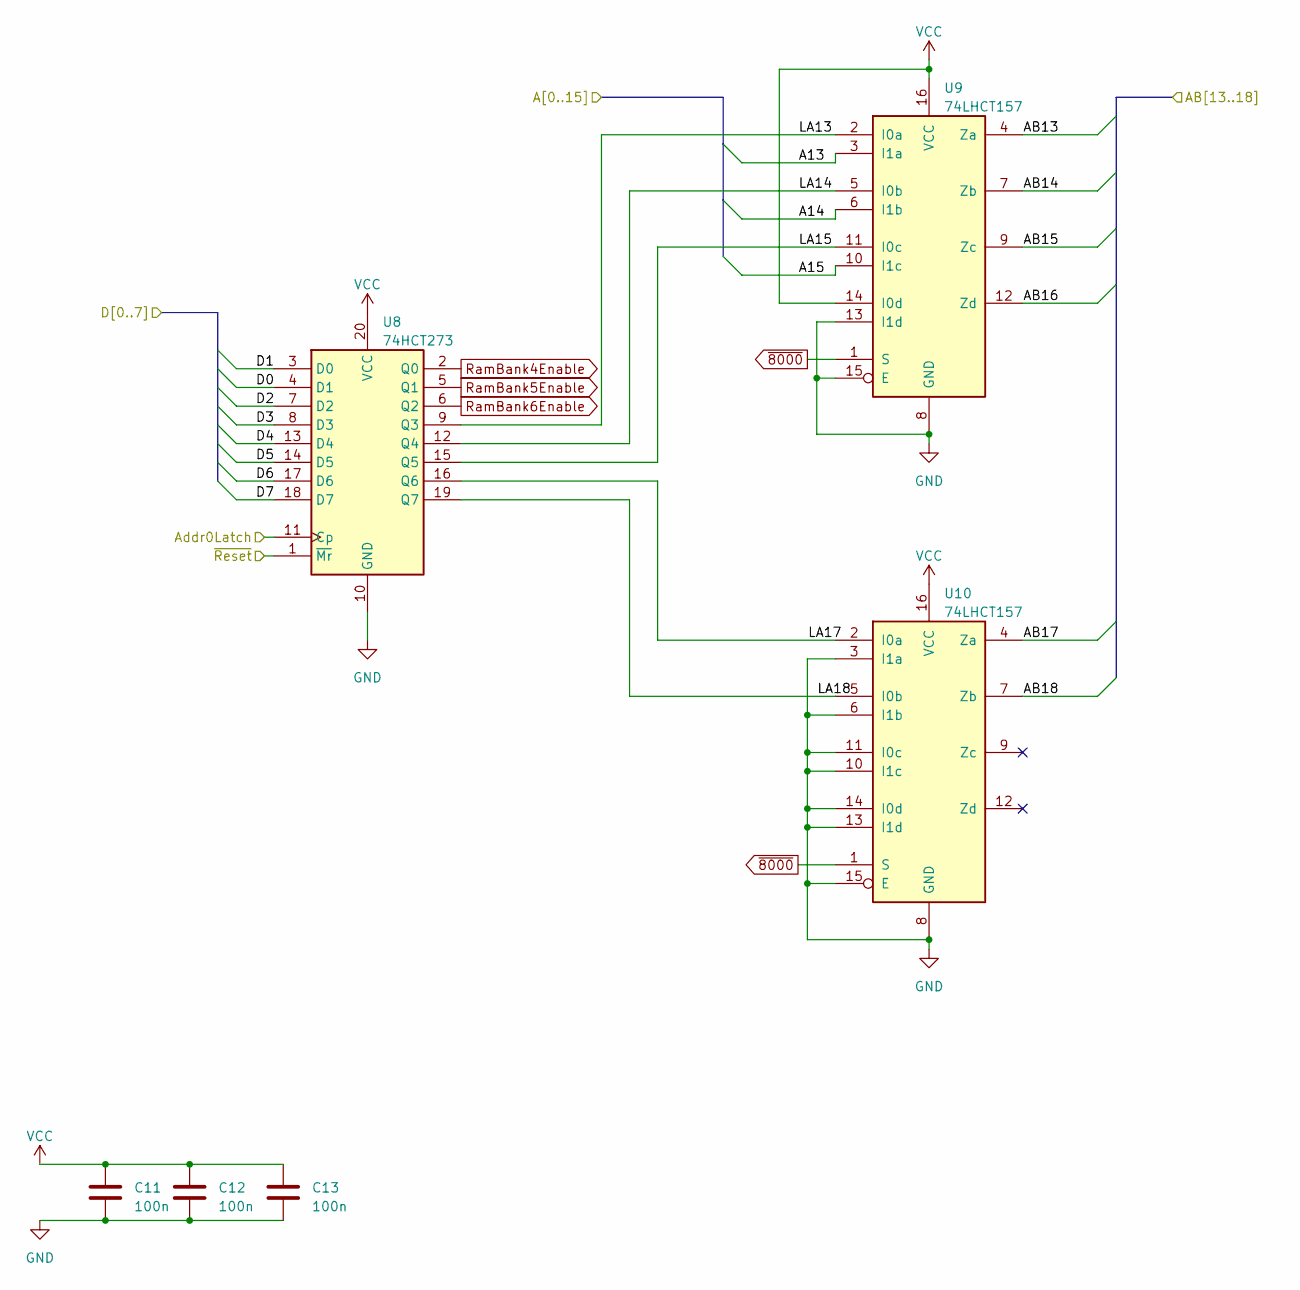
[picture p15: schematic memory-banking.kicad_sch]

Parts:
C11, C12, C13: 100n; C_0805_2012Metric
U8: 74HCT273; SOIC-20W_7.5x12.8mm_P1.27mm
U9, U10: 74LHCT157; SOIC-16_3.9x9.9mm_P1.27mm

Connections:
/A13: U9.3 (I1a); also elsewhere on the board
/A14: U9.6 (I1b); also elsewhere on the board
/A15: U9.10 (I1c); also elsewhere on the board
/Address decode/Addr0Latch: U8.11 (Cp); also elsewhere on the board
/D0: U8.4 (D1); also elsewhere on the board
/D1: U8.3 (D0); also elsewhere on the board
/D2: U8.7 (D2); also elsewhere on the board
/D3: U8.8 (D3); also elsewhere on the board
/D4: U8.13 (D4); also elsewhere on the board
/D5: U8.14 (D5); also elsewhere on the board
/D6: U8.17 (D6); also elsewhere on the board
/D7: U8.18 (D7); also elsewhere on the board
/Expansion/~RST: U8.1 (~Mr); also elsewhere on the board
/Memory banking/AB13: U9.4 (Za); also elsewhere on the board
/Memory banking/AB14: U9.7 (Zb); also elsewhere on the board
/Memory banking/AB15: U9.9 (Zc); also elsewhere on the board
/Memory banking/AB16: U9.12 (Zd); also elsewhere on the board
/Memory banking/AB17: U10.4 (Za); also elsewhere on the board
/Memory banking/AB18: U10.7 (Zb); also elsewhere on the board
/Memory banking/LA13: U8.9 (Q3), U9.2 (I0a)
/Memory banking/LA14: U8.12 (Q4), U9.5 (I0b)
/Memory banking/LA15: U8.15 (Q5), U9.11 (I0c)
/Memory banking/LA17: U8.16 (Q6), U10.2 (I0a)
/Memory banking/LA18: U8.19 (Q7), U10.5 (I0b)
RamBank4Enable: U8.2 (Q0); also elsewhere on the board
RamBank5Enable: U8.5 (Q1); also elsewhere on the board
RamBank6Enable: U8.6 (Q2); also elsewhere on the board
~8000: U9.1 (S), U10.1 (S); also elsewhere on the board

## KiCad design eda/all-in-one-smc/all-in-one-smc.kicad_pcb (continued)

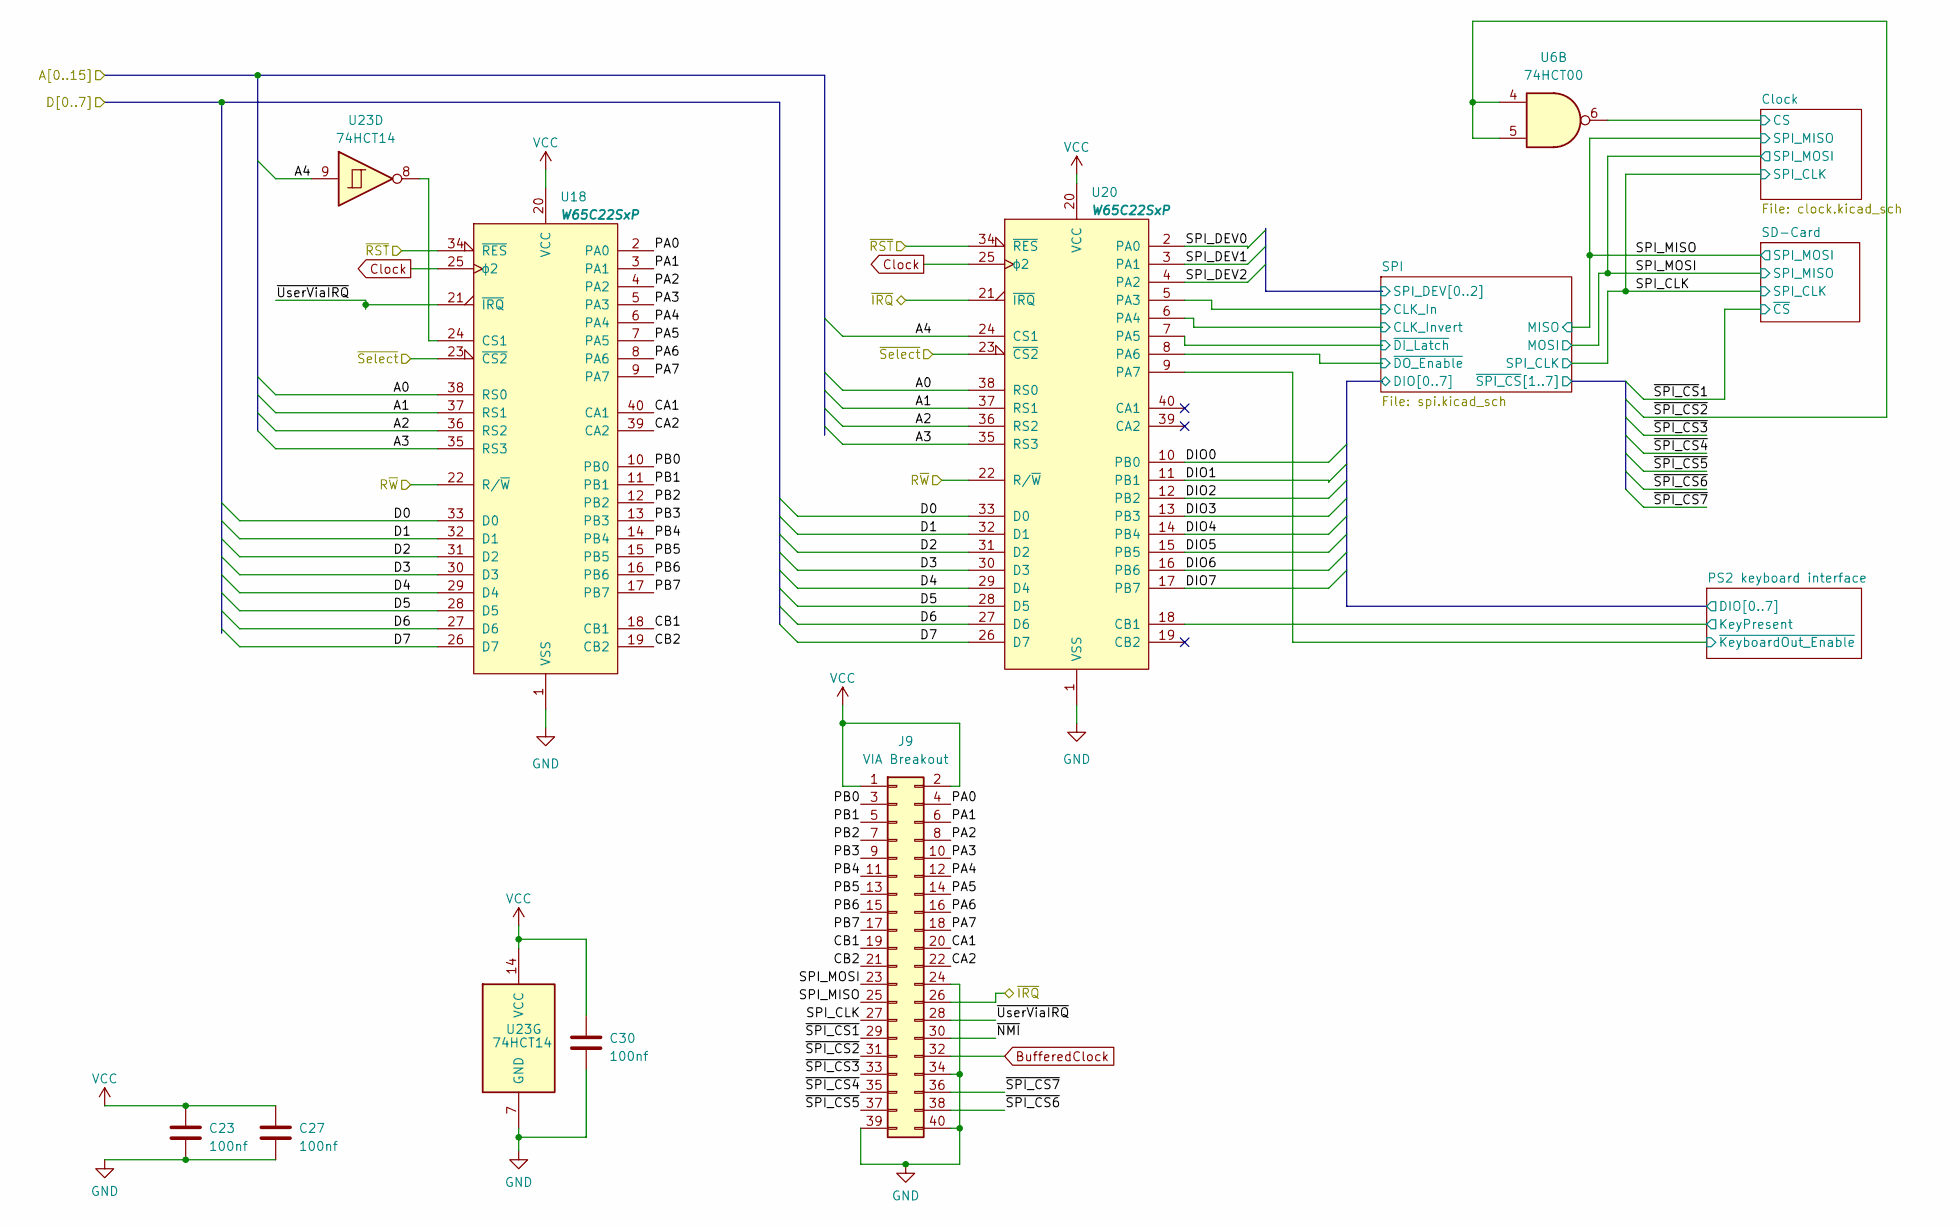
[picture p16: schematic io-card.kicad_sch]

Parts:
C23, C27, C30: 100nf; C_0805_2012Metric
J9: VIA Breakout; PinHeader_2x20_P2.54mm_Horizontal
U6: 74HCT00; SOIC-14_3.9x8.7mm_P1.27mm
U18, U20: W65C22SxP; PLCC-44_16.6x16.6mm_P1.27mm
U23: 74HCT14; SOIC-14_3.9x8.7mm_P1.27mm

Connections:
/A0: U18.38 (RS0), U20.38 (RS0); also elsewhere on the board
/A1: U18.37 (RS1), U20.37 (RS1); also elsewhere on the board
/A2: U18.36 (RS2), U20.36 (RS2); also elsewhere on the board
/A3: U18.35 (RS3), U20.35 (RS3); also elsewhere on the board
/A4: U20.24 (CS1), U23.9; also elsewhere on the board
/Address decode/R~W: U18.22 (R/~W), U20.22 (R/~W); also elsewhere on the board
/D0: U18.33 (D0), U20.33 (D0); also elsewhere on the board
/D1: U18.32 (D1), U20.32 (D1); also elsewhere on the board
/D2: U18.31 (D2), U20.31 (D2); also elsewhere on the board
/D3: U18.30 (D3), U20.30 (D3); also elsewhere on the board
/D4: U18.29 (D4), U20.29 (D4); also elsewhere on the board
/D5: U18.28 (D5), U20.28 (D5); also elsewhere on the board
/D6: U18.27 (D6), U20.27 (D6); also elsewhere on the board
/D7: U18.26 (D7), U20.26 (D7); also elsewhere on the board
/Expansion/IoSelect0: U18.23 (~CS2), U20.23 (~CS2); also elsewhere on the board
/Expansion/~IRQ: J9.26, U20.21 (~IRQ); also elsewhere on the board
/Expansion/~RST: U18.34 (~RES), U20.34 (~RES); also elsewhere on the board
/IO/CA1: J9.20, U18.40 (CA1)
/IO/CA2: J9.22, U18.39 (CA2)
/IO/CB1: J9.19, U18.18 (CB1)
/IO/CB2: J9.21, U18.19 (CB2)
/IO/Clock/CS: U6.6; also elsewhere on the board
/IO/PA2: J9.8, U18.4 (PA2)
/IO/PA5: J9.14, U18.7 (PA5)
/IO/PA6: J9.16, U18.8 (PA6)
/IO/PA7: J9.18, U18.9 (PA7)
/IO/PB3: J9.9, U18.13 (PB3)
/IO/PB6: J9.15, U18.16 (PB6)
/IO/PB7: J9.17, U18.17 (PB7)
/IO/PS2 keyboard interface/DIO0: U20.10 (PB0); also elsewhere on the board
/IO/PS2 keyboard interface/DIO1: U20.11 (PB1); also elsewhere on the board
/IO/PS2 keyboard interface/DIO2: U20.12 (PB2); also elsewhere on the board
/IO/PS2 keyboard interface/DIO3: U20.13 (PB3); also elsewhere on the board
/IO/PS2 keyboard interface/DIO4: U20.14 (PB4); also elsewhere on the board
/IO/PS2 keyboard interface/DIO5: U20.15 (PB5); also elsewhere on the board
/IO/PS2 keyboard interface/DIO6: U20.16 (PB6); also elsewhere on the board
/IO/PS2 keyboard interface/DIO7: U20.17 (PB7); also elsewhere on the board
/IO/PS2 keyboard interface/KeyPresent: U20.18 (CB1); also elsewhere on the board
/IO/PS2 keyboard interface/~KeyboardOut_Enable: U20.9 (PA7)
/IO/SPI/CLK_Invert: U20.6 (PA4); also elsewhere on the board
/IO/SPI/SPI_DEV0: U20.2 (PA0); also elsewhere on the board
/IO/SPI/SPI_DEV1: U20.3 (PA1); also elsewhere on the board
/IO/SPI/SPI_DEV2: U20.4 (PA2); also elsewhere on the board
/IO/SPI/~DI_Latch: U20.7 (PA5); also elsewhere on the board
/IO/SPI/~DO_Enable: U20.8 (PA6); also elsewhere on the board
/IO/SPI_CLK: J9.27, U20.5 (PA3); also elsewhere on the board
/IO/SPI_MISO: J9.25; also elsewhere on the board
/IO/SPI_MOSI: J9.23; also elsewhere on the board
/IO/~NMI: J9.30
/IO/~SPI_CS1: J9.29
/IO/~SPI_CS2: J9.31, U6.4, U6.5
/IO/~SPI_CS3: J9.33
/IO/~SPI_CS4: J9.35
/IO/~SPI_CS5: J9.37
/IO/~SPI_CS6: J9.38
/IO/~SPI_CS7: J9.36
/IO/~UserViaIRQ: J9.28, U18.21 (~IRQ)
BufferedClock: J9.32
Clock: U18.25 (ϕ2), U20.25 (ϕ2); also elsewhere on the board
unnamed: U18.24 (CS1), U23.8

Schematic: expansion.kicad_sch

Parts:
C18: 1u; CP_Elec_5x3
C20: 100n; C_0805_2012Metric
J6: Expansion; PinHeader_2x25_P2.54mm_Vertical
R7, R9, R10: 10k; R_0805_2012Metric
U13: 74HCT138; SOIC-16_3.9x9.9mm_P1.27mm

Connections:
/A0: J6.5; also elsewhere on the board
/A1: J6.7; also elsewhere on the board
/A2: J6.9; also elsewhere on the board
/A3: J6.11; also elsewhere on the board
/A4: J6.13; also elsewhere on the board
/A5: J6.15; also elsewhere on the board
/A6: J6.17, U13.1 (A0); also elsewhere on the board
/A7: J6.19, U13.2 (A1); also elsewhere on the board
/A8: J6.21, U13.3 (A2); also elsewhere on the board
/A9: J6.23; also elsewhere on the board
/A10: J6.25; also elsewhere on the board
/A11: J6.27; also elsewhere on the board
/A12: J6.29; also elsewhere on the board
/A13: J6.31; also elsewhere on the board
/A14: J6.33; also elsewhere on the board
/A15: J6.35; also elsewhere on the board
/Address decode/R~W: J6.41; also elsewhere on the board
/Address decode/~Io1Cs: U13.4 (E1), U13.5 (E2); also elsewhere on the board
/D0: J6.4; also elsewhere on the board
/D1: J6.6; also elsewhere on the board
/D2: J6.8; also elsewhere on the board
/D3: J6.10; also elsewhere on the board
/D4: J6.12; also elsewhere on the board
/D5: J6.14; also elsewhere on the board
/D6: J6.16; also elsewhere on the board
/D7: J6.18; also elsewhere on the board
/Expansion/IoSelect0: J6.22, U13.15 (O0); also elsewhere on the board
/Expansion/IoSelect1: J6.24, U13.14 (O1); also elsewhere on the board
/Expansion/IoSelect2: J6.26, U13.13 (O2)
/Expansion/IoSelect3: J6.28, U13.12 (O3); also elsewhere on the board
/Expansion/IoSelect4: J6.30, U13.11 (O4)
/Expansion/IoSelect5: J6.32, U13.10 (O5)
/Expansion/IoSelect6: J6.34, U13.9 (O6)
/Expansion/IoSelect7: J6.36, U13.7 (O7)
/Expansion/~DMA: J6.43, R7.2; also elsewhere on the board
/Expansion/~ExtRomCS: J6.48
/Expansion/~IRQ: J6.44, R10.2; also elsewhere on the board
/Expansion/~NMI: J6.42, R9.2; also elsewhere on the board
/Expansion/~RST: J6.40; also elsewhere on the board
Audio_GND: J6.47
Audio_L: J6.49
Audio_R: J6.45
Clock: J6.39; also elsewhere on the board

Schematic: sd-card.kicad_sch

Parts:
C44: 100nf; C_0805_2012Metric
C45: 100nf; CP_Elec_3x5.3
J11: SD-Card module; PinHeader_1x08_P2.54mm_Vertical
J12: SD_Card; SD_Kyocera_145638109511859+; not fitted
JP6: SD-Card voltage select; SolderJumper-3_P1.3mm_Open_Pad1.0x1.5mm
Q2, Q3, Q4, Q5: 2N7002; SOT-23
R30, R31, R32, R33, R34, R35, R36, R37: 10k; R_0805_2012Metric
R38: 370R; R_0805_2012Metric
R39: 220R; R_0805_2012Metric
U32: LM317L; SOT-223-3_TabPin2

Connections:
/IO/SPI/~SPI_CS1: Q2.3 (D), R34.2
/IO/SPI_CLK: Q4.3 (D), R36.2; also elsewhere on the board
/IO/SPI_MISO: Q3.3 (D), R35.2; also elsewhere on the board
/IO/SPI_MOSI: Q5.3 (D), R37.2; also elsewhere on the board
unnamed: J11.8, JP6.2 (C)
unnamed: R38.2, R39.1, U32.1 (ADJ)

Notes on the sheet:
VOUT = 1.25 * ( 1 + R2/R1 )
3.3 ~ 1.25 * ( 1 + 370/220 )

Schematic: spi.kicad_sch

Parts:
C38, C40, C41, C42, C43: 100nf; C_0805_2012Metric
J13: CS_Invert_Selection; PinHeader_2x03_P2.54mm_Horizontal
R40, R41, R42: 10k; R_0805_2012Metric
U23: 74HCT14; SOIC-14_3.9x8.7mm_P1.27mm
U24: 74HCT86; SOIC-14_3.9x8.7mm_P1.27mm
U26: 74HCT595; SOIC-16_3.9x9.9mm_P1.27mm
U27: 74HCT165; SOIC-16_3.9x9.9mm_P1.27mm
U31: 74HCT138; SOIC-16_3.9x9.9mm_P1.27mm

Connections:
/A4: U23.9; also elsewhere on the board
/IO/PS2 keyboard interface/DIO0: U26.7 (QH), U27.6 (D7); also elsewhere on the board
/IO/PS2 keyboard interface/DIO1: U26.6 (QG), U27.5 (D6); also elsewhere on the board
/IO/PS2 keyboard interface/DIO2: U26.5 (QF), U27.4 (D5); also elsewhere on the board
/IO/PS2 keyboard interface/DIO3: U26.4 (QE), U27.3 (D4); also elsewhere on the board
/IO/PS2 keyboard interface/DIO4: U26.3 (QD), U27.14 (D3); also elsewhere on the board
/IO/PS2 keyboard interface/DIO5: U26.2 (QC), U27.13 (D2); also elsewhere on the board
/IO/PS2 keyboard interface/DIO6: U26.1 (QB), U27.12 (D1); also elsewhere on the board
/IO/PS2 keyboard interface/DIO7: U26.15 (QA), U27.11 (D0); also elsewhere on the board
/IO/PS2 keyboard interface/KeyPresent: U23.6; also elsewhere on the board
/IO/PS2 keyboard interface/~KeyboardClk: U23.4; also elsewhere on the board
/IO/SPI/ ~SPI_CS1: U31.14 (O1)
/IO/SPI/CLK_Invert: U24.2; also elsewhere on the board
/IO/SPI/Conditioned_CLK: U23.13, U24.3, U26.11 (SRCLK)
/IO/SPI/SPI_DEV0: U31.1 (A0); also elsewhere on the board
/IO/SPI/SPI_DEV1: U31.2 (A1); also elsewhere on the board
/IO/SPI/SPI_DEV2: U31.3 (A2); also elsewhere on the board
/IO/SPI/~Conditioned_CLK: U23.12, U27.2 (CP)
/IO/SPI/~DI_Latch: U27.1 (~PL); also elsewhere on the board
/IO/SPI/~DO_Enable: U23.11, U26.13 (~OE); also elsewhere on the board
/IO/SPI/~SPI_CS2: U31.13 (O2)
/IO/SPI/~SPI_CS3: U31.12 (O3)
/IO/SPI/~SPI_CS4: U31.11 (O4)
/IO/SPI/~SPI_CS5: U24.6
/IO/SPI/~SPI_CS6: U24.8
/IO/SPI/~SPI_CS7: U24.11
/IO/SPI_CLK: U24.1; also elsewhere on the board
/IO/SPI_MISO: U26.14 (SER); also elsewhere on the board
/IO/SPI_MOSI: U27.9 (Q7); also elsewhere on the board
unnamed 158: U23.2; also elsewhere on the board
unnamed 159: U23.5; also elsewhere on the board
unnamed 165: U23.1, U23.3; also elsewhere on the board
unnamed: J13.1, R40.1, U24.13
unnamed: J13.3, R41.1, U24.10
unnamed: J13.5, R42.1, U24.5
unnamed 199: U23.8; also elsewhere on the board
unnamed: U23.10, U26.12 (RCLK)
unnamed: U24.4, U31.10 (O5)
unnamed: U24.9, U31.9 (O6)
unnamed: U24.12, U31.7 (O7)

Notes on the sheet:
Should these be swapped?

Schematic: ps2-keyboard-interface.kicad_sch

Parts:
C36, C37, C39: 100nf; C_0805_2012Metric
D3: 1N457; D_0805_2012Metric
J10: PS2; Connector_Mini-DIN_Female_6Pin_2rows
R29: 33k; R_0805_2012Metric
U23: 74HCT14; SOIC-14_3.9x8.7mm_P1.27mm
U29, U30: 74HCT595; SOIC-16_3.9x9.9mm_P1.27mm

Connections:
/IO/PS2 keyboard interface/DIO0: U29.1 (QB); also elsewhere on the board
/IO/PS2 keyboard interface/DIO1: U29.2 (QC); also elsewhere on the board
/IO/PS2 keyboard interface/DIO2: U29.3 (QD); also elsewhere on the board
/IO/PS2 keyboard interface/DIO3: U29.4 (QE); also elsewhere on the board
/IO/PS2 keyboard interface/DIO4: U29.5 (QF); also elsewhere on the board
/IO/PS2 keyboard interface/DIO5: U29.6 (QG); also elsewhere on the board
/IO/PS2 keyboard interface/DIO6: U29.7 (QH); also elsewhere on the board
/IO/PS2 keyboard interface/KeyPresent: U23.6, U29.12 (RCLK), U30.12 (RCLK); also elsewhere on the board
/IO/PS2 keyboard interface/KeyboardBit7: U30.15 (QA)
/IO/PS2 keyboard interface/KeyboardData: J10.1, U29.14 (SER)
/IO/PS2 keyboard interface/~KeyboardClk: U23.4, U29.11 (SRCLK), U30.11 (SRCLK)
/IO/PS2 keyboard interface/~PS2ShiftOE: U29.13 (~OE), U30.13 (~OE); also elsewhere on the board
unnamed: D3.2 (A), R29.2, U23.2
unnamed: C39.1, D3.1 (K), R29.1, U23.5
unnamed: J10.5, U23.1, U23.3
unnamed: U29.9 (QH'), U30.14 (SER)

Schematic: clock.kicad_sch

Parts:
BT1: CR2032; Battery_Panasonic_CR2032-HFN_Horizontal_CircularHoles
C46, C47: 6pf; C_0805_2012Metric
U100: DS1306; TSSOP-20_4.4x5mm_P0.4mm
Y3: 32.768kHz; Crystal_C26-LF_D2.1mm_L6.5mm_Vertical

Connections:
/IO/Clock/CS: U100.12 (CE); also elsewhere on the board
/IO/SPI_CLK: U100.14 (SCLK); also elsewhere on the board
/IO/SPI_MISO: U100.16 (SDO); also elsewhere on the board
/IO/SPI_MOSI: U100.15 (SDI); also elsewhere on the board
unnamed: BT1.1 (+), U100.2 (VBAT)
unnamed: C46.2, U100.3 (X1), Y3.2
unnamed: C47.2, U100.5 (X2), Y3.1

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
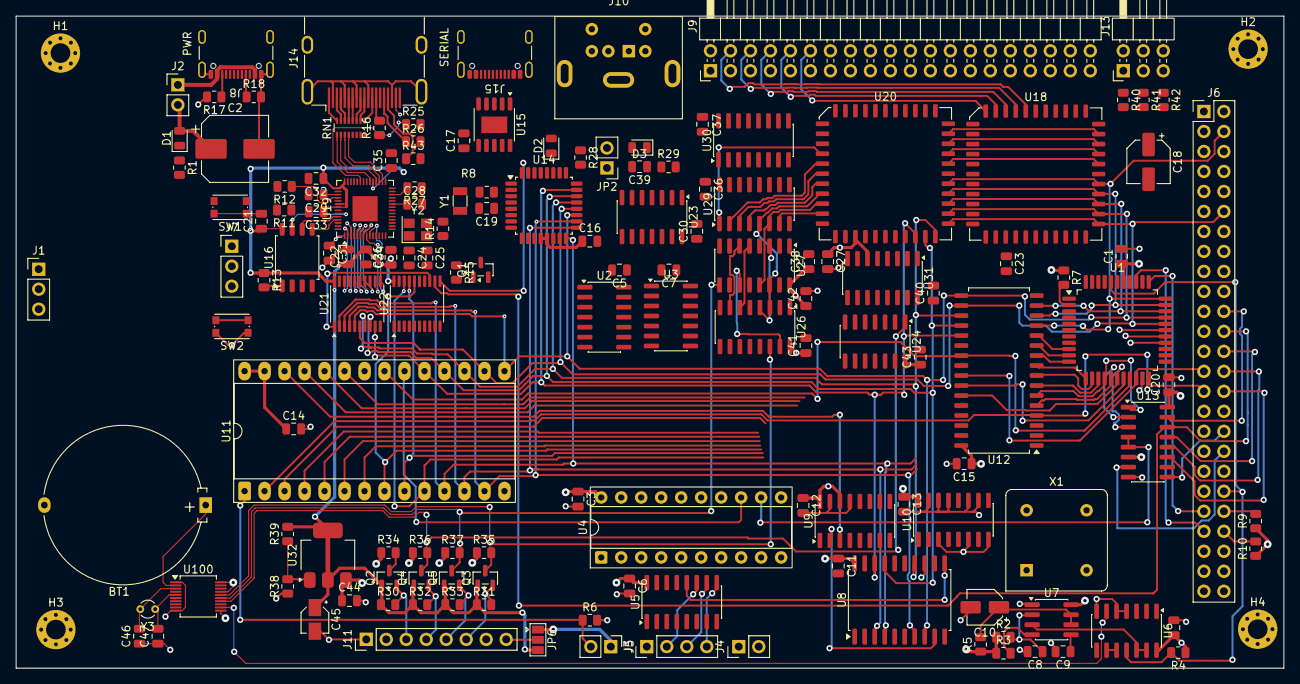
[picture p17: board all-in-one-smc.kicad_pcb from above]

Board: 4 copper layers, 161.1 x 82.9 mm, 150 parts (0 on the bottom side), 210 nets.

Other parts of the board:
JP2: Enable PS2 Output; PinHeader_1x02_P2.54mm_Vertical
R28: 10k; R_0805_2012Metric

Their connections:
/IO/PS2 keyboard interface/~PS2ShiftOE: JP2.1 (A), R28.2; also elsewhere on the board

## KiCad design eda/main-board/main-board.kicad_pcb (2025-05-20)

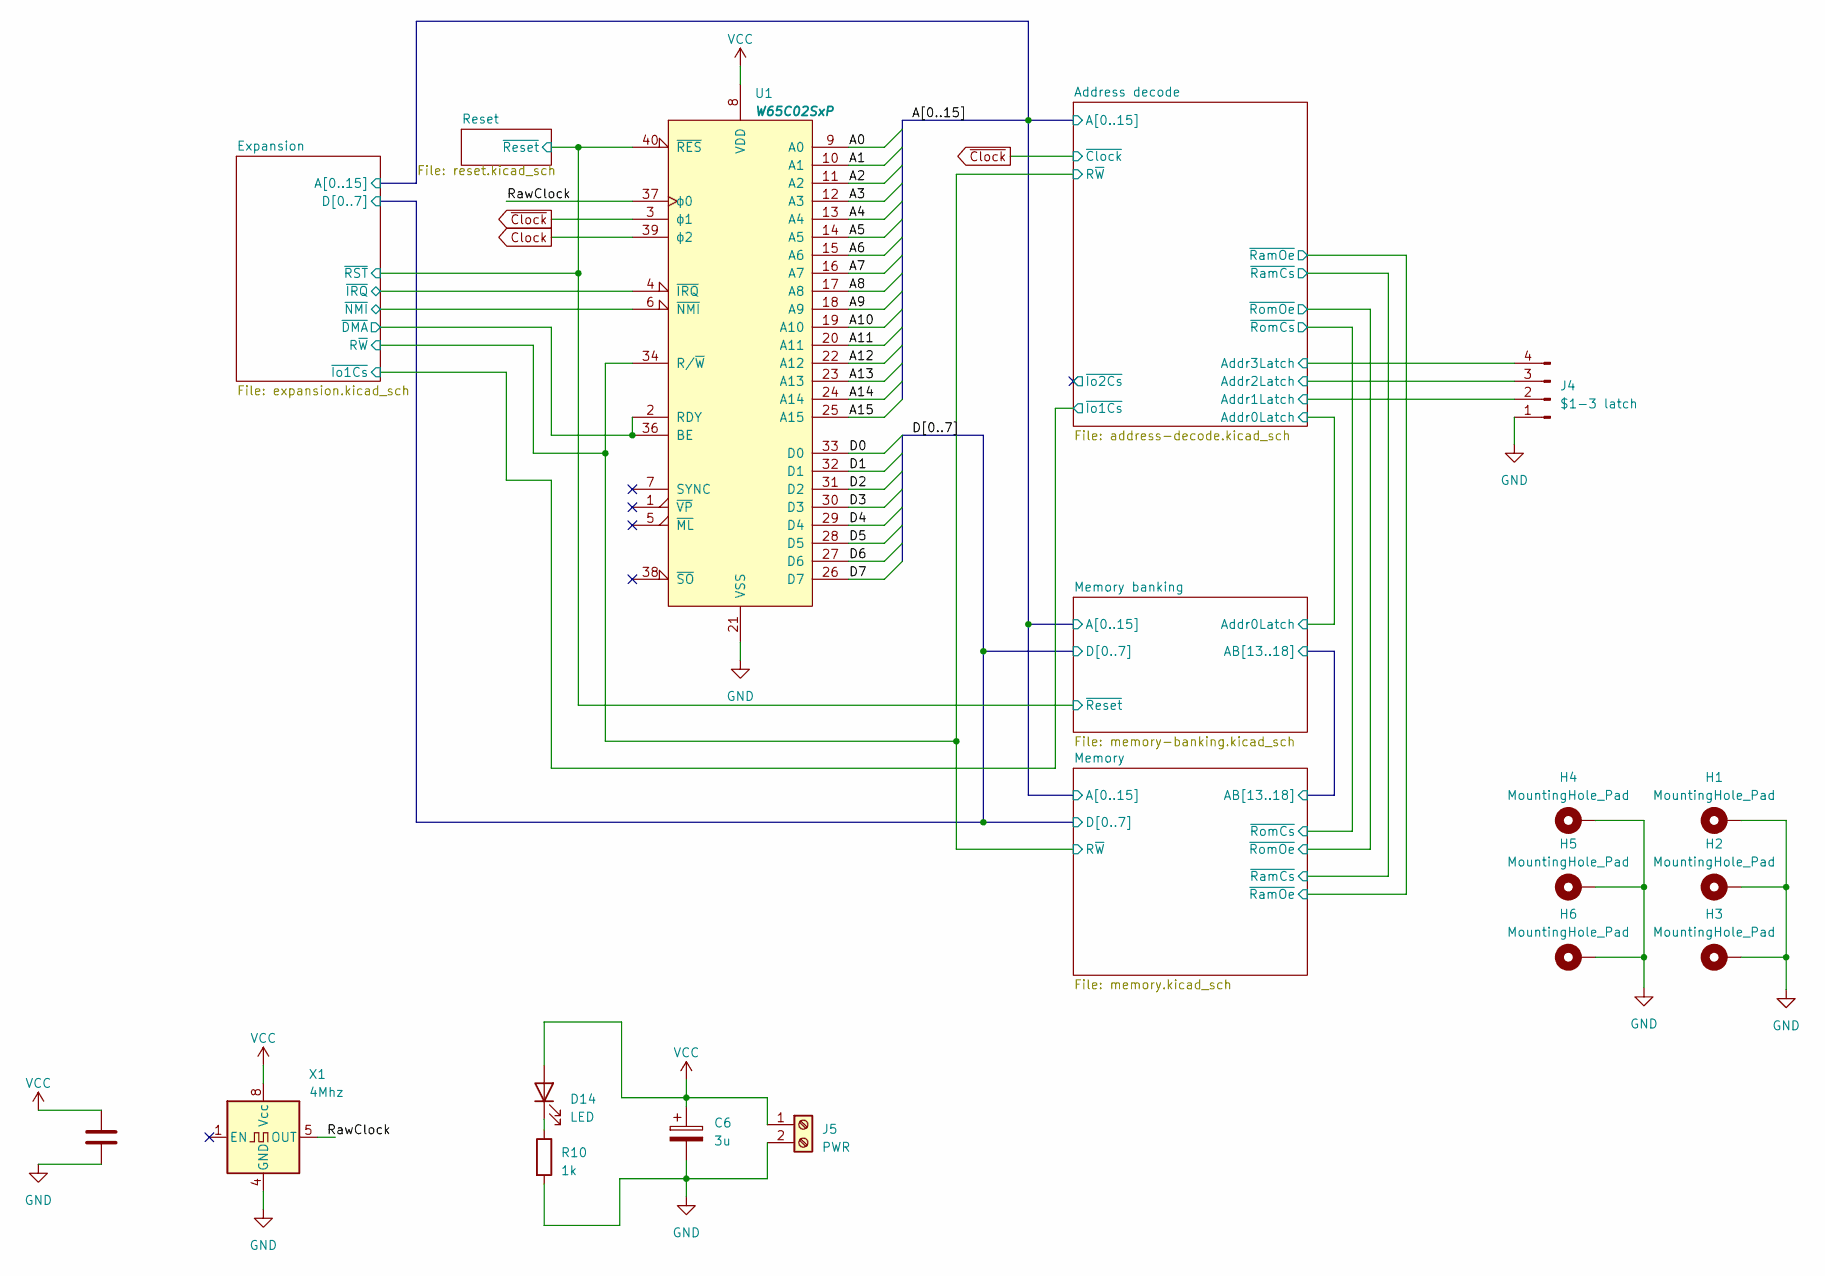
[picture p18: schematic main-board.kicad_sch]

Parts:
C4: 100n; C_Disc_D3.8mm_W2.6mm_P2.50mm
C6: 3u; CP_Radial_D8.0mm_P3.50mm
D14: LED; LED_D3.0mm
H1, H2, H3, H4, H5, H6: MountingHole_Pad; MountingHole_2.5mm_Pad_Via
J4: $1-3 latch; PinHeader_1x04_P2.54mm_Vertical
J5: PWR; TerminalBlock_Altech_AK300-2_P5.00mm
R10: 1k; R_Axial_DIN0207_L6.3mm_D2.5mm_P7.62mm_Horizontal
U1: W65C02SxP; DIP-40_W15.24mm
X1: 4Mhz; Oscillator_DIP-8

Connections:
/A0: U1.9 (A0); also elsewhere on the board
/A1: U1.10 (A1); also elsewhere on the board
/A2: U1.11 (A2); also elsewhere on the board
/A3: U1.12 (A3); also elsewhere on the board
/A4: U1.13 (A4); also elsewhere on the board
/A5: U1.14 (A5); also elsewhere on the board
/A6: U1.15 (A6); also elsewhere on the board
/A7: U1.16 (A7); also elsewhere on the board
/A8: U1.17 (A8); also elsewhere on the board
/A9: U1.18 (A9); also elsewhere on the board
/A10: U1.19 (A10); also elsewhere on the board
/A11: U1.20 (A11); also elsewhere on the board
/A12: U1.22 (A12); also elsewhere on the board
/A13: U1.23 (A13); also elsewhere on the board
/A14: U1.24 (A14); also elsewhere on the board
/A15: U1.25 (A15); also elsewhere on the board
/Address decode/Addr1Latch: J4.2; also elsewhere on the board
/Address decode/Addr2Latch: J4.3; also elsewhere on the board
/Address decode/Addr3Latch: J4.4; also elsewhere on the board
/Address decode/R~W: U1.34 (R/~W); also elsewhere on the board
/D0: U1.33 (D0); also elsewhere on the board
/D1: U1.32 (D1); also elsewhere on the board
/D2: U1.31 (D2); also elsewhere on the board
/D3: U1.30 (D3); also elsewhere on the board
/D4: U1.29 (D4); also elsewhere on the board
/D5: U1.28 (D5); also elsewhere on the board
/D6: U1.27 (D6); also elsewhere on the board
/D7: U1.26 (D7); also elsewhere on the board
/Expansion/~DMA: U1.2 (RDY), U1.36 (BE); also elsewhere on the board
/Expansion/~IRQ: U1.4 (~IRQ); also elsewhere on the board
/Expansion/~NMI: U1.6 (~NMI); also elsewhere on the board
/Expansion/~RST: U1.40 (~RES); also elsewhere on the board
/RawClock: U1.37 (ϕ0), X1.5 (OUT)
Clock: U1.39 (ϕ2); also elsewhere on the board
GND: C4.2, C6.2, H1.1, H2.1, H3.1, H4.1, H5.1, H6.1, J4.1, J5.2, R10.2, U1.21 (VSS), X1.4 (GND); also elsewhere on the board
unnamed: D14.1 (K), R10.1
VCC: C4.1, C6.1, D14.2 (A), J5.1, U1.8 (VDD), X1.8 (Vcc); also elsewhere on the board
~Clock: U1.3 (ϕ1); also elsewhere on the board

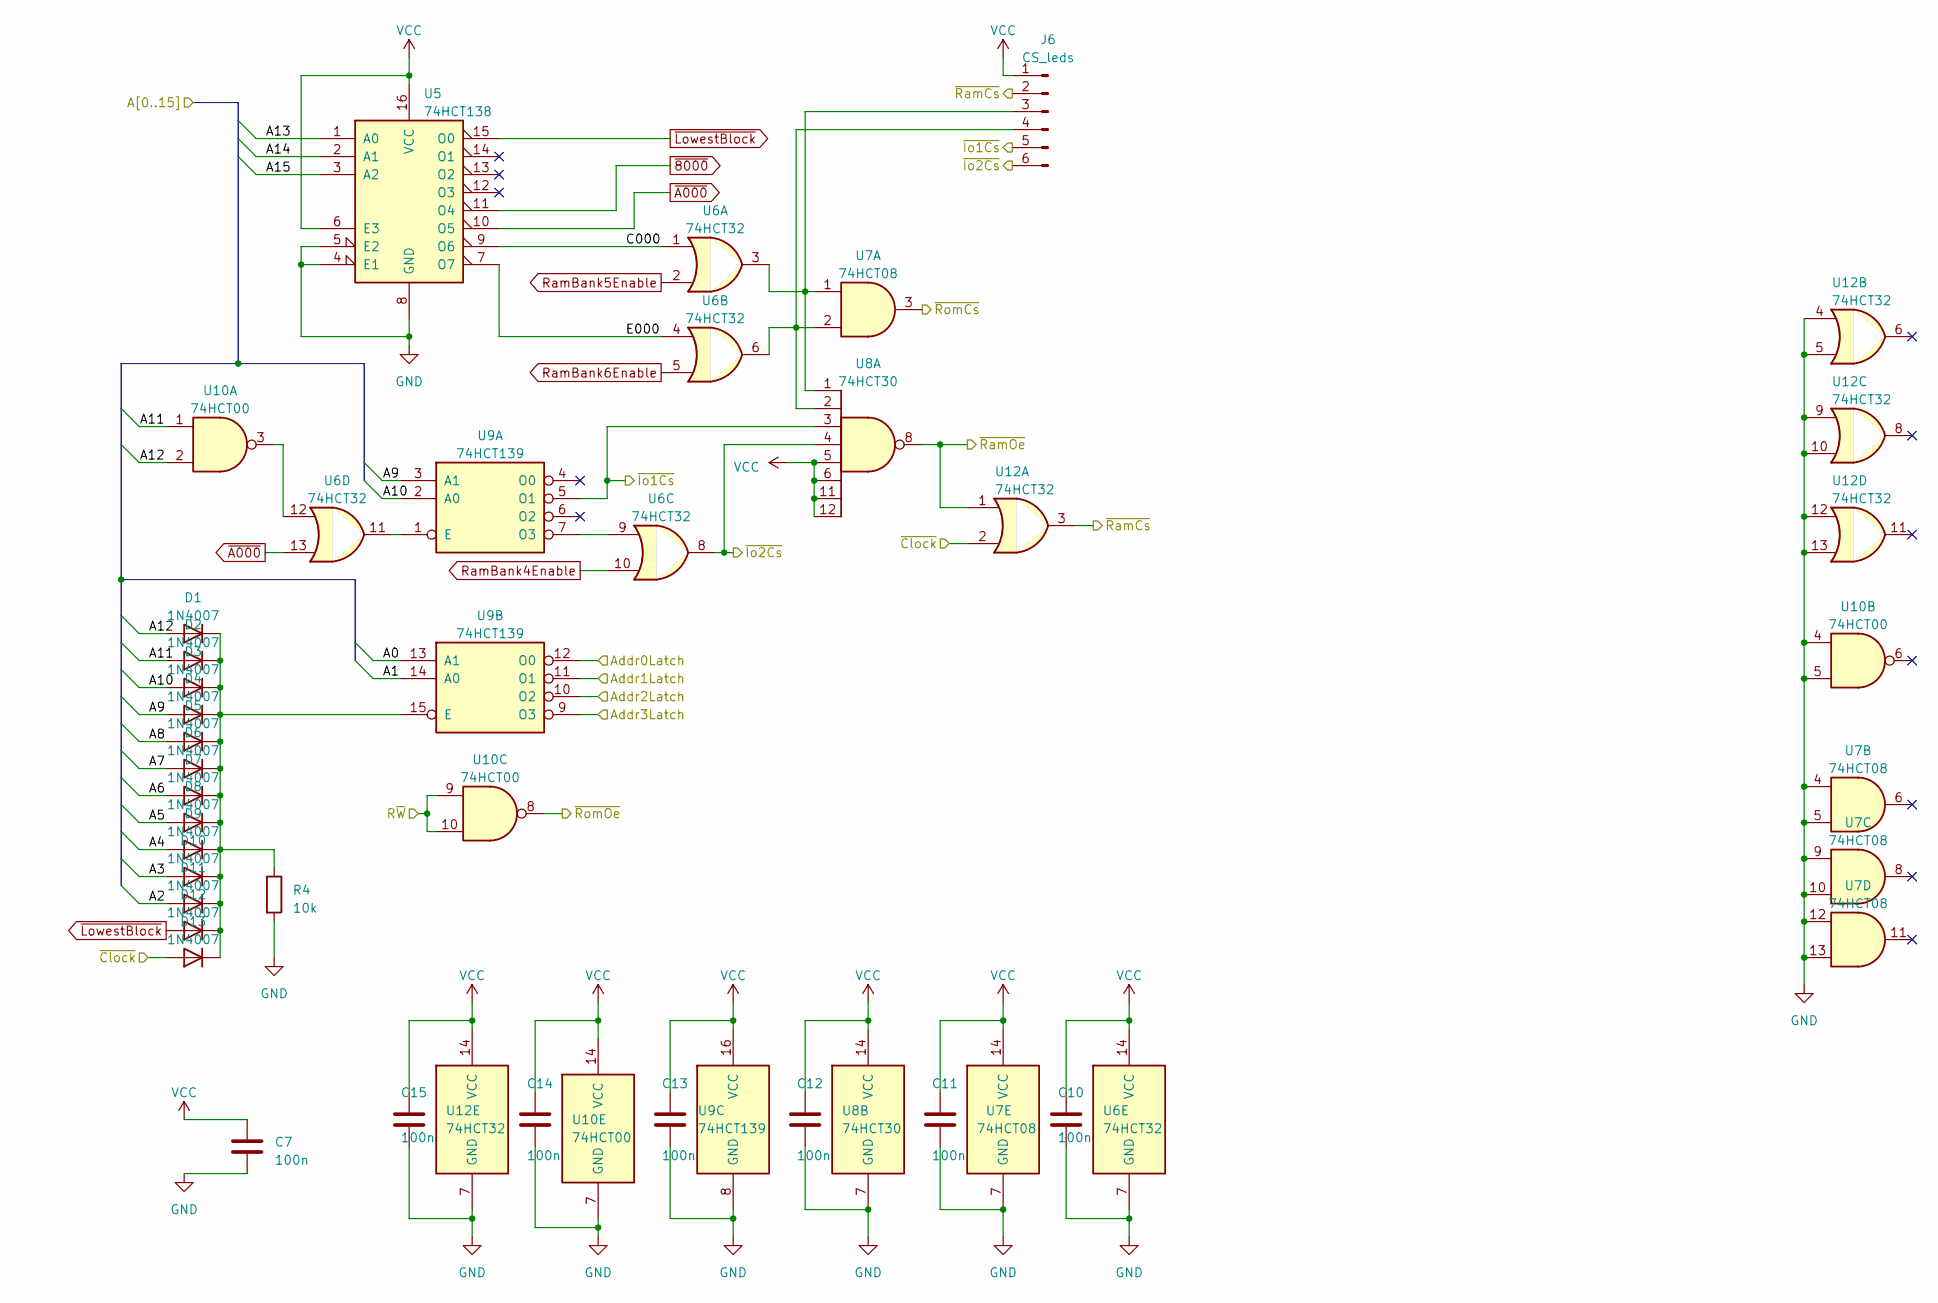
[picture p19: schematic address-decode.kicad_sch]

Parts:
C7, C10, C11, C12, C13, C14, C15: 100n; C_Disc_D3.8mm_W2.6mm_P2.50mm
D1, D2, D3, D4, D5, D6, D7, D8, D9, D10, D11, D12, D13: 1N4007; D_DO-41_SOD81_P7.62mm_Horizontal
J6: CS_leds; PinHeader_1x06_P2.54mm_Vertical
R4: 10k; R_Axial_DIN0207_L6.3mm_D2.5mm_P7.62mm_Horizontal
U5: 74HCT138; DIP-16_W7.62mm
U6, U12: 74HCT32; DIP-14_W7.62mm
U7: 74HCT08; DIP-14_W7.62mm
U8: 74HCT30; DIP-14_W7.62mm
U9: 74HCT139; DIP-16_W7.62mm
U10: 74HCT00; DIP-14_W7.62mm

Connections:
/A0: U9.13 (A1); also elsewhere on the board
/A1: U9.14 (A0); also elsewhere on the board
/A2: D11.2 (A); also elsewhere on the board
/A3: D10.2 (A); also elsewhere on the board
/A4: D9.2 (A); also elsewhere on the board
/A5: D8.2 (A); also elsewhere on the board
/A6: D7.2 (A); also elsewhere on the board
/A7: D6.2 (A); also elsewhere on the board
/A8: D5.2 (A); also elsewhere on the board
/A9: D4.2 (A), U9.3 (A1); also elsewhere on the board
/A10: D3.2 (A), U9.2 (A0); also elsewhere on the board
/A11: D2.2 (A), U10.1; also elsewhere on the board
/A12: D1.2 (A), U10.2; also elsewhere on the board
/A13: U5.1 (A0); also elsewhere on the board
/A14: U5.2 (A1); also elsewhere on the board
/A15: U5.3 (A2); also elsewhere on the board
/Address decode/Addr0Latch: U9.12 (O0); also elsewhere on the board
/Address decode/Addr1Latch: U9.11 (O1); also elsewhere on the board
/Address decode/Addr2Latch: U9.10 (O2); also elsewhere on the board
/Address decode/Addr3Latch: U9.9 (O3); also elsewhere on the board
/Address decode/C000: U5.9 (O6), U6.1
/Address decode/E000: U5.7 (O7), U6.4
/Address decode/R~W: U10.9, U10.10; also elsewhere on the board
/Address decode/~Io1Cs: J6.5, U8.3, U9.5 (O1); also elsewhere on the board
/Address decode/~Io2Cs: J6.6, U6.8, U8.4
/Address decode/~RamCs: J6.2, U12.3; also elsewhere on the board
/Address decode/~RamOe: U8.8, U12.1; also elsewhere on the board
/Address decode/~RomCs: U7.3; also elsewhere on the board
/Address decode/~RomOe: U10.8; also elsewhere on the board
GND: C7.2, C10.2, C11.2, C12.2, C13.2, C14.2, C15.2, R4.2, U5.4 (E1), U5.5 (E2), U5.8 (GND), U6.7 (GND), U7.4, U7.5, U7.7 (GND), U7.9, U7.10, U7.12, U7.13, U8.7 (GND), U9.8 (GND), U10.4, U10.5, U10.7 (GND), U12.4, U12.5, U12.7 (GND), U12.9, U12.10, U12.12, U12.13; also elsewhere on the board
unnamed: D1.1 (K), D2.1 (K), D3.1 (K), D4.1 (K), D5.1 (K), D6.1 (K), D7.1 (K), D8.1 (K), D9.1 (K), D10.1 (K), D11.1 (K), D12.1 (K), D13.1 (K), R4.1, U9.15 (E)
unnamed: J6.3, U6.3, U7.1, U8.1
unnamed: J6.4, U6.6, U7.2, U8.2
unnamed: U6.11, U9.1 (E)
unnamed: U6.9, U9.7 (O3)
unnamed: U6.12, U10.3
RamBank4Enable: U6.10; also elsewhere on the board
RamBank5Enable: U6.2; also elsewhere on the board
RamBank6Enable: U6.5; also elsewhere on the board
VCC: C7.1, C10.1, C11.1, C12.1, C13.1, C14.1, C15.1, J6.1, U5.6 (E3), U5.16 (VCC), U6.14 (VCC), U7.14 (VCC), U8.5, U8.6, U8.11, U8.12, U8.14 (VCC), U9.16 (VCC), U10.14 (VCC), U12.14 (VCC); also elsewhere on the board
~8000: U5.11 (O4); also elsewhere on the board
~A000: U5.10 (O5), U6.13
~Clock: D13.2 (A), U12.2; also elsewhere on the board
~LowestBlock: D12.2 (A), U5.15 (O0)

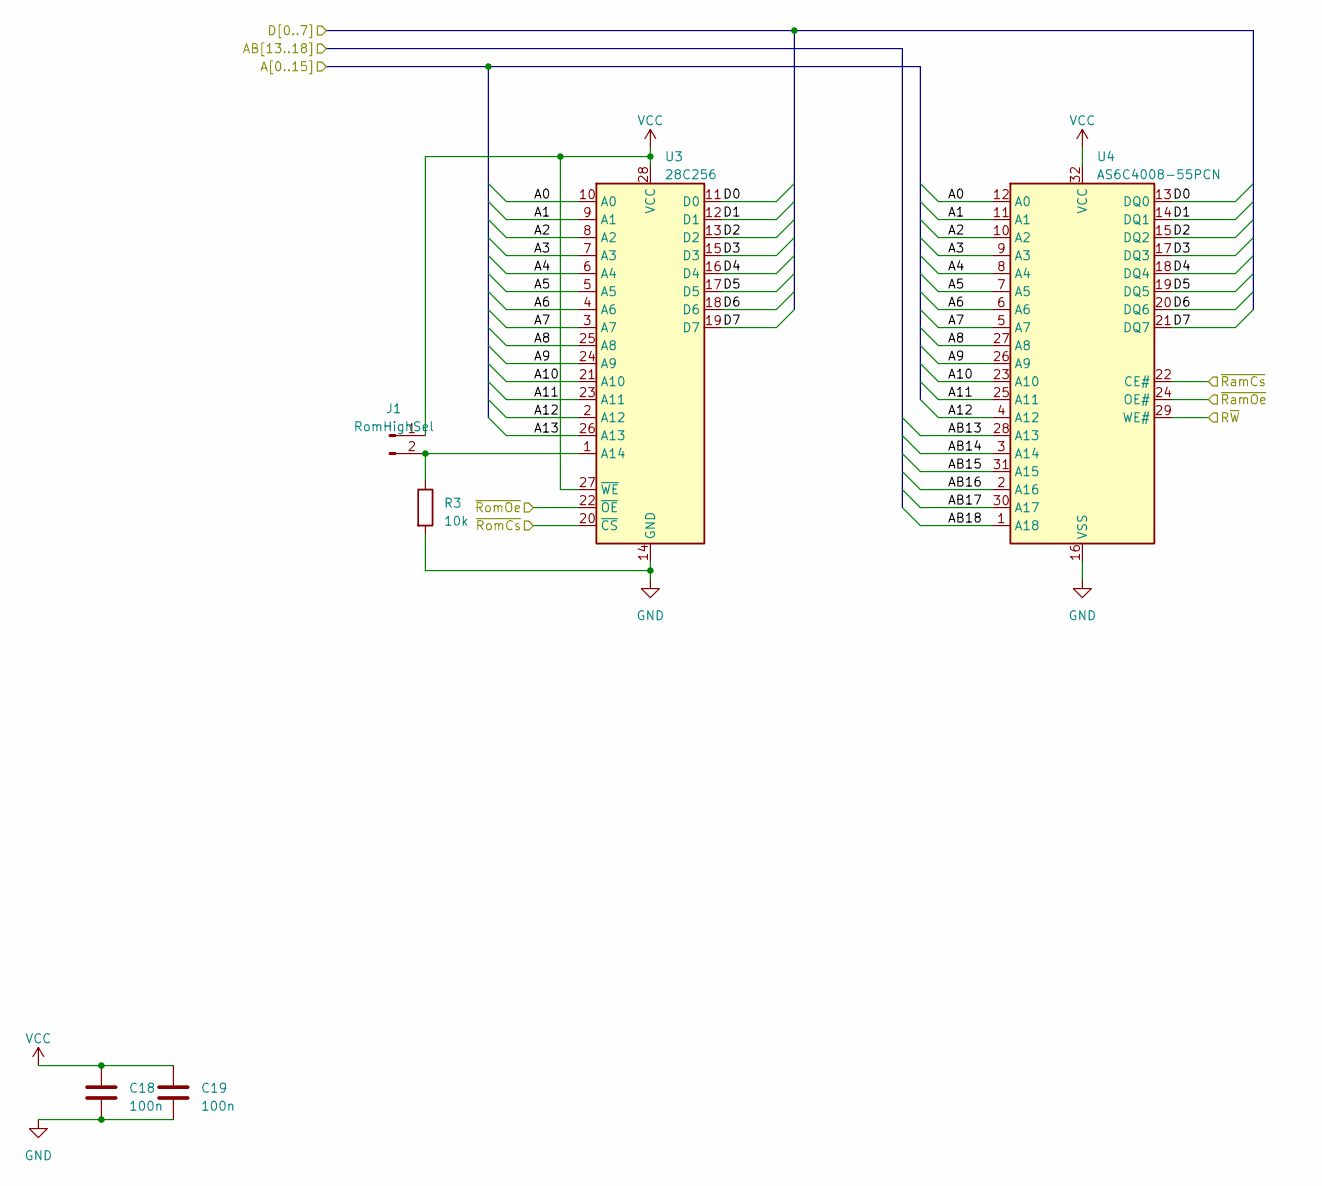
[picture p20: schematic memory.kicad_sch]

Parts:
C18, C19: 100n; C_Disc_D3.8mm_W2.6mm_P2.50mm
J1: RomHighSel; PinHeader_1x02_P2.54mm_Vertical
R3: 10k; R_Axial_DIN0207_L6.3mm_D2.5mm_P7.62mm_Horizontal
U3: 28C256; DIP_Socket-28_W11.9_W12.7_W15.24_W17.78_W18.5_3M_228-1277-0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
U4: AS6C4008-55PCN; DIP-32_W15.24mm

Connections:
/A0: U3.10 (A0), U4.12 (A0); also elsewhere on the board
/A1: U3.9 (A1), U4.11 (A1); also elsewhere on the board
/A2: U3.8 (A2), U4.10 (A2); also elsewhere on the board
/A3: U3.7 (A3), U4.9 (A3); also elsewhere on the board
/A4: U3.6 (A4), U4.8 (A4); also elsewhere on the board
/A5: U3.5 (A5), U4.7 (A5); also elsewhere on the board
/A6: U3.4 (A6), U4.6 (A6); also elsewhere on the board
/A7: U3.3 (A7), U4.5 (A7); also elsewhere on the board
/A8: U3.25 (A8), U4.27 (A8); also elsewhere on the board
/A9: U3.24 (A9), U4.26 (A9); also elsewhere on the board
/A10: U3.21 (A10), U4.23 (A10); also elsewhere on the board
/A11: U3.23 (A11), U4.25 (A11); also elsewhere on the board
/A12: U3.2 (A12), U4.4 (A12); also elsewhere on the board
/A13: U3.26 (A13); also elsewhere on the board
/Address decode/R~W: U4.29 (WE#); also elsewhere on the board
/Address decode/~RamCs: U4.22 (CE#); also elsewhere on the board
/Address decode/~RamOe: U4.24 (OE#); also elsewhere on the board
/Address decode/~RomCs: U3.20 (~CS); also elsewhere on the board
/Address decode/~RomOe: U3.22 (~OE); also elsewhere on the board
/D0: U3.11 (D0), U4.13 (DQ0); also elsewhere on the board
/D1: U3.12 (D1), U4.14 (DQ1); also elsewhere on the board
/D2: U3.13 (D2), U4.15 (DQ2); also elsewhere on the board
/D3: U3.15 (D3), U4.17 (DQ3); also elsewhere on the board
/D4: U3.16 (D4), U4.18 (DQ4); also elsewhere on the board
/D5: U3.17 (D5), U4.19 (DQ5); also elsewhere on the board
/D6: U3.18 (D6), U4.20 (DQ6); also elsewhere on the board
/D7: U3.19 (D7), U4.21 (DQ7); also elsewhere on the board
/Memory banking/AB13: U4.28 (A13); also elsewhere on the board
/Memory banking/AB14: U4.3 (A14); also elsewhere on the board
/Memory banking/AB15: U4.31 (A15); also elsewhere on the board
/Memory banking/AB16: U4.2 (A16); also elsewhere on the board
/Memory banking/AB17: U4.30 (A17); also elsewhere on the board
/Memory banking/AB18: U4.1 (A18); also elsewhere on the board
GND: C18.2, C19.2, R3.2, U3.14 (GND), U4.16 (VSS); also elsewhere on the board
unnamed: J1.2, R3.1, U3.1 (A14)
VCC: C18.1, C19.1, J1.1, U3.27 (~WE), U3.28 (VCC), U4.32 (VCC); also elsewhere on the board


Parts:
C1: 10n; C_Disc_D6.0mm_W2.5mm_P5.00mm
C2: 10u; CP_Radial_D4.0mm_P1.50mm
C3: 100n; C_Disc_D3.8mm_W2.6mm_P2.50mm
J3: ResetSwitch; PinHeader_1x02_P2.54mm_Vertical
R1: 47k; R_Axial_DIN0207_L6.3mm_D2.5mm_P7.62mm_Horizontal
R2: 1M; R_Axial_DIN0207_L6.3mm_D2.5mm_P7.62mm_Horizontal
R5: 1k; R_Axial_DIN0207_L6.3mm_D2.5mm_P7.62mm_Horizontal
R7: 10k; R_Axial_DIN0207_L6.3mm_D2.5mm_P7.62mm_Horizontal
U2: NA555P; DIP-8_W7.62mm
U10: 74HCT00; DIP-14_W7.62mm

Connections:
/Expansion/~RST: R5.2, U10.11; also elsewhere on the board
GND: C1.2, C2.2, C3.2, J3.2, U2.1 (GND); also elsewhere on the board
unnamed: J3.1, R7.2, U2.4 (R)
unnamed: C1.1, U2.5 (CV)
unnamed: C2.1, R1.2, U2.6 (THR), U2.7 (DIS)
unnamed: C3.1, R2.2, U2.2 (TR)
Reset: U2.3 (Q), U10.12, U10.13
VCC: R1.1, R2.1, R5.1, R7.1, U2.8 (VCC); also elsewhere on the board

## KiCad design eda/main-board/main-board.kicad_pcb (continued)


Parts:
C9, C16, C17: 100n; C_Disc_D3.8mm_W2.6mm_P2.50mm
J2: Membank block; PinHeader_1x06_P2.54mm_Vertical
U14, U15: 74LHCT157; DIP-16_W7.62mm
U16: 74HCT273; DIP-20_W7.62mm

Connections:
/A13: U14.3 (I1a); also elsewhere on the board
/A14: U14.6 (I1b); also elsewhere on the board
/A15: U14.10 (I1c); also elsewhere on the board
/Address decode/Addr0Latch: U16.11 (Cp); also elsewhere on the board
/D0: U16.4 (D1); also elsewhere on the board
/D1: U16.3 (D0); also elsewhere on the board
/D2: U16.7 (D2); also elsewhere on the board
/D3: U16.8 (D3); also elsewhere on the board
/D4: U16.13 (D4); also elsewhere on the board
/D5: U16.14 (D5); also elsewhere on the board
/D6: U16.17 (D6); also elsewhere on the board
/D7: U16.18 (D7); also elsewhere on the board
/Expansion/~RST: U16.1 (~Mr); also elsewhere on the board
/Memory banking/AB13: U14.4 (Za); also elsewhere on the board
/Memory banking/AB14: U14.7 (Zb); also elsewhere on the board
/Memory banking/AB15: U14.9 (Zc); also elsewhere on the board
/Memory banking/AB16: U14.12 (Zd); also elsewhere on the board
/Memory banking/AB17: U15.4 (Za); also elsewhere on the board
/Memory banking/AB18: U15.7 (Zb); also elsewhere on the board
/Memory banking/LA13: J2.2, U14.2 (I0a), U16.9 (Q3)
/Memory banking/LA14: J2.3, U14.5 (I0b), U16.12 (Q4)
/Memory banking/LA15: J2.4, U14.11 (I0c), U16.15 (Q5)
/Memory banking/LA17: J2.5, U15.2 (I0a), U16.16 (Q6)
/Memory banking/LA18: J2.6, U15.5 (I0b), U16.19 (Q7)
GND: C9.2, C16.2, C17.2, J2.1, U14.8 (GND), U14.13 (I1d), U14.15 (E), U15.3 (I1a), U15.6 (I1b), U15.8 (GND), U15.10 (I1c), U15.11 (I0c), U15.13 (I1d), U15.14 (I0d), U15.15 (E), U16.10 (GND); also elsewhere on the board
RamBank4Enable: U16.2 (Q0); also elsewhere on the board
RamBank5Enable: U16.5 (Q1); also elsewhere on the board
RamBank6Enable: U16.6 (Q2); also elsewhere on the board
VCC: C9.1, C16.1, C17.1, U14.14 (I0d), U14.16 (VCC), U15.16 (VCC), U16.20 (VCC); also elsewhere on the board
~8000: U14.1 (S), U15.1 (S); also elsewhere on the board


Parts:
C5: 1u; CP_Radial_D8.0mm_P3.50mm
C8, C20, C21, C22, C23: 100n; C_Disc_D3.8mm_W2.6mm_P2.50mm
J7: Expansion; PinHeader_2x25_P2.54mm_Vertical
R6, R8, R9: 10k; R_Axial_DIN0207_L6.3mm_D2.5mm_P7.62mm_Horizontal
U11: 74HCT245; DIP-20_W7.62mm
U13: 74HCT138; DIP-16_W7.62mm
U17, U18, U20: 74HCT541; DIP-20_W7.62mm

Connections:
/A0: U17.2 (A0); also elsewhere on the board
/A1: U17.3 (A1); also elsewhere on the board
/A2: U17.4 (A2); also elsewhere on the board
/A3: U17.5 (A3); also elsewhere on the board
/A4: U17.6 (A4); also elsewhere on the board
/A5: U17.7 (A5); also elsewhere on the board
/A6: U13.1 (A0), U17.8 (A6); also elsewhere on the board
/A7: U13.2 (A1), U17.9 (A7); also elsewhere on the board
/A8: U13.3 (A2), U18.2 (A0); also elsewhere on the board
/A9: U18.3 (A1); also elsewhere on the board
/A10: U18.4 (A2); also elsewhere on the board
/A11: U18.5 (A3); also elsewhere on the board
/A12: U18.6 (A4); also elsewhere on the board
/A13: U18.7 (A5); also elsewhere on the board
/A14: U18.8 (A6); also elsewhere on the board
/A15: U18.9 (A7); also elsewhere on the board
/Address decode/R~W: U11.1 (A->B), U20.3 (A1); also elsewhere on the board
/Address decode/~Io1Cs: U11.19 (CE), U13.4 (E1), U13.5 (E2); also elsewhere on the board
/D0: U11.18 (B0); also elsewhere on the board
/D1: U11.17 (B1); also elsewhere on the board
/D2: U11.16 (B2); also elsewhere on the board
/D3: U11.15 (B3); also elsewhere on the board
/D4: U11.14 (B4); also elsewhere on the board
/D5: U11.13 (B5); also elsewhere on the board
/D6: U11.12 (B6); also elsewhere on the board
/D7: U11.11 (B7); also elsewhere on the board
/Expansion/IoSelect0: J7.22, U13.15 (O0)
/Expansion/IoSelect1: J7.24, U13.14 (O1)
/Expansion/IoSelect2: J7.26, U13.13 (O2)
/Expansion/IoSelect3: J7.28, U13.12 (O3)
/Expansion/IoSelect4: J7.30, U13.11 (O4)
/Expansion/IoSelect5: J7.32, U13.10 (O5)
/Expansion/IoSelect6: J7.34, U13.9 (O6)
/Expansion/IoSelect7: J7.36, U13.7 (O7)
/Expansion/e/~IRQ: J7.44, R8.2, U20.6 (A4)
/Expansion/e/~NMI: J7.42, R6.2, U20.5 (A3)
/Expansion/~DMA: U20.18 (Y0); also elsewhere on the board
/Expansion/~ExtRomCS: J7.48
/Expansion/~IRQ: U20.14 (Y4); also elsewhere on the board
/Expansion/~NMI: U20.15 (Y3); also elsewhere on the board
/Expansion/~RST: J7.40; also elsewhere on the board
Clock: U20.4 (A2); also elsewhere on the board
GND: C5.2, C8.2, C20.2, C21.2, C22.2, C23.2, J7.2, J7.3, J7.20, J7.37, J7.38, J7.45, J7.46, U11.10 (GND), U13.8 (GND), U17.1 (G1), U17.10 (GND), U17.19 (G2), U18.1 (G1), U18.10 (GND), U18.19 (G2), U20.1 (G1), U20.7 (A5), U20.8 (A6), U20.9 (A7), U20.10 (GND), U20.19 (G2); also elsewhere on the board
unnamed: J7.4, U11.2 (A0)
unnamed: J7.5, U17.18 (Y0)
unnamed: J7.6, U11.3 (A1)
unnamed: J7.7, U17.17 (Y1)
unnamed: J7.8, U11.4 (A2)
unnamed: J7.9, U17.16 (Y2)
unnamed: J7.10, U11.5 (A3)
unnamed: J7.11, U17.15 (Y3)
unnamed: J7.12, U11.6 (A4)
unnamed: J7.13, U17.14 (Y4)
unnamed: J7.14, U11.7 (A5)
unnamed: J7.15, U17.13 (Y5)
unnamed: J7.16, U11.8 (A6)
unnamed: J7.17, U17.12 (Y6)
unnamed: J7.18, U11.9 (A7)
unnamed: J7.19, U17.11 (Y7)
unnamed: J7.21, U18.18 (Y0)
unnamed: J7.23, U18.17 (Y1)
unnamed: J7.25, U18.16 (Y2)
unnamed: J7.27, U18.15 (Y3)
unnamed: J7.29, U18.14 (Y4)
unnamed: J7.31, U18.13 (Y5)
unnamed: J7.33, U18.12 (Y6)
unnamed: J7.35, U18.11 (Y7)
unnamed: J7.39, U20.16 (Y2)
unnamed: J7.41, U20.17 (Y1)
unnamed: J7.43, R9.2, U20.2 (A0)
VCC: C5.1, C8.1, C20.1, C21.1, C22.1, C23.1, J7.1, J7.50, R6.1, R8.1, R9.1, U11.20 (VCC), U13.6 (E3), U13.16 (VCC), U17.20 (VCC), U18.20 (VCC), U20.20 (VCC); also elsewhere on the board


Board: 4 copper layers, 230.0 x 100.0 mm, 80 parts (0 on the bottom side), 113 nets.

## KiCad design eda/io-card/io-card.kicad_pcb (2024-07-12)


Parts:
C2, C11, C12, C13, C16: 100nf; C_Disc_D3.8mm_W2.6mm_P2.50mm
H1, H2, H3, H4, H5, H6: MountingHole_Pad; MountingHole_2.5mm_Pad_Via
J3: PortA; PinHeader_1x09_P2.54mm_Horizontal
J4: PortB; PinHeader_1x09_P2.54mm_Horizontal
J5: ControlLines; PinHeader_1x06_P2.54mm_Horizontal
J6: SPI; PinHeader_2x06_P2.54mm_Horizontal
JP11: Key present select; PinHeader_1x03_P2.54mm_Vertical
JP12: IRQ Select; PinHeader_1x03_P2.54mm_Vertical
U1, U2: W65C22SxP; DIP-40_W15.24mm
U3: 74HCT14; DIP-14_W7.62mm
U5: 74HCT00; DIP-14_W7.62mm
U13: 74HCT138; DIP-16_W7.62mm

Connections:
/Card_Detect: U2.5 (PA3)
/Clock: U1.25 (ϕ2), U2.25 (ϕ2); also elsewhere on the board
/Expansion header/A0: U1.38 (RS0), U2.38 (RS0); also elsewhere on the board
/Expansion header/A1: U1.37 (RS1), U2.37 (RS1); also elsewhere on the board
/Expansion header/A2: U1.36 (RS2), U2.36 (RS2); also elsewhere on the board
/Expansion header/A3: U1.35 (RS3), U2.35 (RS3); also elsewhere on the board
/Expansion header/A4: U2.24 (CS1), U3.9; also elsewhere on the board
/Expansion header/D0: U1.33 (D0), U2.33 (D0); also elsewhere on the board
/Expansion header/D1: U1.32 (D1), U2.32 (D1); also elsewhere on the board
/Expansion header/D2: U1.31 (D2), U2.31 (D2); also elsewhere on the board
/Expansion header/D3: U1.30 (D3), U2.30 (D3); also elsewhere on the board
/Expansion header/D4: U1.29 (D4), U2.29 (D4); also elsewhere on the board
/Expansion header/D5: U1.28 (D5), U2.28 (D5); also elsewhere on the board
/Expansion header/D6: U1.27 (D6), U2.27 (D6); also elsewhere on the board
/Expansion header/D7: U1.26 (D7), U2.26 (D7); also elsewhere on the board
/PS2 keyboard interface/KeyPresent: JP11.1 (A); also elsewhere on the board
/PS2 keyboard interface/KeyboardBit0: U2.10 (PB0); also elsewhere on the board
/PS2 keyboard interface/KeyboardBit1: U2.11 (PB1); also elsewhere on the board
/PS2 keyboard interface/KeyboardBit2: U2.12 (PB2); also elsewhere on the board
/PS2 keyboard interface/KeyboardBit3: U2.13 (PB3); also elsewhere on the board
/PS2 keyboard interface/KeyboardBit4: U2.14 (PB4); also elsewhere on the board
/PS2 keyboard interface/KeyboardBit5: U2.15 (PB5); also elsewhere on the board
/PS2 keyboard interface/KeyboardBit6: U2.16 (PB6); also elsewhere on the board
/PS2 keyboard interface/KeyboardBit7: U2.17 (PB7); also elsewhere on the board
/R~W: U1.22 (R/~W), U2.22 (R/~W); also elsewhere on the board
/SD-Card/WriteProtect: U2.6 (PA4); also elsewhere on the board
/SD-Card/~CS: U13.15 (O0); also elsewhere on the board
/SPI_CLK: J6.7, U2.4 (PA2); also elsewhere on the board
/SPI_MISO: J6.5, U2.3 (PA1); also elsewhere on the board
/SPI_MOSI: J6.3, U2.2 (PA0); also elsewhere on the board
/Scanning keyboard interface/KeyPresent: JP11.3 (B); also elsewhere on the board
/~CS: U1.23 (~CS2), U2.23 (~CS2); also elsewhere on the board
/~IRQ: JP12.3 (B), U2.21 (~IRQ); also elsewhere on the board
/~NMI: JP12.1 (A); also elsewhere on the board
/~RST: U1.34 (~RES), U2.34 (~RES); also elsewhere on the board
/~SPI_CS1: J6.9, U13.14 (O1)
/~SPI_CS2: J6.11, U13.13 (O2)
/~SPI_CS3: J6.2, U13.12 (O3)
/~SPI_CS4: J6.4, U13.11 (O4)
/~SPI_CS5: J6.6, U13.10 (O5)
/~SPI_CS6: J6.8, U13.9 (O6)
/~SPI_CS7: J6.10, U13.7 (O7)
GND: C2.2, C11.2, C12.2, C13.2, C16.2, H1.1, H2.1, H3.1, H4.1, H5.1, H6.1, J3.1, J4.1, J5.6, J6.12, U1.1 (VSS), U2.1 (VSS), U3.7 (GND), U5.7 (GND), U13.4 (E1), U13.5 (E2), U13.8 (GND); also elsewhere on the board
unnamed: J3.2, U1.9 (PA7)
unnamed: J3.3, U1.8 (PA6)
unnamed: J3.4, U1.7 (PA5)
unnamed: J3.5, U1.6 (PA4)
unnamed: J3.6, U1.5 (PA3)
unnamed: J3.7, U1.4 (PA2)
unnamed: J3.8, U1.3 (PA1)
unnamed: J3.9, U1.2 (PA0)
unnamed: J4.2, U1.17 (PB7)
unnamed: J4.3, U1.16 (PB6)
unnamed: J4.4, U1.15 (PB5)
unnamed: J4.5, U1.14 (PB4)
unnamed: J4.6, U1.13 (PB3)
unnamed: J4.7, U1.12 (PB2)
unnamed: J4.8, U1.11 (PB1)
unnamed: J4.9, U1.10 (PB0)
unnamed: J5.2, U1.19 (CB2)
unnamed: J5.3, U1.18 (CB1)
unnamed: J5.4, U1.39 (CA2)
unnamed: J5.5, U1.40 (CA1)
unnamed: JP11.2 (C), U2.18 (CB1)
unnamed: JP12.2 (C), U1.21 (~IRQ)
unnamed: U1.24 (CS1), U3.8
unnamed: U2.9 (PA7), U13.1 (A0)
unnamed: U2.8 (PA6), U13.2 (A1)
unnamed: U2.7 (PA5), U13.3 (A2)
VCC: C2.1, C11.1, C12.1, C13.1, C16.1, J5.1, J6.1, U1.20 (VCC), U2.20 (VCC), U3.14 (VCC), U5.14 (VCC), U13.6 (E3), U13.16 (VCC); also elsewhere on the board


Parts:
C14: 100nf; C_Disc_D3.8mm_W2.6mm_P2.50mm
C15: 100nf; C_Radial_D4.0mm_H5.0mm_P1.50mm
J8: SD-Card module; PinHeader_1x08_P2.54mm_Vertical
J9: SD_Card; SD_Kyocera_145638109511859+
JP13: SD-Card voltage select; SolderJumper-3_P1.3mm_Open_Pad1.0x1.5mm
R6: 220R; R_Axial_DIN0204_L3.6mm_D1.6mm_P5.08mm_Horizontal
R7: 370R; R_Axial_DIN0204_L3.6mm_D1.6mm_P5.08mm_Horizontal
U12: 74HC541; DIP-20_W7.62mm
U14: LM317L_TO92; TO-92_Inline

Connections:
+3.3V: C15.1, J9.4 (VDD), JP13.3 (B), R6.2, U12.20 (VCC), U14.2 (VO)
/SD-Card/CardDetect: U12.6 (A4)
/SD-Card/SD_CLK: J8.4, J9.5 (CLK), U12.16 (Y2)
/SD-Card/SD_CS: J8.3, J9.1 (CD/DAT3), U12.18 (Y0)
/SD-Card/SD_CardDetect: J8.2, J9.10 (CARD_DETECT), U12.14 (Y4)
/SD-Card/SD_SDI: J8.5, J9.7 (DAT0), U12.5 (A3)
/SD-Card/SD_SDO: J8.6, J9.2 (CMD), U12.17 (Y1)
/SD-Card/SD_WriteProtect: J8.7, J9.11 (WRITE_PROTECT), U12.13 (Y5)
/SD-Card/WriteProtect: U12.7 (A5); also elsewhere on the board
/SD-Card/~CS: U12.2 (A0); also elsewhere on the board
/SPI_CLK: U12.4 (A2); also elsewhere on the board
/SPI_MISO: U12.15 (Y3); also elsewhere on the board
/SPI_MOSI: U12.3 (A1); also elsewhere on the board
GND: C14.2, C15.2, J8.1, J9.3 (VSS), J9.6 (VSS), J9.12 (SHELL1), J9.13 (SHELL2), R7.1, U12.1 (G1), U12.8 (A6), U12.9 (A7), U12.10 (GND), U12.19 (G2); also elsewhere on the board
unnamed: J8.8, JP13.2 (C)
unnamed: R6.1, R7.2, U14.1 (ADJ)
VCC: C14.1, JP13.1 (A), U14.3 (VI); also elsewhere on the board

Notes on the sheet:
VOUT = 1.25 * ( 1 + R2/R1 )
3.3 ~ 1.25 * ( 1 + 370/220 )


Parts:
C18: 100nf; C_Radial_D5.0mm_H7.0mm_P2.00mm
J2: Conn_02x25_Odd_Even; PinHeader_2x25_P2.54mm_Vertical
JP1, JP2, JP3, JP4, JP5, JP6, JP7, JP8: SolderJumper_2_Open; SolderJumper-2_P1.3mm_Open_RoundedPad1.0x1.5mm

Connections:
/Clock: J2.39; also elsewhere on the board
/Expansion header/A0: J2.5; also elsewhere on the board
/Expansion header/A1: J2.7; also elsewhere on the board
/Expansion header/A2: J2.9; also elsewhere on the board
/Expansion header/A3: J2.11; also elsewhere on the board
/Expansion header/A4: J2.13; also elsewhere on the board
/Expansion header/A5: J2.15
/Expansion header/A6: J2.17
/Expansion header/A7: J2.19
/Expansion header/A8: J2.21
/Expansion header/A9: J2.23
/Expansion header/A10: J2.25
/Expansion header/A11: J2.27
/Expansion header/A12: J2.29
/Expansion header/A13: J2.31
/Expansion header/A14: J2.33
/Expansion header/A15: J2.35
/Expansion header/AudioL: J2.47
/Expansion header/AudioR: J2.49
/Expansion header/D0: J2.4; also elsewhere on the board
/Expansion header/D1: J2.6; also elsewhere on the board
/Expansion header/D2: J2.8; also elsewhere on the board
/Expansion header/D3: J2.10; also elsewhere on the board
/Expansion header/D4: J2.12; also elsewhere on the board
/Expansion header/D5: J2.14; also elsewhere on the board
/Expansion header/D6: J2.16; also elsewhere on the board
/Expansion header/D7: J2.18; also elsewhere on the board
/Expansion header/~DMA: J2.43
/Expansion header/~ExtRomCs: J2.48
/R~W: J2.41; also elsewhere on the board
/~CS: JP1.2 (B), JP2.2 (B), JP3.2 (B), JP4.2 (B), JP5.2 (B), JP6.2 (B), JP7.2 (B), JP8.2 (B); also elsewhere on the board
/~IRQ: J2.44; also elsewhere on the board
/~NMI: J2.42; also elsewhere on the board
/~RST: J2.40; also elsewhere on the board
GND: C18.2, J2.2, J2.3, J2.20, J2.37, J2.38, J2.45, J2.46; also elsewhere on the board
unnamed: J2.22, JP1.1 (A)
unnamed: J2.24, JP2.1 (A)
unnamed: J2.26, JP3.1 (A)
unnamed: J2.28, JP4.1 (A)
unnamed: J2.30, JP5.1 (A)
unnamed: J2.32, JP6.1 (A)
unnamed: J2.34, JP7.1 (A)
unnamed: J2.36, JP8.1 (A)
VCC: C18.1, J2.1, J2.50; also elsewhere on the board


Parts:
C1, C3, C4: 100nf; C_Disc_D3.8mm_W2.6mm_P2.50mm
D1: 1N457; D_DO-35_SOD27_P7.62mm_Horizontal
J1: PS2; Connector_Mini-DIN_Female_6Pin_2rows
JP9: Enable PS2 Output; PinHeader_1x02_P2.54mm_Vertical
R1: 33k; R_Axial_DIN0204_L3.6mm_D1.6mm_P5.08mm_Horizontal
R2: 10k; R_Axial_DIN0204_L3.6mm_D1.6mm_P5.08mm_Horizontal
U3: 74HCT14; DIP-14_W7.62mm
U6, U7: 74HCT595; DIP-16_W7.62mm

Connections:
/PS2 keyboard interface/KeyPresent: U3.6, U6.12 (RCLK), U7.12 (RCLK); also elsewhere on the board
/PS2 keyboard interface/KeyboardBit0: U6.1 (QB); also elsewhere on the board
/PS2 keyboard interface/KeyboardBit1: U6.2 (QC); also elsewhere on the board
/PS2 keyboard interface/KeyboardBit2: U6.3 (QD); also elsewhere on the board
/PS2 keyboard interface/KeyboardBit3: U6.4 (QE); also elsewhere on the board
/PS2 keyboard interface/KeyboardBit4: U6.5 (QF); also elsewhere on the board
/PS2 keyboard interface/KeyboardBit5: U6.6 (QG); also elsewhere on the board
/PS2 keyboard interface/KeyboardBit6: U6.7 (QH); also elsewhere on the board
/PS2 keyboard interface/KeyboardBit7: U7.15 (QA); also elsewhere on the board
/PS2 keyboard interface/KeyboardData: J1.1, U6.14 (SER)
/PS2 keyboard interface/~KeyboardClk: U3.4, U6.11 (SRCLK), U7.11 (SRCLK)
/PS2 keyboard interface/~PS2ShiftOE: JP9.1 (A), R2.2, U6.13 (~OE), U7.13 (~OE)
GND: C1.2, C3.2, C4.2, J1.3, JP9.2 (B), U6.8 (GND), U7.8 (GND); also elsewhere on the board
unnamed: D1.2 (A), R1.2, U3.2
unnamed: C1.1, D1.1 (K), R1.1, U3.5
unnamed: J1.5, U3.1, U3.3
unnamed: U6.9 (QH'), U7.14 (SER)
VCC: C3.1, C4.1, J1.4, R2.1, U6.10 (~SRCLR), U6.16 (VCC), U7.10 (~SRCLR), U7.16 (VCC); also elsewhere on the board

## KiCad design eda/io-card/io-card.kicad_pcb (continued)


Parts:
C5: 220nf; C_Radial_D4.0mm_H5.0mm_P1.50mm
C6, C7, C8, C9, C10: 100nf; C_Disc_D3.8mm_W2.6mm_P2.50mm
J7: Keyboard connector; PinHeader_2x10_P2.54mm_Horizontal
JP10: Enable Scanning Keyboard Output; PinHeader_1x02_P2.54mm_Vertical
R3: 1.5k; R_Axial_DIN0204_L3.6mm_D1.6mm_P5.08mm_Horizontal
R4: 22k; R_Axial_DIN0204_L3.6mm_D1.6mm_P5.08mm_Horizontal
R5: 10k; R_Axial_DIN0204_L3.6mm_D1.6mm_P5.08mm_Horizontal
U4: NE555P; DIP-8_W7.62mm
U5: 74HCT00; DIP-14_W7.62mm
U8: 74HCT138; DIP-16_W7.62mm
U9: 74HCT148; DIP-16_W7.62mm
U10: 74HCT193; DIP-16_W7.62mm
U15: 74HCT574; DIP-20_W7.62mm

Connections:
/PS2 keyboard interface/KeyboardBit0: U15.19 (Q0); also elsewhere on the board
/PS2 keyboard interface/KeyboardBit1: U15.18 (Q1); also elsewhere on the board
/PS2 keyboard interface/KeyboardBit2: U15.17 (Q2); also elsewhere on the board
/PS2 keyboard interface/KeyboardBit3: U15.16 (Q3); also elsewhere on the board
/PS2 keyboard interface/KeyboardBit4: U15.15 (Q4); also elsewhere on the board
/PS2 keyboard interface/KeyboardBit5: U15.14 (Q5); also elsewhere on the board
/PS2 keyboard interface/KeyboardBit6: U15.13 (Q6); also elsewhere on the board
/PS2 keyboard interface/KeyboardBit7: U15.12 (Q7); also elsewhere on the board
/Scanning keyboard interface/KeyPresent: U5.3; also elsewhere on the board
/Scanning keyboard interface/KeyboardScanClock: U4.3 (Q), U5.2, U10.4 (DOWN)
/Scanning keyboard interface/Scancode0: U8.1 (A0), U10.3 (QA), U15.7 (D5)
/Scanning keyboard interface/Scancode1: U8.2 (A1), U10.2 (QB), U15.6 (D4)
/Scanning keyboard interface/Scancode2: U8.3 (A2), U10.6 (QC), U15.5 (D3)
/Scanning keyboard interface/Scancode3: U9.9 (S0), U15.2 (D0)
/Scanning keyboard interface/Scancode4: U9.7 (S1), U15.3 (D1)
/Scanning keyboard interface/Scancode5: U9.6 (S2), U15.4 (D2)
/Scanning keyboard interface/col0: J7.3, U8.15 (O0)
/Scanning keyboard interface/col1: J7.5, U8.14 (O1)
/Scanning keyboard interface/col2: J7.7, U8.13 (O2)
/Scanning keyboard interface/col3: J7.9, U8.12 (O3)
/Scanning keyboard interface/col4: J7.11, U8.11 (O4)
/Scanning keyboard interface/col5: J7.13, U8.10 (O5)
/Scanning keyboard interface/col6: J7.15, U8.9 (O6)
/Scanning keyboard interface/col7: J7.17, U8.7 (O7)
/Scanning keyboard interface/mod0: J7.2, U15.9 (D7)
/Scanning keyboard interface/mod1: J7.19, U15.8 (D6)
/Scanning keyboard interface/row0: J7.18, U9.10 (IO)
/Scanning keyboard interface/row1: J7.16, U9.11 (I1)
/Scanning keyboard interface/row2: J7.14, U9.12 (I2)
/Scanning keyboard interface/row3: J7.12, U9.13 (I3)
/Scanning keyboard interface/row4: J7.10, U9.4 (I7)
/Scanning keyboard interface/row5: J7.8, U9.3 (I6)
/Scanning keyboard interface/row6: J7.6, U9.2 (I5)
/Scanning keyboard interface/row7: J7.4, U9.1 (I4)
GND: C5.2, C6.2, C7.2, C8.2, C9.2, C10.2, J7.20, JP10.2 (B), U4.1 (GND), U8.4 (E1), U8.5 (E2), U8.8 (GND), U9.5 (EI), U9.8 (GND), U10.8 (GND), U10.10 (C), U10.14 (CLR), U15.10 (GND); also elsewhere on the board
unnamed: JP10.1 (A), R5.2, U15.1 (OE)
unnamed: C6.1, U4.5 (CV)
unnamed: R3.2, R4.1, U4.7 (DIS)
unnamed: C5.1, R4.2, U4.2 (TR), U4.6 (THR)
unnamed: U5.1, U9.15 (EO)
unnamed: U10.11 (~LOAD), U10.13 (~BO)
unnamed: U9.14 (GS), U15.11 (Cp)
VCC: C7.1, C8.1, C9.1, C10.1, J7.1, R3.1, R5.1, U4.4 (R), U4.8 (VCC), U8.6 (E3), U8.16 (VCC), U9.16 (VCC), U10.1 (B), U10.9 (D), U10.15 (A), U10.16 (VCC), U15.20 (VCC); also elsewhere on the board

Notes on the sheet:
Should this be an AND gate?



Board: 2 copper layers, 230.0 x 100.0 mm, 67 parts (8 on the bottom side), 125 nets.

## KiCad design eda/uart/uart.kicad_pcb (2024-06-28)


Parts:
C1, C2, C15, C18, C19, C21, C22: 0.1uf; C_Disc_D3.8mm_W2.6mm_P2.50mm
H3, H4, H5, H6: MountingHole_Pad; MountingHole_2.5mm_Pad_Via
J1: RX/TX Con; PinHeader_1x04_P2.54mm_Horizontal
JP9: IRQ Disconnect; PinHeader_1x02_P2.54mm_Vertical
U1: 74HCT08; DIP-14_W7.62mm
U2: 74HCT14; DIP-14_W7.62mm
U7: 74HCT139; DIP-16_W7.62mm
U10: 74HCT574; DIP-20_W7.62mm
U15: 74HCT00; DIP-14_W7.62mm
U16: 74HCT74; DIP-14_W10.16mm
U18: 74HCT32; DIP-14_W7.62mm
U19: 74HCT74; DIP-14_W7.62mm

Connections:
/Expansion header/Clock: U7.14 (A0); also elsewhere on the board
/Expansion header/D0: U10.19 (Q0); also elsewhere on the board
/Expansion header/D1: U10.18 (Q1); also elsewhere on the board
/Expansion header/D2: U10.17 (Q2); also elsewhere on the board
/Expansion header/D3: U10.16 (Q3); also elsewhere on the board
/Expansion header/D4: U10.15 (Q4); also elsewhere on the board
/Expansion header/D5: U10.14 (Q5); also elsewhere on the board
/Expansion header/D6: U10.13 (Q6); also elsewhere on the board
/Expansion header/D7: U10.12 (Q7); also elsewhere on the board
/Expansion header/~IRQ: JP9.1 (A); also elsewhere on the board
/Expansion header/~RST: U2.5; also elsewhere on the board
/address_decode/IrqActive: U15.5; also elsewhere on the board
/address_decode/~DeviceEnable: U19.13 (~R); also elsewhere on the board
/address_decode/~StatusEnable: U10.1 (OE); also elsewhere on the board
/recieve/DataAvailable: U1.11, U10.9 (D7), U15.4
/recieve/RX: J1.2; also elsewhere on the board
/recieve/RecieveBufferFull: U1.8, U10.2 (D0)
/recieve/Reset: U2.6; also elsewhere on the board
/transmit/InputBufferFull: U10.8 (D6); also elsewhere on the board
/transmit/TX: J1.3; also elsewhere on the board
GND: C1.2, C2.2, C15.2, C18.2, C19.2, C21.2, C22.2, H3.1, H4.1, H5.1, H6.1, J1.4, U1.7 (GND), U2.7 (GND), U7.13 (A1), U7.15 (E), U10.4 (D2), U10.5 (D3), U10.6 (D4), U10.7 (D5), U10.10 (GND), U15.7 (GND), U16.7 (GND), U18.7 (GND), U18.9, U18.10, U18.12, U18.13, U19.7 (GND), U19.11 (C), U19.12 (D); also elsewhere on the board
unnamed: JP9.2 (B), U19.8 (~Q)
unnamed: U7.11 (O1), U10.11 (Cp)
unnamed: U10.3 (D1), U19.9 (Q)
unnamed 91: U1.10; also elsewhere on the board
unnamed 92: U1.12; also elsewhere on the board
unnamed 93: U1.9; also elsewhere on the board
unnamed 94: U1.13; also elsewhere on the board
unnamed: U15.6, U19.10 (~S)
VCC: C1.1, C2.1, C15.1, C18.1, C19.1, C21.1, C22.1, U1.14 (VCC), U2.14 (VCC), U10.20 (VCC), U15.14 (VCC), U16.14 (VCC), U18.14 (VCC), U19.14 (VCC); also elsewhere on the board


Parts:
C18: 100nf; C_Radial_D5.0mm_H7.0mm_P2.00mm
J2: Conn_02x25_Odd_Even; PinHeader_2x25_P2.54mm_Vertical
JP1, JP2, JP3, JP4, JP5, JP6, JP7, JP8: SolderJumper_2_Open; SolderJumper-2_P1.3mm_Open_RoundedPad1.0x1.5mm

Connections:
/Expansion header/A0: J2.5; also elsewhere on the board
/Expansion header/A1: J2.7; also elsewhere on the board
/Expansion header/A2: J2.9
/Expansion header/A3: J2.11
/Expansion header/A4: J2.13
/Expansion header/A5: J2.15
/Expansion header/A6: J2.17
/Expansion header/A7: J2.19
/Expansion header/A8: J2.21
/Expansion header/A9: J2.23
/Expansion header/A10: J2.25
/Expansion header/A11: J2.27
/Expansion header/A12: J2.29
/Expansion header/A13: J2.31
/Expansion header/A14: J2.33
/Expansion header/A15: J2.35
/Expansion header/AudioL: J2.47
/Expansion header/AudioR: J2.49
/Expansion header/Clock: J2.39; also elsewhere on the board
/Expansion header/D0: J2.4; also elsewhere on the board
/Expansion header/D1: J2.6; also elsewhere on the board
/Expansion header/D2: J2.8; also elsewhere on the board
/Expansion header/D3: J2.10; also elsewhere on the board
/Expansion header/D4: J2.12; also elsewhere on the board
/Expansion header/D5: J2.14; also elsewhere on the board
/Expansion header/D6: J2.16; also elsewhere on the board
/Expansion header/D7: J2.18; also elsewhere on the board
/Expansion header/R~W: J2.41; also elsewhere on the board
/Expansion header/~CS: JP1.2 (B), JP2.2 (B), JP3.2 (B), JP4.2 (B), JP5.2 (B), JP6.2 (B), JP7.2 (B), JP8.2 (B); also elsewhere on the board
/Expansion header/~DMA: J2.43
/Expansion header/~ExtRomCs: J2.48
/Expansion header/~IRQ: J2.44; also elsewhere on the board
/Expansion header/~NMI: J2.42
/Expansion header/~RST: J2.40; also elsewhere on the board
GND: C18.2, J2.2, J2.3, J2.20, J2.37, J2.38, J2.45, J2.46; also elsewhere on the board
unnamed: J2.22, JP1.1 (A)
unnamed: J2.24, JP2.1 (A)
unnamed: J2.26, JP3.1 (A)
unnamed: J2.28, JP4.1 (A)
unnamed: J2.30, JP5.1 (A)
unnamed: J2.32, JP6.1 (A)
unnamed: J2.34, JP7.1 (A)
unnamed: J2.36, JP8.1 (A)
VCC: C18.1, J2.1, J2.50; also elsewhere on the board

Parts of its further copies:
C3: 100nf; C_Radial_D5.0mm_H7.0mm_P2.00mm

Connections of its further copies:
GND: C3.2; also elsewhere on the board
VCC: C3.1; also elsewhere on the board


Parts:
C4, C5: 22pf; C_Disc_D3.8mm_W2.6mm_P2.50mm
C6, C23: 0.1uf; C_Disc_D3.8mm_W2.6mm_P2.50mm
U3, U20: 74HCT193; DIP-16_W7.62mm
U16: 74HCT74; DIP-14_W10.16mm
X1: 1.8xx; Oscillator_DIP-14

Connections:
/clock/UartClock: U16.9 (Q); also elsewhere on the board
/clock/UartRecieveClock: U20.7 (QD); also elsewhere on the board
/clock/~InRecieveMode: U20.14 (CLR); also elsewhere on the board
GND: C5.2, C6.2, C23.2, U3.1 (B), U3.8 (GND), U3.10 (C), U3.14 (CLR), U3.15 (A), U20.8 (GND), X1.7 (GND); also elsewhere on the board
unnamed: U3.11 (~LOAD), U3.13 (~BO), U16.11 (C)
unnamed: U16.8 (~Q), U16.12 (D)
unnamed: C4.2, C5.1, U3.4 (DOWN), U20.5 (UP), X1.8 (OUT)
VCC: C4.1, C6.1, C23.1, U3.9 (D), U3.16 (VCC), U16.10 (~S), U16.13 (~R), U20.1 (B), U20.4 (DOWN), U20.9 (D), U20.10 (C), U20.11 (~LOAD), U20.15 (A), U20.16 (VCC), X1.14 (Vcc); also elsewhere on the board


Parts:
C7, C8, C9: 0.1uf; C_Disc_D3.8mm_W2.6mm_P2.50mm
U4: 74HCT193; DIP-16_W7.62mm
U5, U6: 74HCT165; DIP-16_W7.62mm
U16: 74HCT74; DIP-14_W10.16mm

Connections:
/clock/UartClock: U4.4 (DOWN), U5.2 (CP), U6.2 (CP), U16.3 (C); also elsewhere on the board
/transmit/FIFO Transmit/DOR: U16.2 (D); also elsewhere on the board
/transmit/FIFO Transmit/Q0: U5.4 (D5); also elsewhere on the board
/transmit/FIFO Transmit/Q1: U5.3 (D4); also elsewhere on the board
/transmit/FIFO Transmit/Q2: U5.14 (D3); also elsewhere on the board
/transmit/FIFO Transmit/Q3: U5.13 (D2); also elsewhere on the board
/transmit/FIFO Transmit/Q4: U5.12 (D1); also elsewhere on the board
/transmit/FIFO Transmit/Q5: U5.11 (D0); also elsewhere on the board
/transmit/FIFO Transmit/Q6: U6.6 (D7); also elsewhere on the board
/transmit/FIFO Transmit/Q7: U6.5 (D6); also elsewhere on the board
/transmit/TX: U5.9 (Q7); also elsewhere on the board
/transmit/~ClockEnable: U5.15 (~CE), U6.15 (~CE), U16.6 (~Q)
/transmit/~LatchShiftRegisters: U4.11 (~LOAD), U5.1 (~PL), U6.1 (~PL), U16.5 (Q); also elsewhere on the board
GND: C7.2, C8.2, C9.2, U4.1 (B), U4.8 (GND), U4.14 (CLR), U4.15 (A), U5.5 (D6), U5.8 (GND), U6.8 (GND); also elsewhere on the board
unnamed: U5.10 (DS), U6.9 (Q7)
unnamed: U4.13 (~BO), U16.1 (~R)
VCC: C7.1, C8.1, C9.1, U4.5 (UP), U4.9 (D), U4.10 (C), U4.16 (VCC), U5.6 (D7), U5.16 (VCC), U6.3 (D4), U6.4 (D5), U6.10 (DS), U6.11 (D0), U6.12 (D1), U6.13 (D2), U6.14 (D3), U6.16 (VCC), U16.4 (~S); also elsewhere on the board


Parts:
C10: 0.1uf; C_Disc_D3.8mm_W2.6mm_P2.50mm
U2: 74HCT14; DIP-14_W7.62mm
U7: 74HCT139; DIP-16_W7.62mm
U15: 74HCT00; DIP-14_W7.62mm
U18: 74HCT32; DIP-14_W7.62mm
U19: 74HCT74; DIP-14_W7.62mm
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

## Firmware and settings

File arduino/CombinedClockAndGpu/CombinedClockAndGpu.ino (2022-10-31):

#define CLOCK_IN 2
#define CLOCK_OUT 3

#define READ_WRITE 4
#define AUTO_CLOCK 5
#define SINGLE_STEP_CLOCK 6
#define GPU_CS 7
#define MODE 8

//const char ADDR[] = {22, 24, 26, 28, 30, 32, 34, 36, 38, 40, 42, 44, 46, 48, 50, 52};
const char ADDR[] = {52, 50, 48, 46, 44, 42, 40, 38, 36, 34, 32, 30, 28, 26, 24, 22};

//const char DATA[] = {39, 41, 43, 45, 47, 49, 51, 53};
const char DATA[] = {53, 51, 49, 47, 45, 43, 41, 39};

char mode = 0;

void setup() {
  pinMode(READ_WRITE, INPUT);
  pinMode(CLOCK_IN, INPUT);
  pinMode(GPU_CS, INPUT);
  pinMode(CLOCK_OUT, OUTPUT);
  pinMode(MODE, INPUT);
  pinMode(AUTO_CLOCK, INPUT);
  pinMode(SINGLE_STEP_CLOCK, INPUT);

  for(int n = 0; n < 6; n++)
  {
    pinMode(ADDR[n], INPUT);  
  }

  resetDatabus();

  Serial.begin(115200);

  mode = digitalRead(MODE);

  if(mode == HIGH)
    setupGPU();
  else
    setupClock();
}

void loop() {
  if(mode == HIGH)
    loopGPU();


   loopClock();
}

/// CLOCK ////

void setupClock() {
  attachInterrupt(digitalPinToInterrupt(CLOCK_IN), readBusesClock, RISING);
  Serial.println("Bus monitor activated");
}


void loopClock() {
  if(digitalRead(AUTO_CLOCK) == 1){
    emitPulse();
    delay(1);            
  }else if(digitalRead(SINGLE_STEP_CLOCK) == 1){
      emitPulse();
      delay(300);  
  }
}

void emitPulse(){
  digitalWrite(CLOCK_OUT, HIGH);   
  delay(1);                    
  digitalWrite(CLOCK_OUT, LOW);   
}

void readBusesClock(){
  char output[15];

  unsigned int address = 0;
  for (int n = 0; n < 16; n += 1) {
    int bit = digitalRead(ADDR[n]) ? 1 : 0;
    Serial.print(bit);
    address = (address << 1) + bit;
  }
  
  Serial.print("   ");
  
  unsigned int data = 0;
  for (int n = 0; n < 8; n += 1) {
    int bit = digitalRead(DATA[n]) ? 1 : 0;
    Serial.print(bit);
    data = (data << 1) + bit;
  }

  sprintf(output, "   %04x  %c %02x", address, digitalRead(READ_WRITE) ? 'r' : 'W', data);
  Serial.println(output);  
}

/// GPU ////

unsigned int col = 0;
unsigned int row = 0;

unsigned int registers[] = {0, 0, 0, 1, 0, 0xC0, 0};

const char sendBuffer[10][15] = {};
unsigned int currentSend = 0;
unsigned int currentWrite = 0;

void setupGPU() {
  resetDatabus();

  attachInterrupt(digitalPinToInterrupt(GPU_CS), readBusesGPU, FALLING);
  //attachInterrupt(digitalPinToInterrupt(GPU_CS), resetDatabus, RISING);

  Serial.println("GPU mode activated");
}

void loopGPU() {
  // put your main code here, to run repeatedly:
  if(currentSend != currentWrite) {
    currentSend = (currentSend + 1) % 10;
    Serial.write(sendBuffer[currentSend]);
  }
}

void resetDatabus() {
  for(int x = 0; x < 8; x++){
    pinMode(DATA[x], INPUT);
  }
}

void readBusesGPU(){  
  unsigned int address = 0;
  for (int n = 0; n < 6; n += 1) {
    int bit = digitalRead(ADDR[n]) ? 1 : 0;
    address = (address << 1) + bit;
  }
  
  if(digitalRead(READ_WRITE) == HIGH){
    Serial.print("R ");
    Serial.println(address, HEX);
    // Read operation 
    if(address == 6) {
      output(0); // No real VRAM to read from
    }else{
      output(registers[address % 6]);
    } 
  }else{
    // Write operation  
    unsigned int data = 0;
    for (int n = 0; n < 8; n += 1) {
      int bit = digitalRead(DATA[n]) ? 1 : 0;
      data = (data << 1) + bit;
    }

    // Serial.print("W ");
    // Serial.print(address, HEX);
    // Serial.print(", ");
    // Serial.println(data, HEX);

    if(address == 6) {
      unsigned int memoryAddress = getMemoryAddress();

      if(memoryAddress >= 0xC000 && memoryAddress <= 0xD2C0) {
        // In the framebuffer region
        memoryAddress -= 0xC000;

        unsigned int writeCol = memoryAddress % 80;
        unsigned int writeRow = memoryAddress / 80;

        int tempCurrentSend = (currentSend + 1) % 10;

        if(writeRow != row || writeCol != col + 1) {
          // We have moved.. need to set cursor position
          // Serial.write(0x1B);
          // Serial.print("[");
          // Serial.print(writeRow);
          // Serial.print(";");
          // Serial.print(writeCol);
          // Serial.print("H");

          tempCurrentSend = (currentSend + 1) % 10;
          sprintf(sendBuffer[tempCurrentSend], "%c[%i;%iH", 0x1B, writeRow, writeCol);
          
        }  

        sprintf(sendBuffer[tempCurrentSend], "%c", data);
        currentSend = tempCurrentSend;
        
        // Serial.write(data);

        col = writeCol;
        row = writeRow;
      }

      registers[4] += registers[6];
      if(registers[4] >= 256) {
        registers[4] -= 255;
        registers[5]++;  
      }
    }else{
      registers[address % 6] = data;  

      char output[20];
      sprintf(output, "Got register write  %04x  %02x", address, data);
      Serial.println(output); 
    }
  }
}

void output(unsigned int data) {
  //  int tempCurrentSend = (currentSend + 1) % 10;
  //  sprintf(sendBuffer[tempCurrentSend], "Attempting to output %02x", data);
  //  currentSend = tempCurrentSend;
  
  // for(int x = 0; x < 8; x++){
  //   pinMode(DATA[x], OUTPUT);
  //   digitalWrite(DATA[x], (data << x) & 1 ? HIGH : LOW);
  // }
}

unsigned int getMemoryAddress() {
  return (registers[5] << 8) + registers[4];
}

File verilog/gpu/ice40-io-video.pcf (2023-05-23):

set_io data[0] 1
set_io data[1] 2
set_io data[2] 3
set_io data[3] 4
set_io data[4] 7
set_io data[5] 8
set_io data[6] 9
set_io data[7] 10

set_io addr[0] 12 
set_io cpu_clk 13

set_io CLK100MHz 15
set_io addr[1] 16
set_io addr[2] 18

set_io rw 19
set_io -pullup yes cs 20
set_io -pullup yes rst 21

set_io vga_hs 24
set_io vga_vs 25

set_io vga_r[0] 26
set_io vga_r[1] 27
set_io vga_r[2] 28

set_io vga_g[0] 29
set_io vga_g[1] 30
set_io vga_g[2] 33

set_io vga_b[0] 34
set_io vga_b[1] 36
set_io vga_b[2] 37

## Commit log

2022-03-03 Initial work on bank switch
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2022-04-17 Add initial support for SPI
2022-04-19 Spi communication seems to work
2022-04-21 SPI sd card communication interim commit
2022-06-03 Add fake gpu implementation for arduino
2023-03-28 Add eda folder for kicad
    [project-wrass.kicad_pcb, project-wrass.kicad_sch]
2023-03-28 Add first draft for uart
    [expansion-header.kicad_sch, project-wrass.kicad_pcb, project-wrass.kicad_sch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]
2023-03-29 More work on UART
    [address-decode.kicad_sch, clock.kicad_sch, expansion-header.kicad_sch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]
2023-03-31 Port main board schematic to kicad
    [address-decode.kicad_sch, clock.kicad_sch, expansion-header.kicad_sch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]
2023-04-07 Work on main board eda, interim
    [address-decode.kicad_sch, expansion-header.kicad_sch, fifo.kicad_sch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]
2023-04-07 GPU routing
    [fpga_gpu.kicad_pcb, fpga_gpu.kicad_sch, interfacing.kicad_sch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]
2023-04-09 More routing on the GPU board
    [expansion-header.kicad_sch, fpga_gpu.kicad_pcb, fpga_gpu.kicad_sch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]
2023-05-06 Update eda
    [address-decode.kicad_sch, expansion-header.kicad_sch, fpga_gpu.kicad_pcb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]
2023-05-07 Convert expansion breakout to kicad
    [address-decode.kicad_sch, expansion-breakout.kicad_pcb, expansion-breakout.kicad_sch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]
2023-05-07 Add skeleton stuff to io-card and gpu
    [fpga_gpu.kicad_pcb, fpga_gpu.kicad_sch, io-card.kicad_pcb]
2023-05-12 Add expansion backplane
    [13x2_female_header.STEP, expansion-backplane.kicad_pcb, expansion-backplane.kicad_sch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]
2023-05-16 Add audio card
    [audio-card.kicad_pcb, audio-card.kicad_sch, channel.kicad_sch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]
2023-05-23 Change pinout to not use expansion board
2023-07-07 Interim commit
    [audio-card.kicad_pcb, audio-card.kicad_sch, channel.kicad_sch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]
2023-07-07 Text output subsystem now supports multiple active devices
2023-07-07 Update location of UART
2023-07-08 Update cap footprint
    [expansion-backplane.kicad_pcb, expansion-backplane.kicad_sch, outputs.kicad_sch]
2023-07-20 Update UART transmit logic
    [clock.kicad_sch, recieve.kicad_sch, transmit.kicad_sch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]
2023-07-20 Prelimary UART routing
    [address-decode.kicad_sch, uart.kicad_pcb, uart.kicad_sch]
2023-07-22 Start converting audio card to analog synth base
    [audio-card.kicad_pcb, audio-card.kicad_sch, channel.kicad_sch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]
2024-01-07 EDA work for new expansion header
    [13x2_female_header.STEP, address-decode.kicad_sch, expansion-header.kicad_sch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]
2024-01-27 Branch of uart to v1
    [address-decode.kicad_sch, clock.kicad_sch, expansion_skeleton.kicad_pcb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]
2024-01-27 Generate step files and start on gpu for new board layout
    [audio.kicad_sch, expansion-header.kicad_sch, fpga_gpu.kicad_pcb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]
2024-01-28 Normalize cap size
    [address-decode.kicad_sch, clock.kicad_sch, expansion-header.kicad_sch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]
2024-02-02 Add uart to simulator
2024-02-15 Add serial terminal to simulator and uart read/write support for chars in monitor
2024-03-04 Uart and loader work
    [address-decode.kicad_sch, clock.kicad_sch, expansion-header.kicad_sch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]
2024-03-15 Uart eda work
    [address-decode.kicad_sch, recieve.kicad_sch, transmit.kicad_sch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]
2024-03-15 UART routing pass 1
    [recieve.kicad_sch, uart.kicad_pcb, uart.kicad_sch]
2024-03-17 Add conversion board
    [expansion-40-to-50-conversion.kicad_pcb, expansion-40-to-50-conversion.kicad_sch, expansion-header.kicad_sch]
2024-03-17 Cleanup uart
    [uart.kicad_pcb]
2024-03-18 Check for UART recieve buffer overflow and set error flag
2024-03-18 fix(simulator): UART overflow on wrong bit in status
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2024-03-22 Rerouting IO card
    [47571-0001-with-sdcard.STEP, address-decode.kicad_sch, expansion.kicad_sch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]
2024-03-22 Add irq flag support to simulated uart
2024-03-29 Uart latch logic
    [uart.kicad_sch]
2024-03-29 Touchups before ordering
    [expansion-40-to-50-conversion.kicad_pcb, uart.kicad_pcb, uart.kicad_sch]
2024-06-28 Uart board to v1.1...make bodges permanent :(
    [clock.kicad_sch, recieve.kicad_sch, transmit.kicad_sch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]
2024-07-12 Work on SPI with actual hardware
    [io-card.kicad_pcb, io-card.kicad_sch]
2024-07-12 Update simulator to match new io card via assignment
    [io-card.kicad_sch]
2024-09-27 Bunch of strange SPI stuff
    [uart.kicad_sch]
2024-11-21 Mostly working SPI
    [address-decode.kicad_sch, expansion.kicad_sch, main-board.kicad_pcb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]
2025-03-03 Did stuff
    [address-decode.kicad_sch, expansion.kicad_sch, main-board.kicad_pcb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]
2025-03-04 Add SPI
    [address-decode.kicad_sch, clock.kicad_sch, expansion-header.kicad_sch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]
2025-03-04 Add address decode
    [io-card.kicad_sch, spi.kicad_sch]
2025-03-31 Add memcontrol display to panels
    [io-card.kicad_sch, spi.kicad_sch]
2025-04-21 Expose current scanline in register
2025-04-28 Bunch of work around SPI and SD card reading in simulator
    [main-board.kicad_pcb]
2025-05-03 Working on parsing cluster chain
2025-05-04 Directory enumeration now checks cluster chain in FAT
2025-05-20 fix: Traces straight over GND....
    [expansion.kicad_sch, main-board.kicad_pcb]
2025-07-09 fix: Issue on mainboard
    [main-board.kicad_sch]
2026-03-07 Add all in one board
    [13x2_female_header.STEP, 47571-0001-with-sdcard.STEP, address-decode.kicad_sch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]
2026-03-09 WIP: Implementing new SPI and IO card
    [spi.kicad_sch]
2026-03-20 Working on new SPI support
    [address-decode.kicad_sch, all-in-one-smc.kicad_sch, clock.kicad_sch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]
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2026-03-20 Fix faulty output from test assembly
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2026-03-23 Incorrect mode on SD card
    [all-in-one-smc.kicad_pcb]
2026-03-25 Revert back 80x60 characters display since the RPI Pico will have move vram
